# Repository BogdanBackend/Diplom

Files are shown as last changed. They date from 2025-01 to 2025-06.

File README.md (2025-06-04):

Автоматизований портативний комплекс виявлення та аналізу радіосигналів

---

A1:

* [Збірне креслення](pdf/A1/Assem.pdf)
* [Бокс креслення](pdf/A1/Box.pdf)
* [Електрична креслення](pdf/A1/CM5IO.pdf)
* [Експеремент плакат](pdf/A1/A1_experiment.drawio.pdf)
* [Плата плакат](pdf/A1/PCB.pdf)

A4:

* [Записка](pdf/doc.pdf)
* [Захис екрану креслення](pdf/A4/Top.pdf)
* [Захист роз'ємів креслення](pdf/A4/Cover.pdf)
* [Специфікація](pdf/A4/Специфікація.pdf)
* [Звіт плагіату](pdf/A4/Plagiarism.pdf)

---

# __[ЗМІСТ](docs/README.md)__

* [DOCx проміжковий файл розділів](docs/out/doc_dev.docx)

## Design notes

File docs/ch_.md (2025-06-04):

# ПЕРЕЛІК УМОВНИХ ПОЗНАЧЕНЬ ТА СКОРОЧЧЕНЬ

АПКВАР — автоматизований портативний комплекс виявлення та аналізу радіосигналів.

SDR (англ. *Software Defined Radio*) — програмно-визначуване радіо.

RF (англ. *Radio Frequency*) — радіочастота.

DSP (англ. *Digital Signal Processing*) — цифрова обробка сигналів.

FFT (англ. *Fast Fourier Transform*) — швидке перетворення Фур’є.

AGC (англ. *Automatic Gain Control*) — автоматичне регулювання підсилення.

ADC (англ. *Analog-to-Digital Converter*) — аналого-цифровий перетворювач.

DAC (англ. *Digital-to-Analog Converter*) — цифро-аналоговий перетворювач.

BMS (англ. *Battery Management System*) — система керування акумулятором.

Li-ion — літій-іонний акумулятор.

Li-Pol — літій-полімерний акумулятор.

GNSS (англ. *Global Navigation Satellite System*) — глобальна навігаційна супутникова система.

GPS (англ. *Global Positioning System*) — супутникова система позиціонування.

UART (англ. *Universal Asynchronous Receiver-Transmitter*) — універсальний асинхронний приймач-передавач.

I2C (англ. *Inter-Integrated Circuit*) — послідовний інтерфейс для зв'язку мікросхем.

SPI (англ. *Serial Peripheral Interface*) — серійний периферійний інтерфейс.

USB (англ. *Universal Serial Bus*) — універсальна послідовна шина.

HDMI (англ. *High-Definition Multimedia Interface*) — мультимедійний інтерфейс високої чіткості.

PCIe (англ. *Peripheral Component Interconnect Express*) — високошвидкісний інтерфейс підключення модулів.

M.2 компактний роз’єм для підключення накопичувачів, модулів Wi-Fi та ін..

SSD (англ. *Solid State Drive*) — твердотільний накопичувач.

SD карта пам’яті формату Secure Digital.

GPIO (англ. *General Purpose Input/Output*) — загальні виводи введення/виведення.

DSI (англ. *Display Serial Interface*) — інтерфейс підключення дисплеїв.

CSI (англ. *Camera Serial Interface*) — інтерфейс підключення камер.

PoE (англ. *Power over Ethernet*) — живлення через Ethernet-кабель.

ADS-B (англ. *Automatic Dependent Surveillance–Broadcast*) — авіаційна система спостереження.

ISM (англ. *Industrial, Scientific and Medical*) — безліцензійний радіочастотний діапазон.

TX (англ. *Transmit*) — передача сигналу.

RX (англ. *Receive*) — прийом сигналу.

IQ (англ. *In-phase and Quadrature*) — представлення сигналів у комплексній формі (реальна + уявна частина).

CW (англ. *Continuous Wave*) — неперервна хвиля (морзянка).

SSB (англ. *Single Side Band*) — односмугова модуляція.

AM (англ. *Amplitude Modulation*) — амплітудна модуляція.

FM (англ. *Frequency Modulation*) — частотна модуляція.

DC (англ. *Direct Current*) — постійний струм.

EMI (англ. *Electromagnetic Interference*) — електромагнітні завади.

PLD (англ. *Programmable Logic Device*) — програмований логічний пристрій.

FPGA (англ. *Field-Programmable Gate Array*) — програмована логічна матриця.

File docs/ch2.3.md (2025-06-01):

## Розробка електричної принципової схеми

В основі розроблюваної системи лежить процесорний модуль Raspberry Pi Compute Module 5. Цей модуль є центральним елементом, що забезпечує обробку даних та керування всіма функціями пристрою.

### Процесорний модуль та його інтерфейси:

Для розробки друкованої плати ніобхідно правильно викоритовувати ніжки процесорного модуля та розуміти його можливості. 

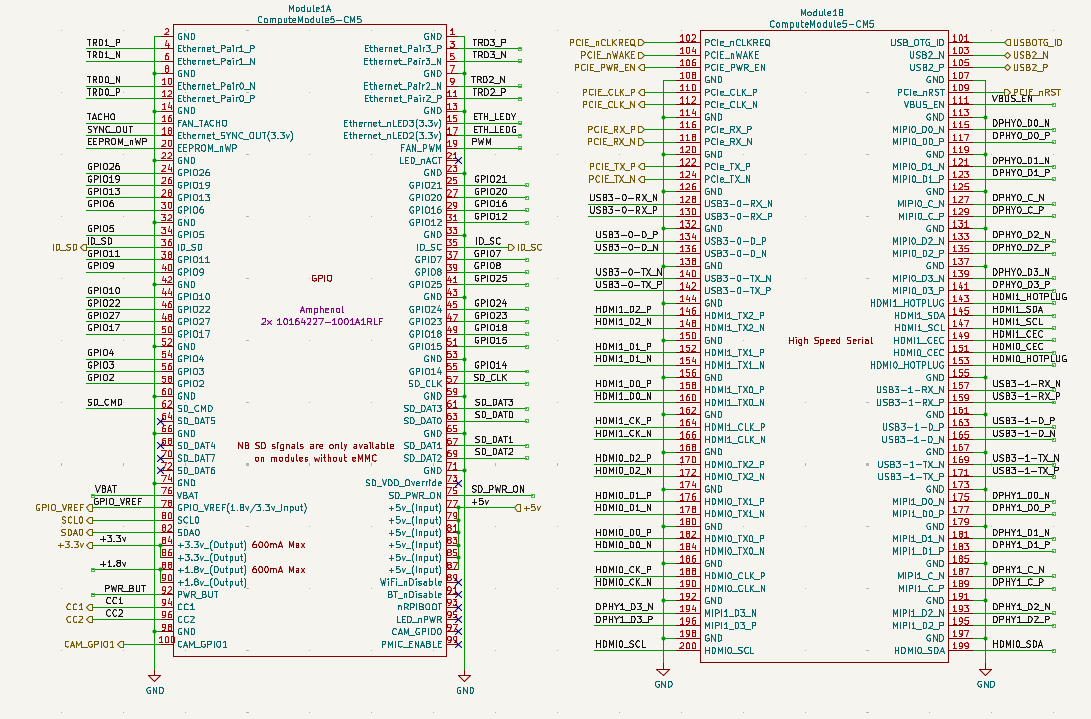
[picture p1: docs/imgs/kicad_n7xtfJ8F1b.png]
Ніжки процесорного модуля RPi Computer Module w=14


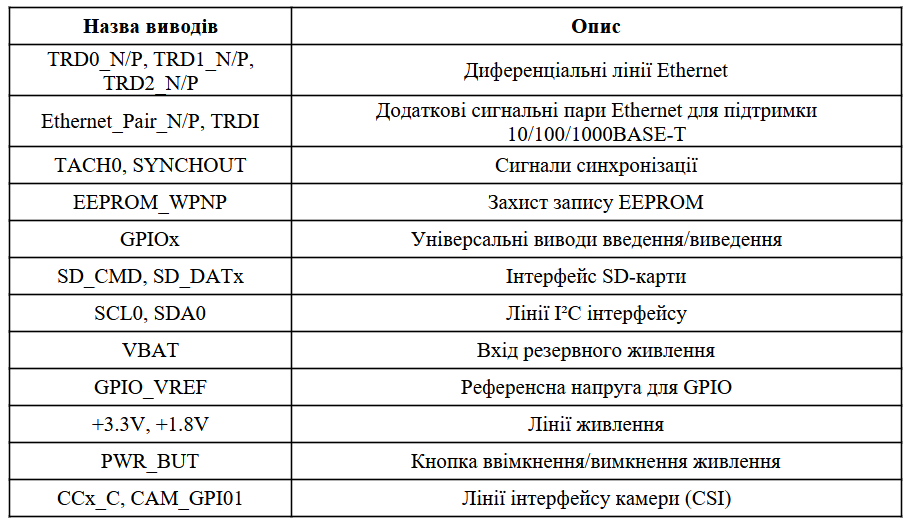
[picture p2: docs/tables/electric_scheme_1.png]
Table: Виводи з лівого боку RPi CM w=14


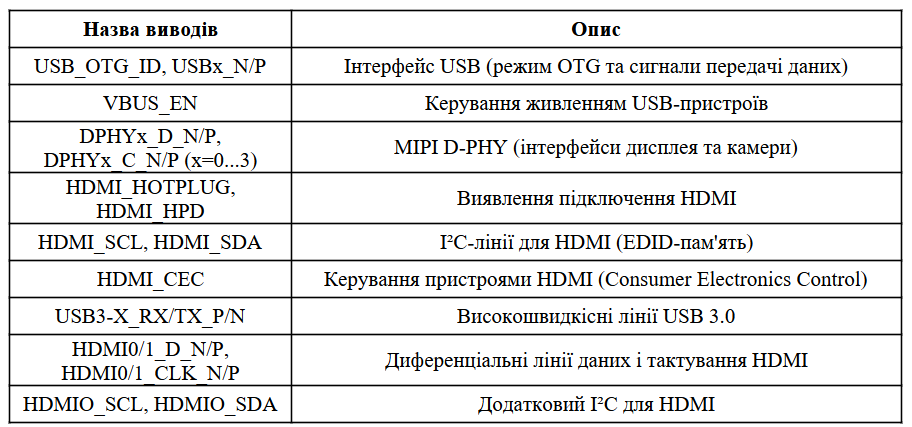
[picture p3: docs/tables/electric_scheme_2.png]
Table: Виводи з правого боку RPi CM w=14


### Організація кола живлення

Надійна система живлення є критично важливою для стабільної роботи будь-якого електронного пристрою. Система живлення розроблена для роботи від зовнішнього джерела постійного струму та включає кілька етапів перетворення та стабілізації напруги.

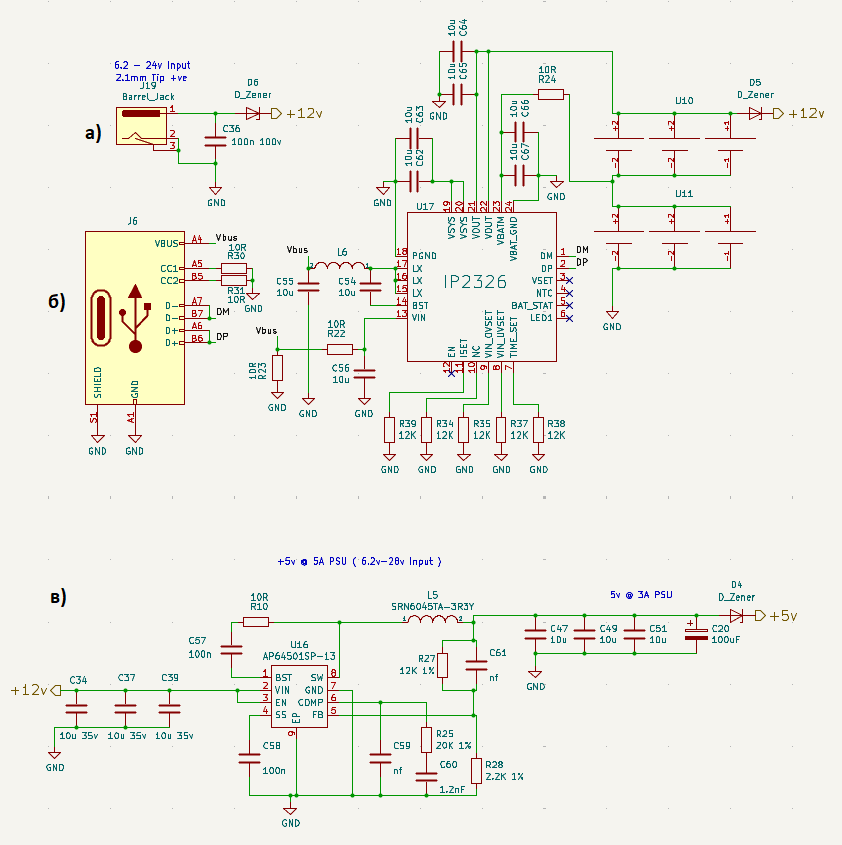
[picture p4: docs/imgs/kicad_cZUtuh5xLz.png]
Кола живлення: a) роз'єм живлення, б) роз'єм зяряду АКБ, в) перетворювач напруги w=14


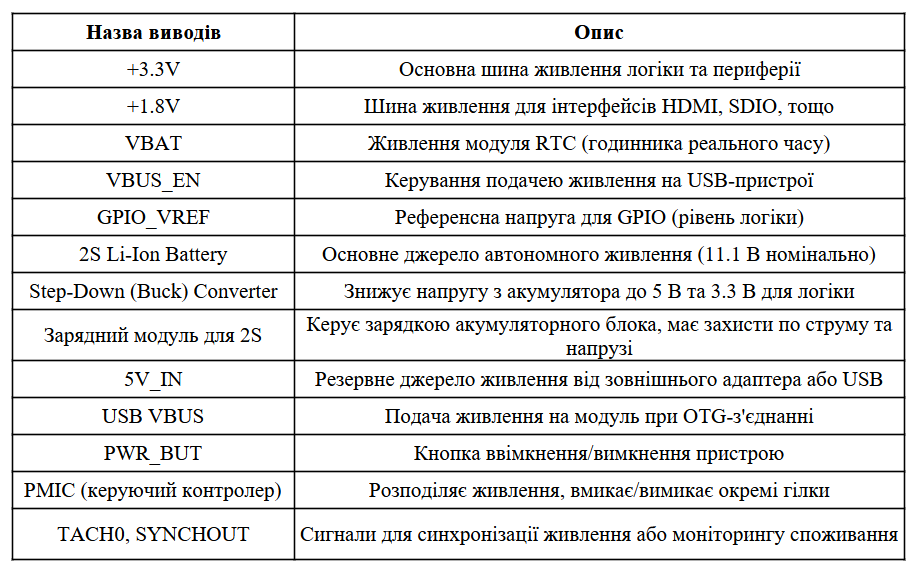
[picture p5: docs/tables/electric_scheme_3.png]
Table: Кола живлення w=14


Кола фільтрації та розв'язки:

По всій схемі розкидані конденсатори малої ємності (наприклад, 10n, 100n, 10u), які служать для блокування високочастотних шумів (decoupling capacitors) та згладжування пульсацій на лініях живлення поблизу мікросхем (C64, C65, C67, C68 поблизу U17). Це допомагає забезпечити стабільне та чисте живлення для чутливих цифрових та аналогових схем.

### Реалізація інтерфейсів та роз'ємів

Вибір конкретних типів інтерфейсів базувався на їх поширеності, енергоспоживанні та підтримці сучасними мікроконтролерами і процесорними модулями. Кожен інтерфейс реалізований через відповідні роз’єми та підключений до контролера через спеціалізовані сигнальні лінії, що дозволяє ефективно передавати дані, керувати пристроями і підключати додаткові модулі
>>> Analog Devices. Software-Defined Radio Handbook. [Електронний ресурс]. – Analog Devices, Inc. – Режим доступу: https://www.analog.com/media/en/technical-documentation/handbooks/SDR_Handbook.pdf
.

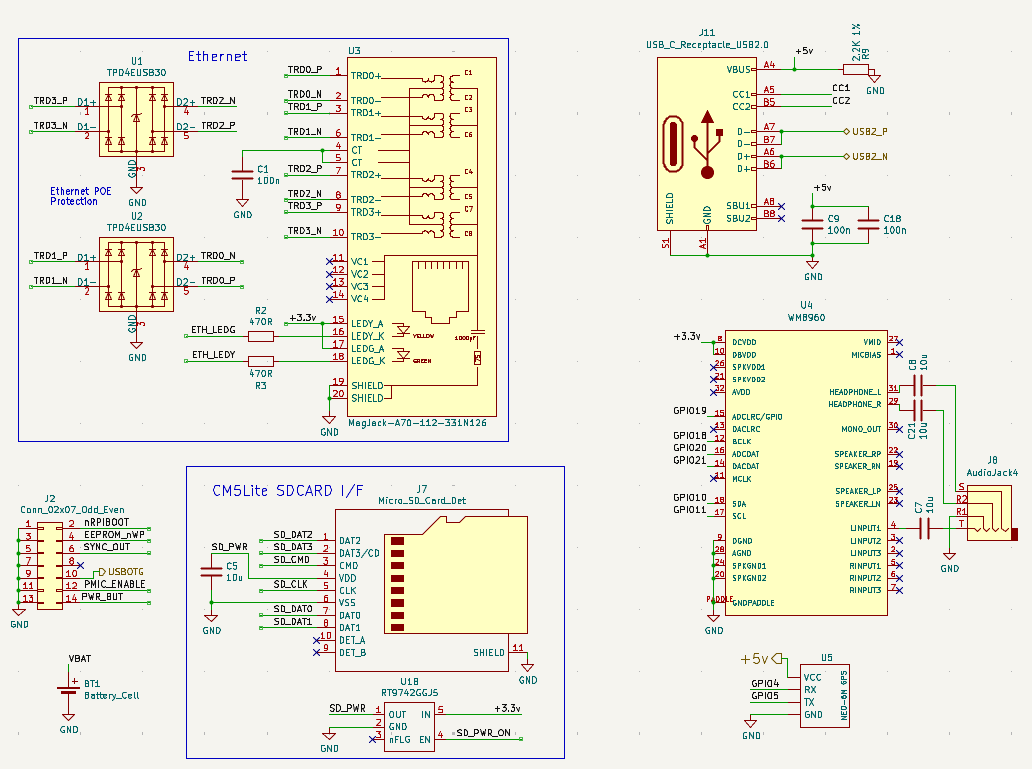
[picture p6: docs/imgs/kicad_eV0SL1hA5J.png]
Роз'єми Type C, Ethernet, MicroSD Audio, GPS w=14


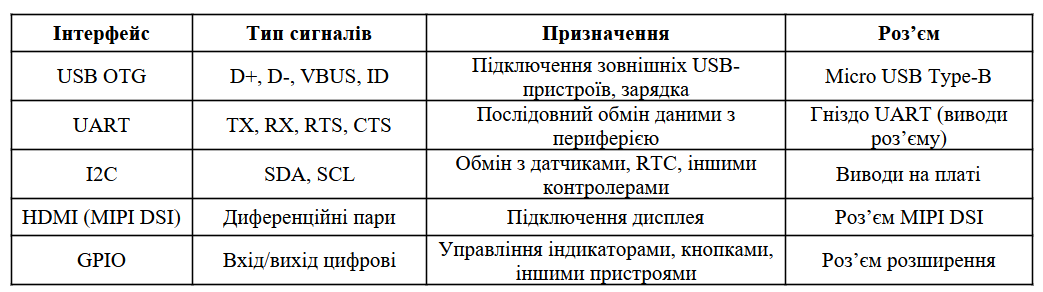
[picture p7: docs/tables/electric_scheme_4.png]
Table: Основні апаратні інтерфейси w=14


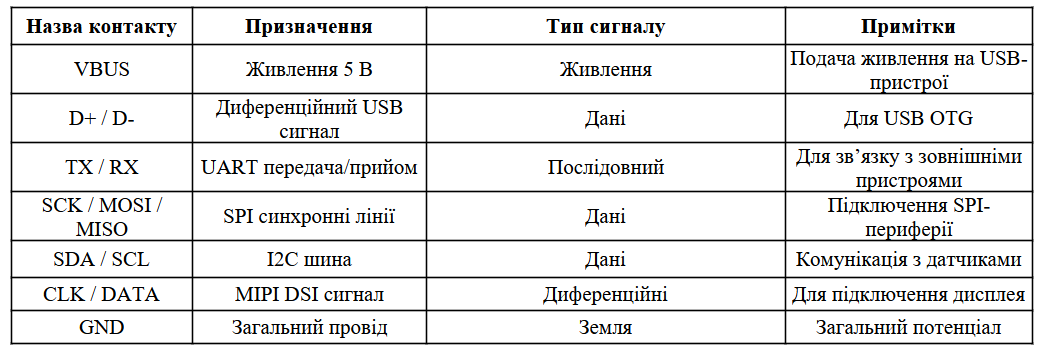
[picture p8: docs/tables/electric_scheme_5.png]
Table: Опис контактів роз’ємів w=14


### Реалізація високошвидкісних інтерфейсів та роз'ємів

Такі інтерфейси застосовуються для підключення дисплеїв, периферійних модулів, камер, а також для обміну даними з зовнішніми пристроями. Вибір інтерфейсів базується на стандартах, які підтримують сучасні процесорні модулі, та забезпечують надійний фізичний рівень передачі даних.

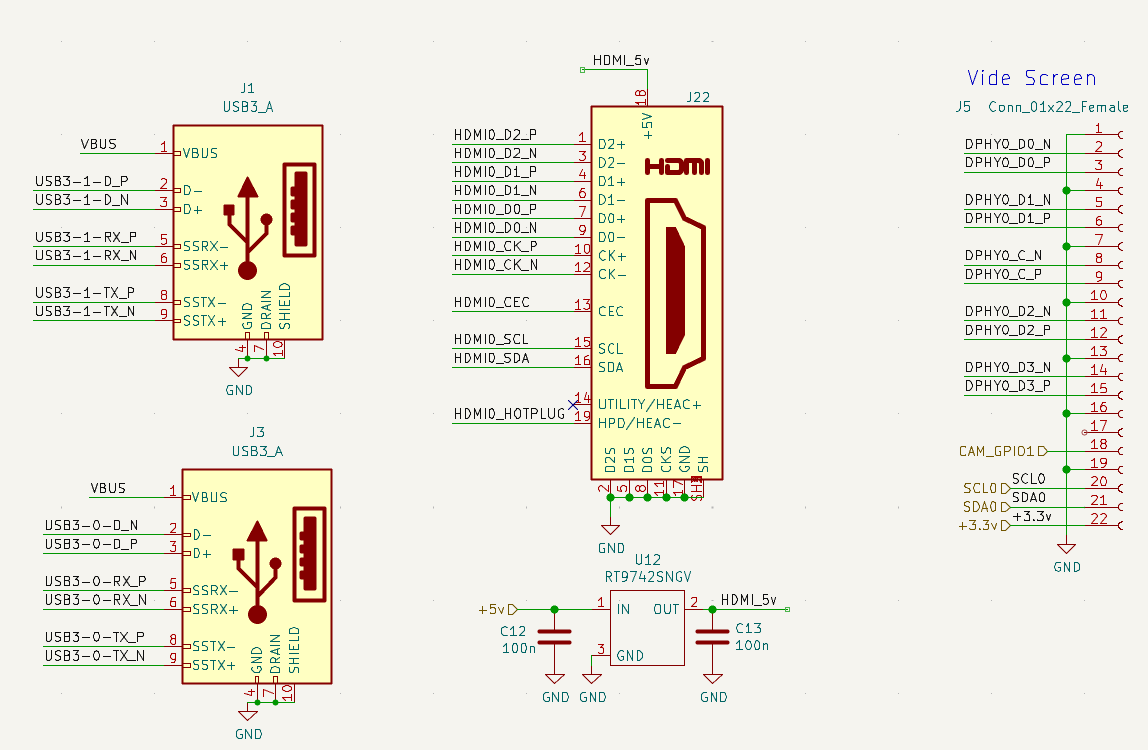
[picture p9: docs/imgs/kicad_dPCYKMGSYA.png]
Роз'єми USB3, HDMI та екран w=14


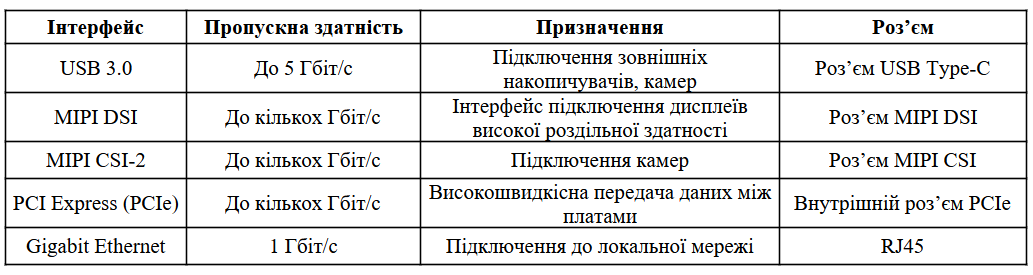
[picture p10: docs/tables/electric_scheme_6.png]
Table: Високошвидкісні інтерфейси та їх характеристики w=14


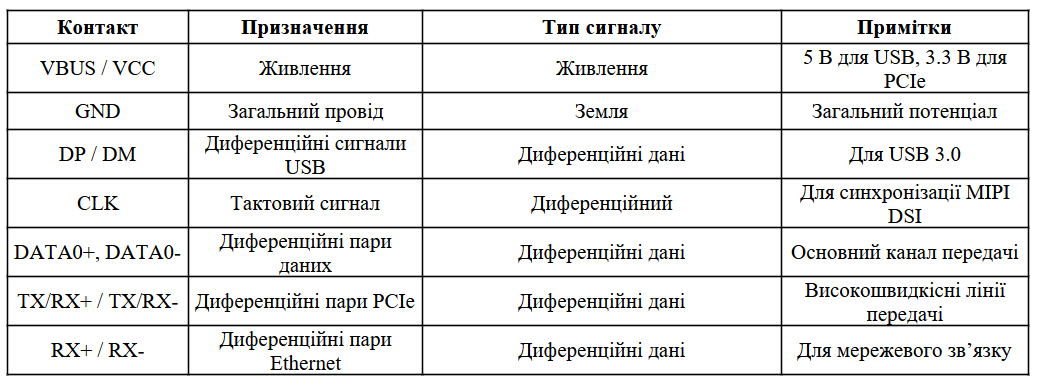
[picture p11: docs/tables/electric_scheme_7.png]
Table: Основні контакти високошвидкісних роз’ємів w=14


### Реалізація інтерфейсу M2

Інтерфейс M.2 (раніше відомий як Next Generation Form Factor, NGFF) є сучасним високошвидкісним роз’ємом, призначеним для підключення різноманітних модулів розширення, таких як SSD накопичувачі, модулі Wi-Fi, Bluetooth, LTE та інші периферійні пристрої. Інтерфейс підтримує різні протоколи передачі даних, зокрема PCI Express, SATA та USB, що забезпечує гнучкість у виборі та інтеграції компонентів.

M.2 має компактний форм-фактор, що дозволяє ефективно використовувати простір у портативних пристроях та ноутбуках, а також забезпечує високу швидкість передачі даних завдяки підтримці ліній PCIe 3.0 і вище.

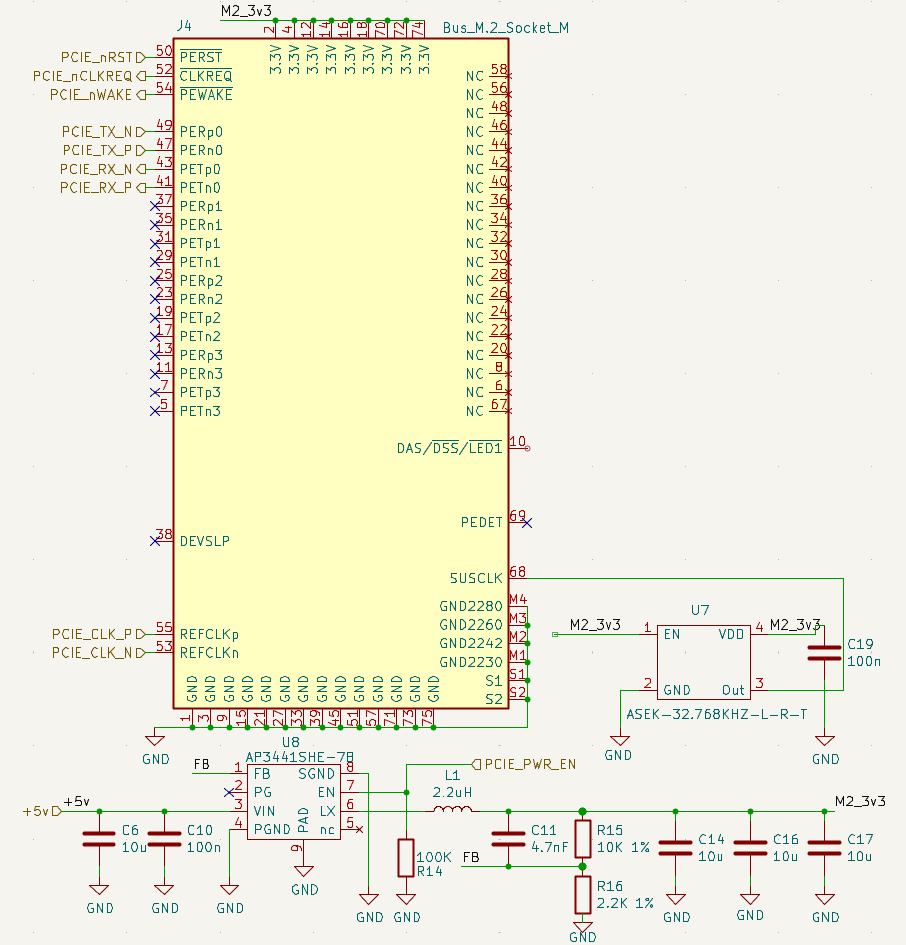
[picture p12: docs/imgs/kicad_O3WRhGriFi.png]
M2 SSD w=14


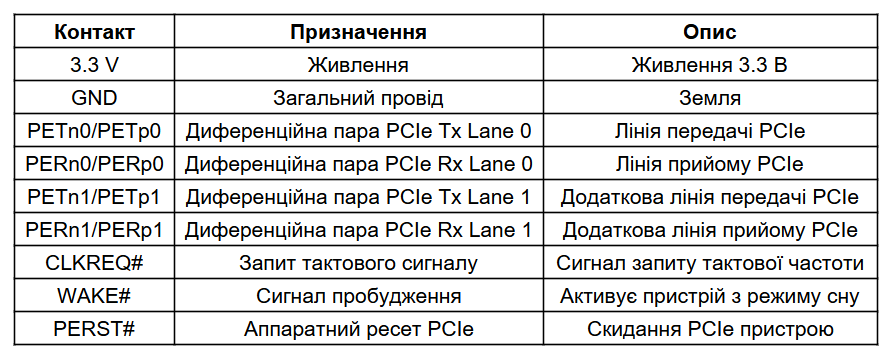
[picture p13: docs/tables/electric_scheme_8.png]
Table: Основні контакти роз’єму M.2 (Key M) w=14


### Загальна компоновка та 3D вигляд друкованої плати

Після розробки принципової електричної схеми наступним етапом є компоновка компонентів на друкованій платі (PCB) та її фізичне проектування. Цей підрозділ надає 3D вигляд розробленої плати, демонструючи розташування ключових функціональних блоків та роз'ємів, що забезпечує інтуїтивне розуміння фізичної реалізації пристрою.

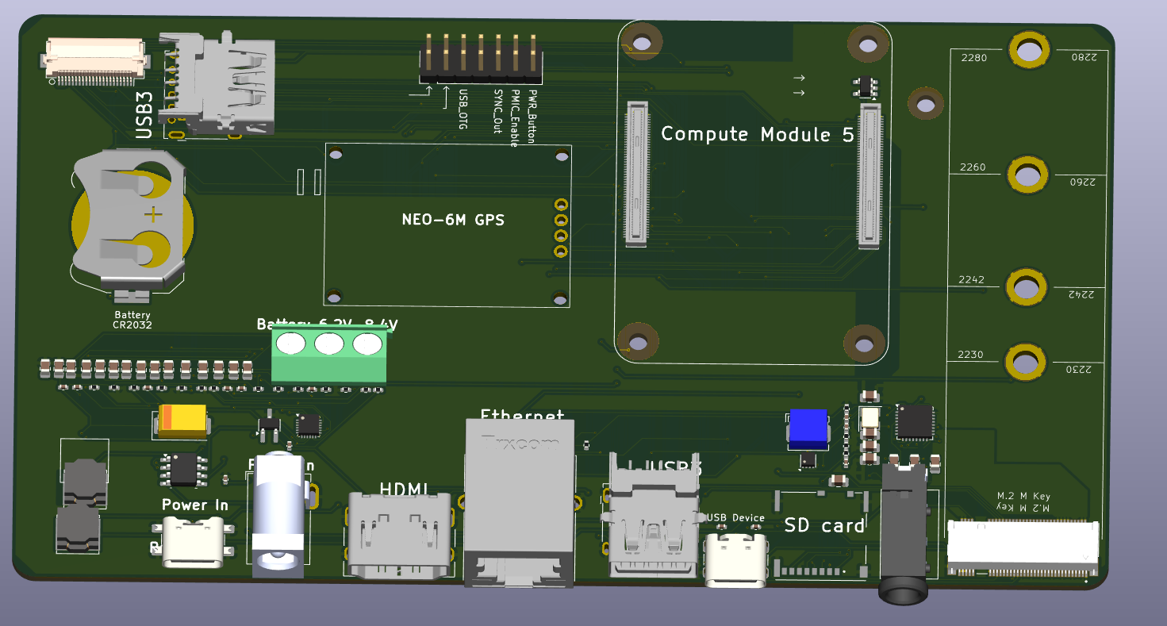
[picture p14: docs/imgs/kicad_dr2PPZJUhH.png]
ЗД вигляд друкованої плати w=14


<!-- Ключові елементи та їх розташування на платі:

Процесорний модуль (Compute Module 5):
    Розташований у верхній правій частині плати. Це центральний елемент, що підключається до системного роз'єму (SO-DIMM-подібний роз'єм). Його близьке розташування до високошвидкісних інтерфейсів (таких як HDMI, MIPI D-PHY, PCIe) мінімізує довжину доріжок, що критично для цілісності сигналу.

Роз'єми USB 3.0 (USB3):
    Два роз'єми USB 3.0 розташовані у верхній лівій частині плати. Це дозволяє зручно підключати зовнішні високошвидкісні периферійні пристрої, такі як накопичувачі або камери.

GPS-модуль (NEO-6M GPS):
    Розташований у центральній лівій частині плати. Ймовірно, це модуль UBLOX NEO-6M, що забезпечує функціональність визначення місцезнаходження. Його розташування на краю плати або в зоні з мінімальними перешкодами допомагає покращити прийом супутникового сигналу. Поруч, імовірно, знаходиться роз'єм для зовнішньої GPS-антени (маленький золотий роз'єм).

Кола живлення (Power In, Battery CR2032, Battery 6.2V):
    "Power In" (Barrel Jack): Розташований у нижній лівій частині плати. Це основний вхід для живлення пристрою від зовнішнього адаптера.
    "Battery CR2032": Тримач для батареї CR2032, ймовірно, для живлення годинника реального часу (RTC) процесорного модуля. Розташований біля роз'ємів USB3.
    "Battery 6.2V-24V": Гвинтові клеми або аналогічний роз'єм для підключення зовнішнього джерела живлення в діапазоні 6.2В-24В, що забезпечує гнучкість у виборі джерела живлення. Розташований у верхній центральній частині плати.
    Навколо цих роз'ємів розташовані компоненти, що відповідають за стабілізацію та фільтрацію живлення, як описано в підрозділі 2.2.

Інтерфейси Ethernet, HDMI, USB Device, SD Card:
    Ethernet: Роз'єм RJ45 для дротового мережевого підключення.
    HDMI: Роз'єм для підключення зовнішнього дисплея.
    Type-C: може використовуватися як для живлення, так і для підключення пристрою в режимі USB-пристрою (наприклад, для завантаження ОС або дебагування).
    SD Card: Слот для MicroSD-карти, що служить для зберігання операційної системи та даних.

M.2 M Key:
    Роз'єм M.2 M Key розташований у нижній правій частині плати. Це дозволяє підключати високошвидкісні NVMe SSD або інші сумісні M.2 модулі (наприклад, 4G/5G модеми), значно розширюючи можливості пристрою. -->

<!-- 
Висновок до розділу 2.3

Компоновка друкованої плати виконана з урахуванням оптимального розміщення компонентів для досягнення високої функціональності та надійності. Центральне розташування процесорного модуля та грамотне розміщення високошвидкісних інтерфейсів, таких як PCIe, HDMI та USB 3.0, є ключовим для забезпечення цілісності сигналу. Інтегровані рішення для живлення та захисту, а також підтримка широкого спектру периферійних інтерфейсів, роблять цю плату гнучким та потужним рішенням для різних вбудованих застосувань. Цей 3D вигляд наочно демонструє результати етапу розробки принципової електричної схеми та є основою для подальшого виробництва.
 -->

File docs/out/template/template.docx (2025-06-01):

# 1 Section

## 1.1 Subsection

### 1.1.1 Subsubsection

#### 1.1.1.1 Not a subsubsubsection but a paragraph.

##### Not a subsubsubsubsection but a subparagraph.

Body Text

Default Paragraph

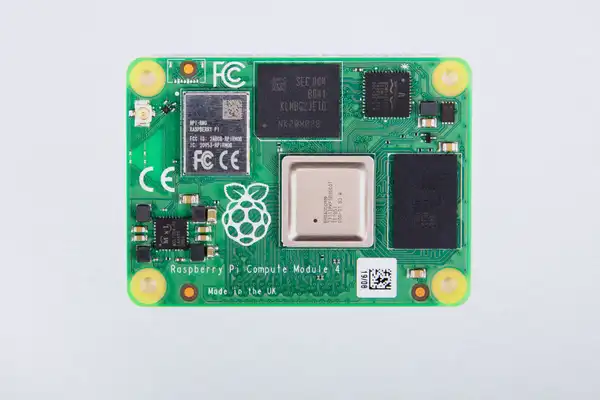
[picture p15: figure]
Рис 4.22. Raspberry Pi Compute Module 4

Image Caption

Table Caption

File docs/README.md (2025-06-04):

[Завантажити DOCX](https://github.com/Bogd-an/Diplom/raw/refs/heads/main/docs/out/doc_dev.docx)

[Github](https://github.com/Bogd-an/Diplom/blob/main/docs/README.md)

---

Зміст:

 # [1 ПЕРЕЛІК УМОВНИХ ПОЗНАЧЕНЬ ТА СКОРОЧЧЕНЬ][ref1]

 # [2 ВСТУП][ref2]

 # [3 АНАЛІТИЧНИЙ ОГЛЯД ІСНУЮЧИХ ПОРТАТИВНИХ КОМПЛЕКСІВ ВИЯВЛЕННЯ ТА АНАЛІЗУ РАДІОСИГНАЛІВ][ref3]

 ## [3.1 Опис технологій][ref4]

  ### [3.1.1 Радіостанція Hack RF One Portapack H4][ref5]

  ### [3.1.2 Радіостанція Libre SDR PLUTO][ref6]

  ### [3.1.3 Радіостанція 1.10D DSP SDR][ref7]

  ### [3.1.4 Радіостанція Amator SDR][ref8]

  ### [3.1.5 Радіостанція Malahit DSP2 2.40][ref9]

 ## [3.2 Висновок по розділу 1][ref10]

 # [4 РОЗРОБКА АВТОМАТИХОВАНОГО ПОРТАТИВНОГО КОПЛЕКСУ АНАЛІЗУ РАДІОСИГНАЛІВ][ref11]

 ## [4.1 Розробка структурної схеми][ref12]

 ## [4.2 Підбір елементної бази][ref13]

  ### [4.2.1 Антени][ref14]

  ### [4.2.2 Радіо модуль][ref15]

  ### [4.2.3 Обчислювальний модуль][ref16]

  ### [4.2.4 GPS модуль][ref17]

  ### [4.2.5 Пам'ть постійного зберігання][ref18]

  ### [4.2.6 Сенсорний дисплей][ref19]

  ### [4.2.7 Модуль живлення][ref20]

  ### [4.2.8 Материнська плата][ref21]

 ## [4.3 Розробка електричної принципової схеми][ref22]

  ### [4.3.1 Процесорний модуль та його інтерфейси:][ref23]

  ### [4.3.2 Організація кола живлення][ref24]

  ### [4.3.3 Реалізація інтерфейсів та роз'ємів][ref25]

  ### [4.3.4 Реалізація високошвидкісних інтерфейсів та роз'ємів][ref26]

  ### [4.3.5 Реалізація інтерфейсу M2][ref27]

  ### [4.3.6 Загальна компоновка та 3D вигляд друкованої плати][ref28]

 ## [4.4 Розробка корпусу][ref29]

 ## [4.5 Висновок по розділу  2][ref30]

 # [5 МЕТОДОЛОГІЯ РОБОТИ АПКВАР][ref31]

 ## [5.1 Загальні принципи роботи SDR][ref32]

 ## [5.2 Приймання та обробка радіосигналів за допомогою технології SDR][ref33]

 ## [5.3 Висновок по розділу 3][ref34]

 # [6 ЕКСПЕРИМЕНТАЛЬНЕ ВИПРОБУВАННЯ][ref35]

 ## [6.1 Прийом аналогового радіосигналу за допомогою портативної рації та SDR-приймача][ref36]

 ## [6.2 Прийом супутникових зображень][ref37]

 ## [6.3 Висновок по розділу 4][ref38]

 # [7 ВИСНОВОК][ref39]

<!-- Links -->
[ref1]: ch_.md#перелік-умовних-позначень-та-скороччень
[ref2]: ch0.md#**вступ**
[ref3]: ch1.md#**аналітичний-огляд-існуючих-портативних-комплексів-виявлення-та-аналізу-радіосигналів**
[ref4]: ch1.md#опис-технологій
[ref5]: ch1.md#радіостанція-hack-rf-one-portapack-h4
[ref6]: ch1.md#радіостанція-libre-sdr-pluto
[ref7]: ch1.md#радіостанція-1.10d-dsp-sdr
[ref8]: ch1.md#радіостанція-amator-sdr
[ref9]: ch1.md#радіостанція-malahit-dsp2-2.40
[ref10]: ch1.md#висновок-по-розділу-1
[ref11]: ch2.1.md#**розробка-автоматихованого-портативного-коплексу-аналізу-радіосигналів**
[ref12]: ch2.1.md#розробка-структурної-схеми
[ref13]: ch2.2.md#підбір-елементної-бази
[ref14]: ch2.2.md#антени
[ref15]: ch2.2.md#радіо-модуль
[ref16]: ch2.2.md#обчислювальний-модуль
[ref17]: ch2.2.md#gps-модуль
[ref18]: ch2.2.md#пам'ть-постійного-зберігання
[ref19]: ch2.2.md#сенсорний-дисплей
[ref20]: ch2.2.md#модуль-живлення
[ref21]: ch2.2.md#материнська-плата
[ref22]: ch2.3.md#розробка-електричної-принципової-схеми
[ref23]: ch2.3.md#процесорний-модуль-та-його-інтерфейси:
[ref24]: ch2.3.md#організація-кола-живлення
[ref25]: ch2.3.md#реалізація-інтерфейсів-та-роз'ємів
[ref26]: ch2.3.md#реалізація-високошвидкісних-інтерфейсів-та-роз'ємів
[ref27]: ch2.3.md#реалізація-інтерфейсу-m2
[ref28]: ch2.3.md#загальна-компоновка-та-3d-вигляд-друкованої-плати
[ref29]: ch2.4.md#розробка-корпусу
[ref30]: ch2.4.md#висновок-по-розділу--2
[ref31]: ch3.md#**методологія-роботи-апквар**
[ref32]: ch3.md#загальні-принципи-роботи-sdr
[ref33]: ch3.md#приймання-та-обробка-радіосигналів-за-допомогою-технології-sdr
[ref34]: ch3.md#висновок-по-розділу-3
[ref35]: ch4.md#експериментальне-випробування
[ref36]: ch4.md#прийом-аналогового-радіосигналу-за-допомогою-портативної-рації-та-sdr-приймача
[ref37]: ch4.md#прийом-супутникових-зображень
[ref38]: ch4.md#висновок-по-розділу-4
[ref39]: ch5.md#**висновок**

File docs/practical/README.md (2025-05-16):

Звіт з практики

* [План практики](0_plan.md)
* [Історія](1_history.md)
* [2](2.md)
* [3](3.md)
* [4](4.md)
* [5](5.md)

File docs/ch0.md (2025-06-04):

# **ВСТУП**

У сучасних умовах стрімкого розвитку інформаційних технологій, активного впровадження бездротових комунікацій та зростання вимог до автономності, мобільності й захищеності обладнання, особливу увагу приділяють компактним автономним пристроям. Такі пристрої повинні ефективно виконувати спеціалізовані завдання у складних або віддалених середовищах — незалежно від наявності інфраструктури, за обмежених ресурсів і під загрозою радіочастотних впливів чи стороннього втручання.

Однією з критично важливих функцій таких пристроїв є виявлення, прийом, обробка та аналіз радіосигналів у широкому частотному діапазоні. Це необхідно як у військовій сфері (виявлення джерел випромінювання, забезпечення захищеного зв’язку, радіорозвідка), так і в цивільних застосуваннях — від аварійно-рятувальних операцій до дослідницьких польових місій, роботи з дронами, моніторингу спектра тощо.

Через це зростає інтерес до створення відкритих, гнучких і водночас надійних технічних рішень — зокрема, до автоматизованих портативних комплексів для виявлення та аналізу радіосигналів, побудованих на основі відкритого програмного й апаратного забезпечення. Відкритість технологій у цьому контексті не лише забезпечує прозорість та безпеку, а й дозволяє адаптувати пристрій під конкретні задачі, оновлювати його та масштабувати залежно від умов застосування.

Метою цієї дипломної роботи є розробка концепції, апаратної архітектури та обґрунтування вибору елементної бази для створення автономного портативного комплексу виявлення та аналізу радіосигналів. Пристрій має відповідати сучасним вимогам щодо енергоефективності, компактності, багатофункціональності, можливості роботи в реальному часі, захищеності та відкритості.

Для досягнення поставленої мети в роботі виконано:

* аналітичний огляд сучасних програмно-визначуваних радіосистем (SDR) та порівняльний аналіз їх характеристик;
* розробку структурної схеми комплексу з урахуванням вимог до функціоналу та експлуатаційних умов;
* підбір оптимальної елементної бази для побудови комплексу;
* обґрунтування вибору ключових компонентів системи;
* опис програмного забезпечення та його ролі в забезпеченні функціональності комплексу.

Об’єктом дослідження є технічні рішення та апаратно-програмні засоби для побудови SDR-комплексів.

Предметом дослідження виступає архітектура та елементна база автоматизованого портативного комплексу для виявлення і аналізу радіосигналів.

Наукова новизна полягає у поєднанні відкритої архітектури, сучасних SDR-технологій і модульного підходу до побудови польового пристрою з можливістю адаптації до конкретних сценаріїв використання.

Практична значущість результатів полягає в можливості створення на їх основі реального функціонального зразка пристрою, придатного для автономного використання в польових умовах — як у професійних, так і аматорських або освітніх цілях.

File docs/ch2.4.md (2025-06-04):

##  Розробка корпусу

Корпус є важливою складовою будь-якого електронного пристрою, оскільки забезпечує механічний захист внутрішніх компонентів від впливу зовнішнього середовища, пилу, вологи та механічних пошкоджень. Окрім захисної функції, корпус визначає ергономіку, зручність експлуатації, а також сприяє ефективному розміщенню та охолодженню елементів системи. Якісно спроєктований корпус дозволяє забезпечити надійність, довговічність і безпеку роботи пристрою в різних умовах.

Для створення корпусу було застосовано програмний комплекс [SolidWorks](https://www.solidworks.com/). Це CAD-система, яка дозволяє моделювати тривимірні об'єкти, здійснювати віртуальне компонування всіх деталей, перевіряти їхню взаємодію та вдосконалювати конструкцію ще до виготовлення прототипу. SolidWorks забезпечує оперативне внесення змін у проєкт, автоматичне формування виробничих креслень і виконання базового аналізу міцності, що суттєво підвищує точність і якість розробки корпусу.

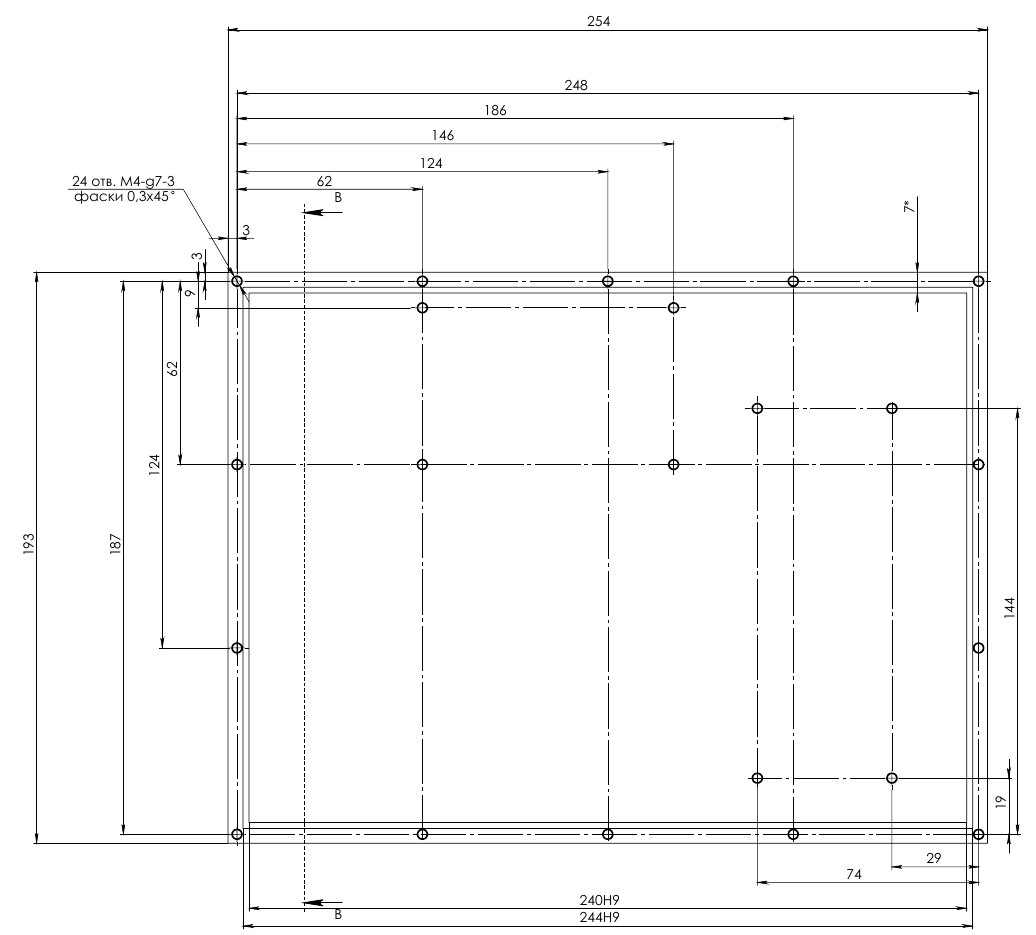
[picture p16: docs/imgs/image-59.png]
Бокс w=14


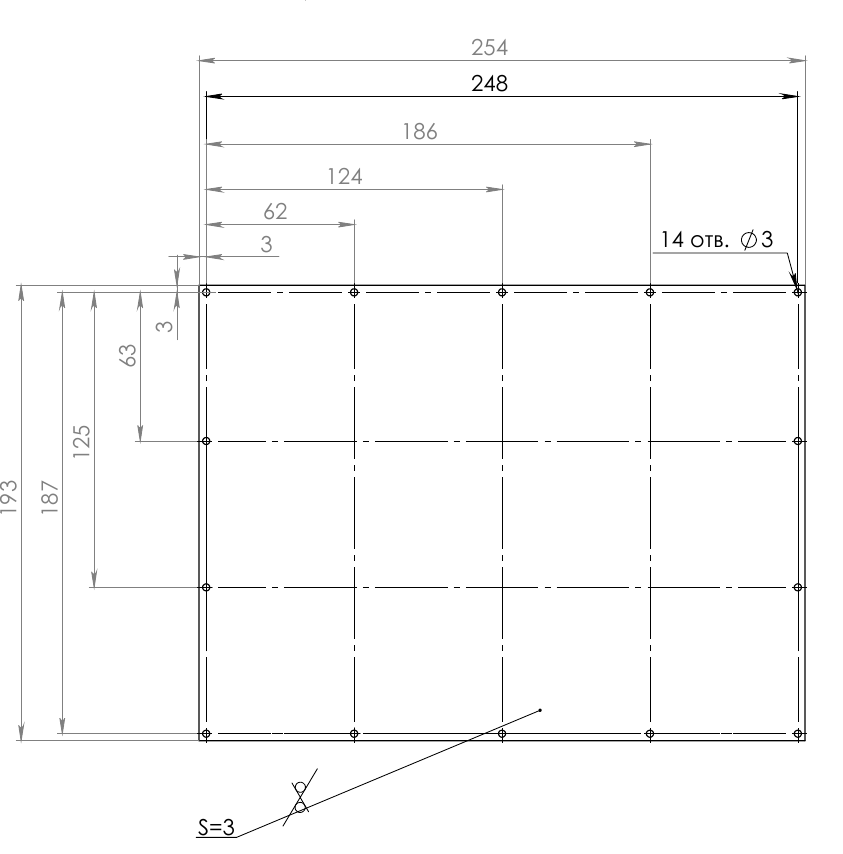
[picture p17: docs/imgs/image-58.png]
Захист екрану w=12


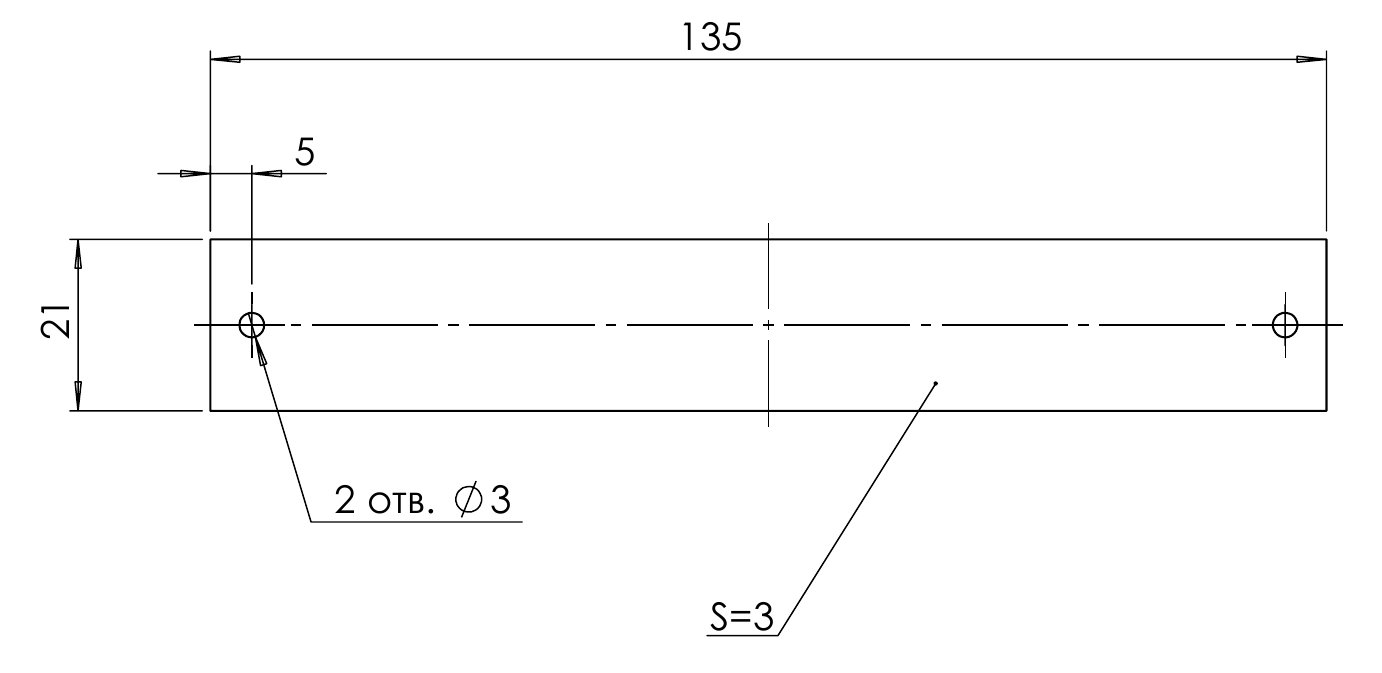
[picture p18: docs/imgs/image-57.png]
Захист роз'ємів w=12


## Висновок по розділу  2

В межах розділу виконано побудову структурної схеми, підбір та обґрунтування елементної бази, створення електричної принципової схеми й розробку конструкції корпусу пристрою.

На етапі розробки структурної схеми визначено основні функціональні вузли комплексу та їх взаємозв’язки. Сформовано архітектуру пристрою з центральним обчислювальним модулем, радіоприймачем, системами навігації, живлення, інтерфейсами введення-виведення, сенсорним дисплеєм і підсистемою збереження даних.

Особливу увагу приділено підбору елементної бази, оскільки саме вона визначає функціональність, енергоефективність, масштабованість і надійність системи. Зокрема:

* Радіомодуль BladeRF обрано за його широкий частотний діапазон, підтримку як прийому, так і передачі, відкритість ПЗ та здатність до роботи в польових умовах.
* Обчислювальний модуль Raspberry Pi Compute Module 5 забезпечує високу продуктивність, підтримку Linux, модульність та інтеграцію з різноманітними інтерфейсами, включно з GPIO, HDMI, USB і MIPI.
* GPS-модуль u-blox NEO-M8N надає підтримку кількох GNSS-систем, високу точність позиціонування та стабільність навіть у складних умовах прийому.
* SSD-диск M.2 SATA (наприклад, Transcend MTS420S 240GB) обрано для забезпечення швидкого зберігання ОС, даних спектрального аналізу та логів.
* Сенсорний дисплей Waveshare 10.1" HDMI забезпечує зручний багатоточковий інтерфейс користувача, просте підключення та високу роздільну здатність.
* Модуль живлення на базі 3S Li-Ion батарей із відповідною системою керування зарядом і захистом забезпечує автономну роботу пристрою в польових умовах.
* Материнська плата реалізована як багатошарова друкована плата з розведенням живлення, інтерфейсів та екрануванням, адаптована до складного середовища експлуатації.

Кожен компонент було обрано на основі порівняльного аналізу варіантів за технічними характеристиками, вартістю, наявністю підтримки, сумісністю та придатністю до автономного застосування. Комплекс характеризується відкритістю, гнучкістю та можливістю оновлення й модернізації.

На основі підібраної елементної бази створено детальну електричну принципову схему, що відображає логіку роботи та з’єднання всіх модулів системи. Окремо спроєктовано підсистему живлення, інтерфейси периферійних пристроїв, а також канали високошвидкісного обміну даними та інтерфейс M.2 для зберігання інформації.

У завершальній частині розділу виконано розробку корпусу пристрою, який відповідає вимогам до захисту від пилу, вологи, вібрацій та механічних навантажень. Враховано ергономічні параметри, теплообмін, доступ до портів і модульність внутрішнього компонування.

Загалом, проведена робота дозволила створити цілісну апаратну платформу для реалізації функціонального, портативного та енергоефективного комплексу аналізу радіосигналів з відкритою архітектурою.

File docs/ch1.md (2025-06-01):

# **АНАЛІТИЧНИЙ ОГЛЯД ІСНУЮЧИХ ПОРТАТИВНИХ КОМПЛЕКСІВ ВИЯВЛЕННЯ ТА АНАЛІЗУ РАДІОСИГНАЛІВ**

У цьому розділі розглядаються сучасні портативні комплекси для виявлення, аналізу та обробки радіосигналів, що використовуються для моніторингу, тестування та дослідження у сфері радіозв'язку. Особлива увага приділяється програмно-визначуваним радіостанціям (SDR), які забезпечують гнучкість, багатофункціональність та робота у різному діапазоні частот.

## Опис технологій

Програмно-визначуване радіо (SDR, Software Defined Radio)
>>> ULVERSOY, Tore. Software defined radio: Challenges and opportunities. IEEE Communications Surveys & Tutorials, 2010, 12.4: 531-550.
— це підхід, при якому більшість функцій традиційного радіоапаратного забезпечення (наприклад, фільтрація, демодуляція, обробка сигналу) реалізується програмно, а не апаратно. Це дозволяє змінювати режими роботи пристрою, підтримувати різні протоколи та стандарти без необхідності заміни апаратної частини. 

<!-- Якщо взагалом уявити обладнання формування сигналу у приладах до SDR-технології, то це досить громіздкі пристрої (генератори, фільтри, кодери, декодери та інш), котрі мали порівняно великі розміри та коштували дуже дорого. І, якщо треба змінити певні параметри сигналу, то це у багатьох випадках потребувало безпосередньої фізичної зміни обладнання (заміни елементів радіосхем, блоків в пристрої і навіть цілих модулів радіостанцій) або фізичного настроювання оператором. Зі збільшеннями потреб суспільства ці необхідні зміни ставали більш неможливими і потребували виробництва іншого обладнання під необхідні вимоги формування/прийняття сигналу для відправлення і прийому відповідно. SDR-технологія використовує  персональний комп'ютер як центр радіостанції, завдяки чому практично всі процеси обробки сигналу виконує програмне забезпечення, яке обробляє (формує, кодує/декодує, фільтрує, модулює/демодулює…) сигнал. Мета такого підходу — створити систему, яка може приймати та передавати практично будь-які радіосигнали у широкому діапазоні частот за допомогою програмного забезпечення. Саме ця можливість – програмного керування і стала причиною розвитку приладів, що використовують SDR-технологію. -->

Основні переваги SDR.

- Універсальність — можливість роботи з різними типами сигналів та протоколів.
- Гнучкість — швидка зміна налаштувань, частот, режимів роботи через програмне забезпечення.
- Компактність і портативність — сучасні SDR-пристрої мають невеликі розміри та можуть працювати автономно.
- Масштабованість — можливість оновлення функціоналу шляхом зміни або доповнення програмного забезпечення.
- Широкий спектр застосування — від моніторингу стільникових мереж і аналізу бездротових протоколів до тестування безпеки, наукових досліджень та навчання.

SDR-комплекси дозволяють здійснювати прийом, аналіз, запис, відтворення та передачу радіосигналів у широкому частотному діапазоні, що робить їх незамінними інструментами для фахівців у сфері радіозв'язку, радіоаматорів, дослідників та інженерів.

Розробка приладу у моїй дипломній роботі мусить грунтуватися на можливостях існуючих відомих пристроїв. Ці апарати порівняно недорогі, малі у розмірах, але водночас мають широкі характеристики.

### Радіостанція Hack RF One Portapack H4

Прилад HackRF One із PortaPack H4 із прошивкою Mayhem — це багатофункціональна портативна SDR-платформа, призначена для прийому, передачі й аналізу радіосигналів у широкому діапазоні частот. Пристрій базується на відкритих програмних рішеннях і може використовуватися для моніторингу мобільних мереж, дослідження бездротових стандартів, налаштування радіочастот, тестування захищеності бездротових систем та інших завдань
[HackRF One !](https://fd24.com.ua/ua/p1044872164-sdr-radiostantsiya-antennami.html).

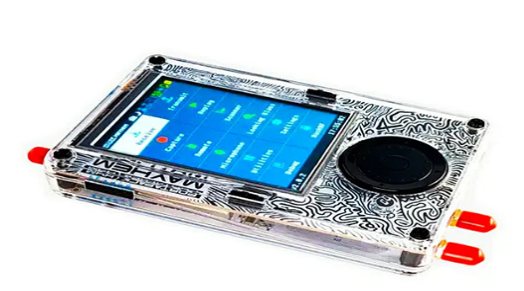
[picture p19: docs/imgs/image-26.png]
One Portapack H4 Mayhem


Оновлений модуль PortaPack H2 розширює можливості HackRF One завдяки кольоровому сенсорному дисплею, навігаційним клавішам і енкодеру для зручного управління. Встановлена прошивка Mayhem значно розширює функції аналізу, тестування та роботи з бездротовими мережами.

У порівнянні з попередньою версією, H4 отримала покращений матовий екран, порт GPIO для підключення додаткових пристроїв, дисплеїв і сенсорів, а також оновлену систему живлення: один перемикач для вмикання/вимикання, вдосконалене управління акумулятором, швидке заряджання через Type-C, відсутність витоків струму та саморозряду.

<!-- Технічні характеристики

* Режим роботи: напівдуплексний
* Робочий частотний діапазон: 1 МГц – 6 ГГц
* Частота дискретизації: від 2 до 20 MSPS
* Програмно налаштований смуговий фільтр для прийому та передачі
* Програмно кероване живлення антенного виходу (до 50 мА при 3.3 В)
* Кольоровий сенсорний дисплей з діагоналлю 3.2 дюйма
* Вбудований гучномовець
* Зручні кнопки для налаштування
* Антенний роз’єм: SMA (гніздо)
* Аудіороз’єм для гарнітури/мікрофона: 3.5 мм
* GPIO-інтерфейс для підключення зовнішніх пристроїв
* Живлення: вбудований акумулятор на 2500 мА·год
* Матеріал корпусу: пластик ABS
* Габарити: 8 × 12,5 × 2,5 см -->

### Радіостанція Libre SDR PLUTO

Прилад LibreSDR це модифікований SDR у міцному алюмінівому боксі [LibreSDR !](https://fd24.com.ua/ua/p2465955107-sdr-radiostantsiya-antennami.html).

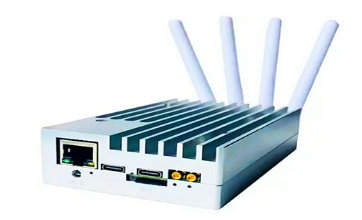
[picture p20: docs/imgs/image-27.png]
LibreSDR PLUTO з Zynq7020


Плата пристрою оснащена 8-бітовим цифро-аналоговим перетворювачем та містить низку інтерфейсних портів: два роз’єми MMCX, порт Gigabit Ethernet для передачі IQ-даних і доступу до консолі вбудованої Linux-системи, два роз’єми Type-C, слот для MicroSD-картки та чотири SMA-роз’єми. У LibreSDR інтегровано радіочастотний модуль AD9363.

<!-- Ключові технічні характеристики:

* Мікросхема: XC7Z020-2CLG400I xc7z020-2I
* RF-модуль AD9363, налаштований як AD9361 (діапазон 70 МГц ~ 6 ГГц)
* Кількість каналів: 2 на передачу, 2 на прийом
* Розрядність ЦАП/АЦП: 12 біт
* Робочий частотний діапазон: 70 МГц – 6 ГГц
* Генератор опорної частоти: VCTCXO 40 МГц, стабільність 0,5 ppm
* Система-на-кристалі: Zynq7010, FPGA: 28 Кб
* Оперативна пам’ять: 512 МБ
* FLASH-пам’ять: 32 МБ
* USB-інтерфейс: версія 2.0, підтримка OTG
* Мережевий інтерфейс: Gigabit Ethernet (1000 Мбіт/с)
* Підтримка завантаження з MicroSD-картки
* Живлення: 5 В, 2 А через MicroUSB
* Підтримка режимів дуплексу TDD і FDD
* Смуга пропускання: від 200 кГц до 20 МГц
* Корпус з алюмінієвого сплаву
* Розміри: 11,3 × 7,2 × 3 см
* Вага: 565 г -->

### Радіостанція 1.10D DSP SDR

Прилад 1.10D DSP SDR підтримує AM, SSB, NFM, WFM, CW, побудований на SDR-архітектурі з використанням RF-фронтенду msi001 для 12-бітного оцифрування сигналу та процесора stm32h743 із тактовою частотою до 480 МГц
[Приймач 1.10D DSP SDR !](https://www.joom.com/uk/products/67b2acd0683d8101ba932088?variant_id=67b2acd0683d815eba93208a).

Діапазон частот пристрою становить 10 кГц–2,0 ГГц (версія 1.10d), чутливість — 0,3 мкВ при 10 дБ до 250 МГц. Приймач оснащений подвійним антенним входом, модулем атенюатора переднього каскаду з ослабленням до 30 дБ, високим вхідним опором, покращеною чутливістю на коротких хвилях і чотирма додатковими фронтальними фільтрами. Пристрій має розширені можливості - змінна ширина фільтра, адаптивне та порогове шумозаглушення, шумоподавлення, автоматичне регулювання підсилення (AGC), еквалайзер. Корпус із друкованої плати для покращеної радіочастотної ефективності, підключення до ПК через USB для передачі даних IQ, аудіо та керування пристроєм. 

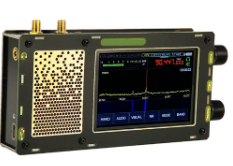
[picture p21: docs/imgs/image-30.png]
1.10D DSP SDR


<!-- Ключові технічні характеристики.

* Діапазони частот від 50 кГц до 49,999 МГц, від 50,001 МГц до 249,999 ГГц, від 400 МГц до 2 ГГц.
* Демодуляція: AM, SSB, NFM, WFM, CW.
* MCU: потужний stm32h743 із тактовою частотою 480 МГц.
* Змінна ширина фільтра, адаптивний шумоподавлювач, пороговий шумоподавлювач, шумоподавлювач, AGC, еквалайзер.
* Мікросхема демодуляції msi001.
* Акумулятор: вбудований літій-іонний акумулятор 503450, ємність: 3000 мА*год.
* Екран: 3,5-дюймовий IPS ємнісний сенсорний.
* Порт: USB, з’єднання з комп’ютером для коду, IQ та звукового зв’язку. -->

### Радіостанція Amator SDR

Прилад Amator SDR [5] забезпечує прийом кількох голосових повідомлень, підтримує прийом голосу в діапазонах SSB, AM, вузькосмугового FM, широкосмугового FM, і спрощує прийом та відтворення бездротових сигналів з пультів дистанційного керування діапазону ISM
[Радіостанція Amator SDR  1 МГц - 6 ГГц. !](https://www.joom.com/uk/products/67ea3b1a35422d011b0f5a93?variant_id=67ea3b1a35422dbc1b0f5a95).

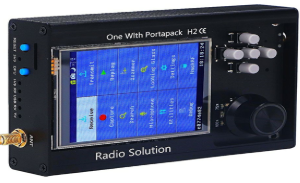
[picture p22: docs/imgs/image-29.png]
Amator SDR 1 МГц - 6 ГГц


Одна з найкращих переваг радіотрансивера полягає в тому, що він дозволяє дуже легко вловлювати та відтворювати бездротові сигнали з пультів дистанційного керування діапазону ISM. Все, що вам потрібно зробити, це зайти в меню приймача, встановити частоту клавішею пульта дистанційного керування, натиснути червону кнопку запису «R» та натиснути клавішу на пульті дистанційного керування. Потім зупиніть запис, щоб зберегти його на карту пам’яті. Тепер ви можете перейти до меню «Відтворення», вибрати щойно записаний файл і натиснути кнопку «Відтворити». Точно такий же сигнал буде передаватися по повітрю, ефективно замінюючи ваш віддалений ключ.

<!-- Прилад дає можливість прослуховувати стандартні радіосигнали NFM та WFM, підключивши динамік до 3,5-мм радіороз’єму. Прийом ADS B легко вмикається на радіопередавачі, вибравши символ індуктора та блискавки у верхньому правому куті.
Прилад Amator SDR дає змогу передавати розмову через 3,5-мм аудіороз’єм. Тому, підключивши мікрофон, ви можете просто натиснути та утримувати праву бічну кнопку, щоб здійснити дзвінок. Цей радіотрансивер оснащений 3,2-дюймовим резистивним сенсорним екраном, навігаційними перемикачами, радіо-виходами, мікрофонними входами, інтерфейсом DC 2.1 та 4-шаровим позолоченим покриттям.  -->

<!-- Ключові технічні характеристики.

* тип пристрою: радіоприймач;
* тип батареї: вбудована літієва батарея 3,7 В 2000 мА*год;
* екран: 3,2-дюймовий, 240 x 320 RGB РК-дисплей з резистивний сенсорний;
* антена прийому частотного діапазону: 1 МГц – 6 ГГц;
* матеріал корпусу: алюмінієвий сплав.

Функціональність: відтворення файлів IQ, мікрофонна FM-передача з CTCSS, декодер CTCSS, частотний менеджер (збереження та завантаження з карти пам’яті з категоріями та коментарями), файловий менеджер, програвач звукових файлів Soundboard Wave (Зберігає 8-бітні монофайли) Карта пам’яті, каталог Wav, передавач SST, передавач POCSAG, приймач декодер POCSAG, передавач Морзе (FM-тон та CW), передавачі OOK для звичайних дистанційних кодерів (PT2262, дверні дзвінки, віддалені розетки, гаражі), RDS (система радіоданих) передавачі PSN, радіотексту та групового зв’язку за часом, приймач метеорологічних радіоехолотів для M10 та M2K2, універсальний пульт дистанційного керування TouchTunes Jukebox.
Особливості:

* 4-сторонні кнопки зі стрілками, колесо прокручування та кнопки вибору;
* батарейка-таблетка для збереження налаштувань, дати й часу;
* слот для мікрокартки пам’яті для зберігання даних та коду;
* SSB, AM, вузькосмуговий FM, широкосмуговий FM-радіоприйом;
* моніторинг суден (AIS), автомобілів (TPMS), Транспондери електронних лічильників комунальних послуг (ІТРОН ЕРТ).

Цей радіоприймач має широкий спектр застосування та може використовуватися на кораблях, автомобілях, електронних лічильниках комунальних послуг, для моніторингу транспондерів тощо. -->

### Радіостанція Malahit DSP2 2.40

Прилад Malahit-DSP2 SDR, оригінальний приймач другого покоління. Найновіша прошивка версії 2.40 створила абсолютно новий оригінальний приймач Malahit-DSP2, котрий має широкий спектр застосування та може використовуватися на кораблях, автомобілях, електронних лічильниках комунальних послуг, для моніторингу транспондерів тощо
[Malahit-DSP2 SDR !](https://www.joom.com/uk/products/67399c645aa1e901d90ed87c?variant_id=67399c645aa1e9c2d90ed87e).

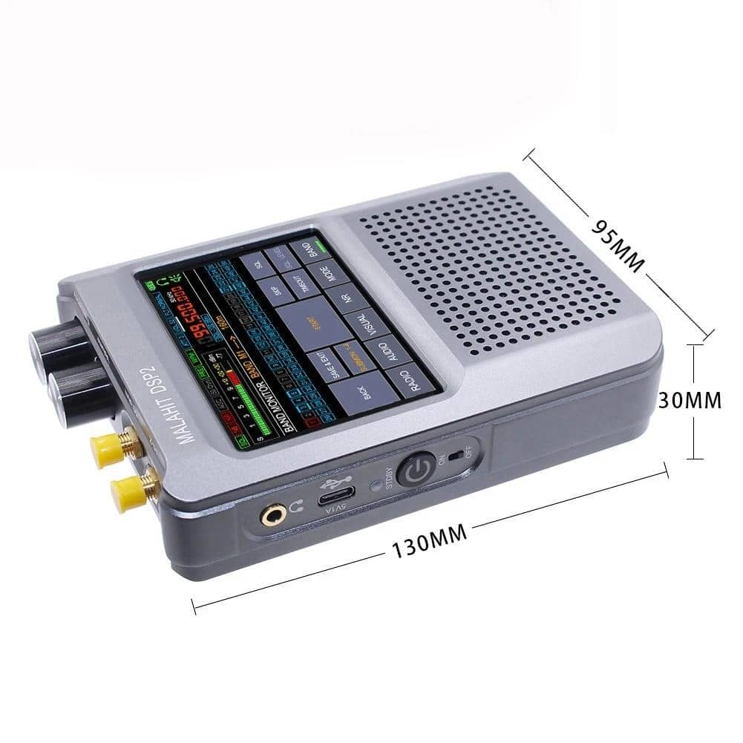
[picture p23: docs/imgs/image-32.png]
Malahit DSP2 SDR


<!-- Ключові технічні характеристики.

* Діапазон частот: 10 кГц-380 МГц, 404 МГц-2 ГГц.
* Ширина панорами: 192 кГц, 96 кГц, 48 кГц.
* Тип модуляції: AM, SSB, DSB, CW, NFM, WFM.
* Чутливість: 0,3 мкВ до 1 ГГц.
* Динамічна смуга пропускання: 82 дБ.
* Антена: роз'єм SMA з внутрішньою різьбою 50 Ом.
* Режим високого імпедансу (DSP2 або DSP1 з додатковою платою)
* Активна антена Bias Tee (DSP2 або DSP1 з додатковою платою)
* Джерело живлення: літій-іонний акумулятор 5000 мА*г.
* Екран: сенсорний РК-дисплей 3,5 дюйма.

Характеристики програмного забезпечення.

* Адаптивне шумозаглушення (NR)
* Порогове шумозаглушення
* Шумозаглушення (NB)
* Автоматичне регулювання підсилення (AGC)
* Автоматичний режекторний фільтр (ANF)
* Стерео FM підтримує аналогове стерео RDS
* Еквалайзер
-->

Всі вищеописані пристрої дуже ефективні та широкофункціональні. Найбільш важливі характеристики для наочності порівняння зведені у наступній таблиці. 

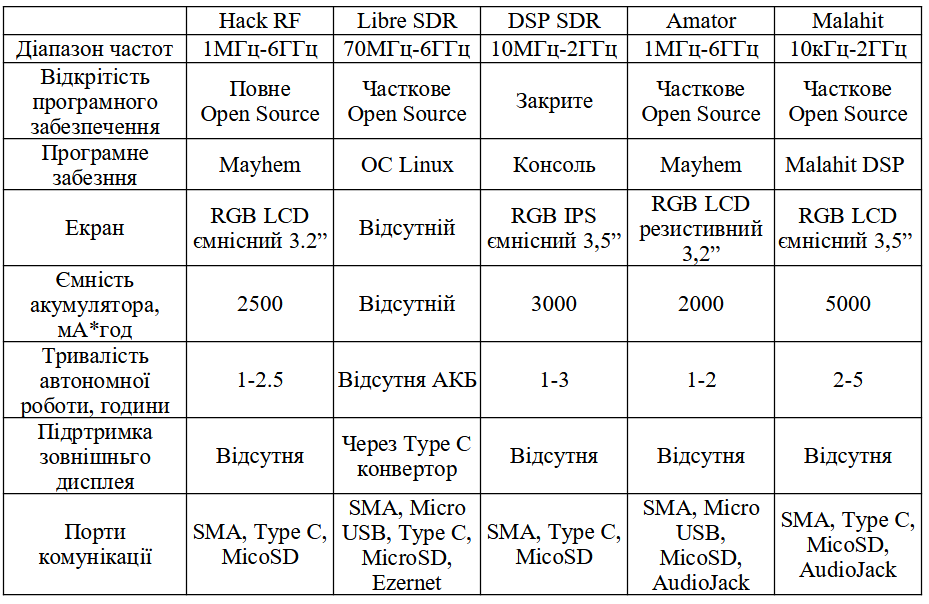
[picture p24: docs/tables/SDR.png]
Table: Порівняння існуючих розробок w=15


## Висновок по розділу 1

На основі проведеного аналітичного огляду приладів SDR-технології  можна зробити висновк, що сучасні портативні системи для виявлення, аналізу та передачі  радіосигналів є ефективними, універсальними та багатофункціональними засобами. Їхній функціонал значною мірою визначається як апаратною, так і програмною складовими, що дає змогу налаштовувати ці прилади під різні сфери застосування. Так у промисловості – для професійного контролю параметрів та якості радіочастот. У  науці - для точності дослідів та експериментів. А особливу увагу розробки приладів SDR на сьогодні необхідно приділити у зв’язку із загарбницьким військовим вторгненням ворожої Російської Федерації – для створення радіо комплексів виявлення, ідентифікації, обробки  та допомоги у знищенні ворожих цілей.

Оглянуті прилади SDR — HackRF One, Libre PLUTO, 1.10D DSP SDR, Amator та Malahit DSP2 — демонструють різні підходи до реалізації SDR-рішень. Вони відрізняються функціональністю, широким діапазоном частот, інтеграцією різноманітних інтерфейсів, типами екранів, автономністю та можливостями програмного налаштування. Зокрема, HackRF Onе виділяється універсальністю і компактністю, LibreSDR - потужним обчислювальним модулем та високою пропускною здатністю, 1.10D DSP SDR - простотою використання та широким функціоналом, Amator SDR - зручністю роботи з голосовими повідомленнями та аналізом ISM-сигналів а Malahit DSP2  - автономністю роботи.

Таким чином, вибір конкретного комплексу залежить від специфічних завдань користувача, технічних вимог і умов експлуатації. Загалом, розвиток SDR-технологій відкриває нові горизонти у сфері бездротових комунікацій, підвищуючи ефективність, мобільність і функціональність систем радіозв’язку і радіокерування.

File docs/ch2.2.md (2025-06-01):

## Підбір елементної бази

Підбір елементної бази — це ключовий етап у розробці будь-якого електронного пристрою, особливо якщо йдеться про складні багатофункціональні системи, такі як польовий планшет для збору, обробки та передачі даних. Від правильного вибору компонентів залежить не лише функціональність, а й надійність, енергоефективність, масштабованість і вартість кінцевого виробу.

Потрібно забезпечити оптимальне поєднання апаратних компонентів, які відповідають вимогам роботи за наступними критеріями.

* Функціональність: кожен елемент повинен виконувати свою роль (наприклад, прийом радіосигналу, обробка даних, зберігання інформації, відображення результатів, автономне живлення тощо).
* Сумісність: компоненти мають бути електрично та програмно сумісними між собою, щоб забезпечити стабільну роботу системи.
* Енергоефективність: важливо мінімізувати споживання енергії, особливо для портативних і автономних пристроїв.
* Масштабованість і гнучкість: можливість розширення функціоналу або заміни окремих модулів без повної переробки пристрою.
* Надійність і довговічність: вибір перевірених рішень із хорошою репутацією та підтримкою.

<!-- Етапи підбору елементної бази:

1. Аналіз вимог: визначення основних задач пристрою (наприклад, прийом і аналіз радіосигналів, GPS-навігація, відеозахоплення, зберігання даних, відображення інформації, автономна робота).
2. Вибір ключових модулів: підбір основних функціональних блоків (SDR-приймач, центральний процесор, GPS-модуль, накопичувач, дисплей, акумулятор, материнська плата).
3. Порівняння альтернатив: аналіз переваг і недоліків різних варіантів кожного модуля з урахуванням технічних характеристик, сумісності, ціни, підтримки та наявності.
4. Інтеграція: перевірка можливості спільної роботи обраних компонентів, оцінка потреб у додаткових адаптерах, платах розширення, драйверах тощо.
5. Прототипування: складання тестового зразка для перевірки працездатності всієї системи. -->

<!-- Грамотний підбір елементної бази дозволяє наступне.

* Забезпечити стабільну та ефективну роботу пристрою в реальних умовах експлуатації.
* Мінімізувати ризики виникнення апаратних і програмних проблем.
* Спростити подальше обслуговування, ремонт і модернізацію.
* Досягти балансу між продуктивністю, автономністю, розмірами та вартістю.
* Гарантувати масштабованість і адаптивність системи під нові задачі. -->

<!-- У цьому розділі детально розглядаються всі основні компоненти, їхні характеристики, переваги та недоліки, а також обґрунтовується вибір кожного елемента для конкретного застосування. Такий підхід дозволяє створити оптимальну апаратну платформу для реалізації поставлених функціональних і експлуатаційних вимог. -->

### Антени

Антени — це ключовий елемент системи прийому та передачі радіосигналів, оскільки саме вони забезпечують ефективний зв'язок пристрою з навколишнім радіочастотним середовищем. У контексті польового планшета для збору, обробки та передачі даних антени виконують наступні функції
>>> Kenwood. Communications Equipment Catalog and Engineering Guide. Kenwood Corporation. – [Електронний ресурс]. – Режим доступу: https://www.kenwood.com/usa/com/
.

* Прийом радіосигналів: антена вловлює електромагнітні хвилі з ефіру та перетворює їх на електричний сигнал, який далі обробляється SDR-приймачем або іншим радіомодулем. Якість прийому залежить від типу антени, її розміру, налаштування та відповідності робочому діапазону частот.
* Передача радіосигналів: при необхідності антена випромінює сформований електричний сигнал у вигляді радіохвиль, забезпечуючи зв'язок із зовнішніми пристроями, мережами або іншими системами.
* Забезпечення оптимальної роботи SDR: для широкосмугових SDR-приймачів важливо мати антену, яка покриває необхідний частотний діапазон і має відповідну діаграму спрямованості (всенаправлену чи спрямовану — залежно від задачі).
* Гнучкість і масштабованість: можливість підключення різних типів антен дозволяє адаптувати пристрій під різні сценарії використання — від моніторингу широкого спектра до точкового прийому слабких або далеких сигналів.
* Зниження рівня шуму та перешкод: правильно підібрана антена зменшує вплив зовнішніх завад, підвищує чутливість системи та покращує якість прийому.

У польових умовах особливо важливо враховувати компактність, міцність, простоту монтажу та можливість швидкої заміни або налаштування антени під конкретні задачі. Вибір типу антени (телескопічна, дипольна, дискон, спрямована, петльова тощо) визначається робочим діапазоном частот, вимогами до дальності зв'язку, рівнем сигналу та специфікою застосування (моніторинг, аналіз, передача даних, геолокація тощо).

Таким чином, антена є невід'ємною частиною апаратної платформи, що безпосередньо впливає на ефективність і функціональність пристрою для прийому та передачі радіосигналів.

[Види антен](https://sprotyvg7.com.ua/wp-content/uploads/2023/05/Osnovni-harakterystyky-anten_ukr.pdf):

Телескопічна антена (Whip Antenna).

* Частотний діапазон: ~30 МГц – 1 ГГц (залежно від довжини)
* Переваги: регульована довжина, компактність
* Недоліки: погано працює на частотах нижче 20 МГц або вище 1 ГГц
* Ідеальна для загального моніторингу, прослуховування FM-радіо, авіадіапазону тощо.

Дипольна антена.

* Частотний діапазон: залежить від довжини плечей (резонансна)
* Переваги: хороша ефективність на налаштовану частоту
* Недоліки: потребує місця для встановлення, вузькосмугова
* Підходить для прийому короткохвильових (HF) та деяких VHF сигналів.

Антена Discone.

* Частотний діапазон: ~25 МГц – 1.3 ГГц
* Переваги: надширокий діапазон, всенаправлена
* Недоліки: габаритна, складна у транспортуванні
* Популярна для загального спектрального аналізу або моніторингу кількох діапазонів.

Спрямовані антени (Yagi, Log-periodic).

* Частотний діапазон: залежить від конструкції
* Переваги: велике підсилення, вузька діаграма направленості
* Недоліки: потрібно точно наводити, габарити
* Використовується для направленого прийому, наприклад, супутникових або цифрових наземних сигналів.

Петльова антена (Loop Antenna).

* Частотний діапазон: від LW до HF
* Переваги: низький рівень шуму, малий розмір
* Недоліки: вузькосмугова, потребує підстроювання
* Чудово підходить для прийому слабких сигналів у діапазоні коротких хвиль.

Антена типу "вухо кролика" (Rabbit Ears).

* Частотний діапазон: 50 – 800 МГц
* Переваги: дешева, проста
* Недоліки: неефективна поза телевізійними діапазонами
* Може використовуватись для прийому DVB-T, FM або експериментів.

### Радіо модуль

Завдяки мікротехнологіям виготовлення плат із мікросхемами та окремими мікро-деталями, на сьогодні у пристроях SDR використовуються більш функціональніші можливості, що перетворює блок прийому сигналу у повноцінний приймач-відтворювач. Тому вихідні дані сигналу обробляються ПЗ і відповідно подаються у вигляді сигналів для формування зображень та звуку на моніторі чи у гучномовцю.

[HackRF-One](https://github.com/dodgymike/hackrf-wiki/blob/master/HackRF-One.md)
— це програмоване радіо, що дозволяє працювати з широким діапазоном частот (від 1 MHz до 6 GHz). Цей пристрій є потужним інструментом для досліджень і застосувань у бездротових комунікаціях, криптографії, виявленні та аналізі радіосигналів.

HackRF-One

HackRF-One має низку переваг, серед яких — підтримка широкого діапазону частот (від 1 MHz до 6 GHz), що дозволяє працювати з більшістю радіочастотних спектрів, а також можливість програмного налаштування параметрів роботи завдяки відкритому програмному забезпеченню. Компактний розмір пристрою забезпечує зручність використання у польових умовах. Водночас, для ефективної роботи з HackRF-One необхідні спеціалізовані знання у сфері радіоелектроніки та програмування, а обмежена вихідна потужність не дозволяє використовувати його для високоякісних або далекобійних передавальних задач.

[RTL-SDR](https://www.rtl-sdr.com/buy-rtl-sdr-dvb-t-dongles/)
 — це недорогий USB-приймач SDR, побудований на базі RTL2832U. Хоча він не підтримує передавання сигналів, його можна використовувати для широкого спектру задач моніторингу — від аналізу спектру до прийому супутникових або авіаційних сигналів.

RTL-SDR v3

RTL-SDR вирізняється дуже низькою вартістю, що робить його ідеальним вибором для початківців і аматорських проєктів. Пристрій дозволяє приймати сигнали в діапазоні від 500 кГц (за умови модифікації) до 1,7 ГГц і сумісний із популярними програмами, такими як SDR#, GQRX, GNURadio. Основними обмеженнями RTL-SDR є те, що він працює лише як приймач (немає можливості передавати сигнали), має вужчий частотний діапазон порівняно з HackRF, а також характеризується нижчою точністю та динамічним діапазоном.

[LimeSDR Mini](https://limemicro.com/products/boards/limesdr-mini/)
 — це компактний SDR із повною підтримкою прийому та передачі сигналів. Працює в діапазоні від 10 MHz до 3.5 GHz та підтримує USB 3.0 для високої швидкості передачі даних. Відмінно підходить для мобільних проєктів з аналізу та трансляції сигналів.

LimeSDR Mini

LimeSDR Mini має повноцінну підтримку прийому та передачі сигналів (TX/RX), забезпечує вищу якість сигналу порівняно з HackRF, особливо при роботі з цифровою модуляцією, а також підтримується відкритим програмним забезпеченням і активною спільнотою. До недоліків можна віднести вужчий частотний діапазон (до 3,5 ГГц проти 6 ГГц у HackRF-One), а також вищу ціну порівняно з RTL-SDR і дещо складніше налаштування для початківців.

[ADALM-Pluto (PlutoSDR)](https://wiki.analog.com/university/tools/pluto)
від Analog Devices — це потужна SDR-платформа з підтримкою прийому і передачі в діапазоні 325 MHz – 3.8 GHz (можна розширити до 70 MHz – 6 GHz через прошивку). Використовується в освітніх та наукових цілях, з дуже якісною документацією та підтримкою від виробника.

ADALM-Pluto

ADALM-Pluto (PlutoSDR) від Analog Devices вирізняється надійною апаратною реалізацією, підтримкою прийому і передачі сигналів із хорошим рівнем чистоти спектру, а також можливістю програмного розширення частотного діапазону. Водночас цей модуль має менш компактний форм-фактор порівняно з HackRF-One і може бути складнішим у налаштуванні для новачків.

[BladeRF](https://selteq.com.ua/ru/bladerf-2-0/)
2.0 micro xA4 SDR трансівер 47 МГц-6 ГГц 49 КЛЕ ПЛІС — це SDR-пристрій нового покоління, який охоплює частотний діапазон від 47 МГц до 6 ГГц, підтримує частоту дискретизації 61,44 МГц (з можливістю підвищення до 122,88 МГц) і забезпечує потокову обробку сигналів у режимі 2×2 MIMO. bladeRF ідеально підходить для мобільних та високопродуктивних застосувань.

BladeRF

Металевий екран забезпечує захист чутливих радіочастотних елементів від електромагнітних завад (EMI) і покращує тепловідведення, що дозволяє bladeRFстабільно працювати навіть у складних умовах.

Усі SMA-порти для радіочастотних сигналів можуть подавати живлення на широкосмугові або попередні підсилювачі через схему інжекції струму. Керування живленням периферійних пристроїв здійснюється програмно, що забезпечує максимальну гнучкість у використанні.

Основою bladeRF 2.0 є сучасна ПЛІС Cyclone V від Intel (раніше Altera). У моделі xA4 використовується ПЛІС із 49 тисячами логічних елементів.

<!-- Розширена система синхронізації дозволяє bladeRF як приймати, так і передавати тактовий сигнал із частотою 38,4 МГц. Вбудована схема ФАПЧ дає змогу синхронізувати внутрішній генератор із зовнішньою опорною частотою 10 МГц. У xA4 застосовується високоточний стабільний генератор, а вбудований ЦАП дозволяє точно підлаштовувати частоту для заводського калібрування.

Система живлення bladeRFскладається з поєднання малошумних імпульсних і лінійних стабілізаторів. Пристрій може працювати лише від USB, але для максимальної лінійності периферійних пристроїв, що живляться через інжектор, рекомендується підключати зовнішнє джерело живлення. Схема автоматичного перемикання дозволяє оптимізувати споживання енергії між USB і зовнішнім живленням. -->

<!-- Модуль bladeRF 2.0 micro підтримує автономний режим роботи без підключення до комп’ютера чи контролера. Обсяг вбудованої флеш-пам’яті достатній для зберігання будь-якого образу ПЛІС xA4.

Можливості та функціонал.

* РЧ-ПАРАМЕТРИ.
    * Робочий частотний діапазон: 47 МГц – 6 ГГц.
    * Підтримка 2 × 2 MIMO.
    * Частота семплювання: 61,44 МГц.
    * Максимальна ширина смуги ПЧ: до 56 МГц.
    * Автоматичне керування підсиленням (AGC).
    * Автоматичне вирівнювання IQ та компенсація постійної складової.

* ПІДТРИМКА ВИСОКОШВИДКІСНОГО ІНТЕРФЕЙСУ USB 3.0.
    * ARM926EJ-S процесор із тактовою частотою 200 МГц.
    * Повноцінне живлення через USB 3.0.
    * Можливість підключення зовнішнього джерела 5 В з автоматичним перемиканням.

* FPGA ALTERA CYCLONE V.
    * 49 тисяч логічних елементів для обробки сигналів та апаратного прискорення.

* VCTCXO ЗАВОДСЬКОГО НАЛАШТУВАННЯ.
    * Керування ФАПЧ через 12-розрядний ЦАП.
    * Точне заводське калібрування генератора 38,4 МГц. -->

Table: Загальні характеристики модулів радіо w=15

### Обчислювальний модуль

Центральне ядро обчислень є мозком будь-якого сучасного електронного пристрою. Саме цей компонент відповідає за обробку даних, виконання програмного забезпечення, взаємодію з периферією та забезпечення загальної продуктивності системи. Вибір обчислювального модуля визначає можливості пристрою щодо швидкості роботи, підтримки сучасних інтерфейсів, енергоефективності та масштабованості. У цьому підрозділі розглядаються основні варіанти центральних обчислювальних платформ, їхні характеристики, переваги та недоліки для побудови польового планшета.

[Raspberry Pi Compute Module 5 (CM5)](https://www.raspberrypi.com/products/compute-module-5)
— це компактний та потужний комп'ютер на базі процесора Broadcom BCM2711, який використовується в різноманітних вбудованих системах. Це основний компонент, який виконує обчислювальні операції у проекті. CM4 пропонує широку гнучкість завдяки варіативності в обсягах пам'яті (від 1 ГБ до 8 ГБ) і можливості додаткового зберігання через eMMC або microSD картки.

Raspberry Pi Compute Module 5

Compute Module 5 має низку переваг, серед яких — висока обчислювальна потужність завдяки чотириядерному процесору Cortex-A72, що дозволяє ефективно виконувати ресурсоємні задачі, включаючи обробку відео та даних у реальному часі. Гнучкість конфігурації забезпечується різними варіантами обсягу оперативної та постійної пам’яті, а також підтримкою широкого спектра периферійних пристроїв через GPIO, HDMI, USB, Ethernet і стандартні Raspberry Pi HAT. Вбудовані модулі Wi-Fi та Bluetooth дають змогу організувати бездротовий зв’язок і передачу даних без додаткових адаптерів. Серед недоліків варто відзначити підвищені вимоги до живлення — модуль потребує стабільного джерела енергії, що може ускладнити використання в автономних системах. Також Compute Module 5 не має вбудованого дисплея, тому для роботи необхідно підключати зовнішній екран. Крім того, відсутність стандартного жорсткого диска обмежує швидкість і обсяг зберігання даних, що може бути критичним для задач із великими масивами інформації.

[NVIDIA Jetson Nano](https://developer.nvidia.com/embedded/jetson-nano)
— це мікрокомп'ютер, орієнтований на проекти з використанням штучного інтелекту. Він оснащений чотириядерним ARM Cortex-A57 процесором та графічним процесором NVIDIA Maxwell із 128 ядрами CUDA, що робить його ідеальним для задач комп'ютерного зору, машинного навчання та автономних систем.

NVIDIA Jetson Nano

NVIDIA Jetson Nano вирізняється потужним графічним процесором, що дозволяє ефективно виконувати задачі глибокого навчання, штучного інтелекту та відеоаналітики в реальному часі. Платформа оптимізована для роботи з популярними AI-фреймворками, такими як TensorFlow, PyTorch і OpenCV, а також підтримує підключення дисплеїв через HDMI і MIPI DSI та камер через CSI-інтерфейс. Основними недоліками є підвищене енергоспоживання, що обмежує використання у повністю автономних пристроях, менша спільнота користувачів порівняно з Raspberry Pi, а також необхідність активного охолодження при тривалих навантаженнях.

[Radxa CM3](https://wiki.radxa.com/CM3) — це сумісний за розмірами модуль з Raspberry Pi CM4, але базується на SoC Rockchip RK3566 (4x Cortex-A55 до 2.0 ГГц) і орієнтований на вбудовані та мультимедійні рішення. Він підтримує до 8 ГБ LPDDR4 RAM і до 128 ГБ eMMC.

Radxa CM3

Radxa CM3 вирізняється високою енергоефективністю завдяки процесору Cortex-A55, що забезпечує хорошу продуктивність при низькому споживанні енергії, а також підтримкою сучасних відеокодеків і 4K-відео. Модуль повністю сумісний по роз'єму з Raspberry Pi CM4, що спрощує інтеграцію у вже існуючі рішення. Водночас, його екосистема менш розвинена: доступно менше програмного забезпечення, підтримка спільноти слабша, а підтримка Linux дещо обмежена порівняно з Raspberry Pi OS. Крім того, у базовій конфігурації відсутні вбудовані модулі Wi-Fi та Bluetooth, що може вимагати додаткових адаптерів для бездротового зв’язку.

<!-- 4. Banana Pi BPI-CM4

![Banana Pi BPI-CM4](imgs/image-15.png)

[Banana Pi BPI-CM4](https://wiki.banana-pi.org/Banana_Pi_BPI-CM4)
— ще один сумісний із Raspberry Pi Compute Module 5 варіант, який використовує Rockchip RK3568 (4x Cortex-A55). Він орієнтований на промислові рішення, що потребують високої стабільності та надійності.

Переваги:

* Великий набір інтерфейсів: SATA, PCIe, USB 3.0, MIPI DSI/CSI.
* Підтримка eMMC до 128 ГБ, до 8 ГБ RAM.
* Хороша термостійкість і надійність — придатний для польових умов.

Недоліки:

* Не настільки добре підтримується спільнотою, як Raspberry Pi.
* Відсутність офіційної підтримки деяких популярних дистрибутивів Linux.
* Деякі користувачі відзначають нестабільність програмного забезпечення. -->

Table: Загальні характеристики обчислювальних модулів w=15

<!-- ### Пристрій захоплення аналогового відеосигналу

1. USB карта відеозахоплення LUX EasyCap

EasyCap — це бюджетний USB-адаптер для захоплення відеосигналу з аналогових джерел, таких як камери, DVD-плеєри чи ігрові консолі. Він підтримує передачу відео і аудіо через USB, що робить його універсальним рішенням для запису відео та моніторингу.

![USB карта відеозахоплення LUX EasyCap](imgs/image.png)

Переваги:

* Низька ціна: один із найекономніших варіантів для відеозахоплення.
* Легкість у використанні: підключається через USB і сумісний з більшістю операційних систем.
* Універсальність: можна використовувати з різними аналоговими джерелами відео.

Недоліки:

* Обмеження якості: відео може бути обмежене в роздільній здатності та якості порівняно з сучасними цифровими рішеннями.

2. Digitnow USB 2.0 Video Capture Card

[Digitnow USB 2.0 Video Capture Card](https://www.amazon.com/Digitnow-Video-Capture-Converter-VHS/dp/B01HEQZ66U)
це пристрій, що є повним аналогом EasyCap, але має покращений чипсет і часто постачається з власним ПЗ для захоплення відео. Призначений для роботи з аналоговими джерелами через композитні та S-Video входи.

Переваги:

* Покращена сумісність з Windows 10 і 11.
* Часто має краще ПЗ для редагування/запису відео в комплекті.
* Легке підключення через USB.

Недоліки:

* Все ще обмежена якість відео (SD, 720x576 max).
* Більш висока ціна порівняно з EasyCap без суттєвих переваг.

#### [August VGB100 USB Video Capture Stick](https://www.augustint.com/uk/productmsg-103-0.html)

![August VGB100 USB Video Capture Stick](imgs/image-25.png)

August VGB100 — це більш преміальний адаптер з підвищеною стабільністю з'єднання, кращим чипсетом і зменшеним шумом у відео. Ідеально підходить для захоплення відео з аналогових камер у реальному часі.

Переваги:

* Вища якість відео у порівнянні з бюджетними рішеннями.
* Менше артефактів та шуму при записі.
* USB 2.0 сумісність та підтримка PAL/NTSC.

Недоліки:

* Вартість значно вища за EasyCap.
* Все ще обмежений до SD-якості. 

Висновок

LUX EasyCap забезпечує оптимальне співвідношення ціни та функціональності для задач захоплення аналогового відео в DIY-проєкті. Попри скромну якість відео (яка характерна для всіх адаптерів цього класу), він легкий у використанні, доступний, сумісний з Linux/Windows, і не потребує складного налаштування. У контексті польового планшета, де важлива мобільність, економія енергії та простота, LUX EasyCap стає ідеальним бюджетним вибором для роботи з аналоговими камерами або відеосигналами. -->

### GPS модуль

У сучасних портативних пристроях модуль GPS є невід’ємною складовою для визначення місцезнаходження, синхронізації часу та навігації. Вибір відповідного GPS-модуля впливає на точність позиціювання, швидкість отримання координат і стабільність роботи в різних умовах. У цьому підрозділі розглядаються основні типи GPS-модулів, їхні характеристики, переваги та недоліки для інтеграції у польовий планшет.

[GPS модуль u-blox NEO-6M](https://uamper.com/products/datasheet/NEO-6.pdf)
забезпечує точне визначення географічних координат і може використовуватися для синхронізації часу або визначення місця розташування. Він є важливим компонентом для проектів, де необхідно точно визначати позицію детекованого сигналу, наприклад, у системах моніторингу або геолокації.

GPS модуль NEO-6M v2

Основними перевагами модуля NEO-6M є висока точність позиціювання (до кількох метрів), швидкий старт (підтримка холодного та гарячого старту), низьке енергоспоживання, а також широка сумісність завдяки стандартним інтерфейсам UART і I2C, що спрощує інтеграцію у різні системи. До недоліків можна віднести залежність від якості прийому супутникового сигналу — для отримання точних координат потрібен відкритий доступ до неба, а для покращення прийому часто необхідна зовнішня антена.  

u-blox NEO-M8N

NEO-M8N — більш сучасна модель від u-blox з розширеною функціональністю. Підтримує одразу декілька навігаційних систем (GPS, GLONASS, Galileo), що значно підвищує точність і надійність у складних умовах.

Основними перевагами модуля NEO-M8N є підтримка кількох супутникових систем (GPS, GLONASS, Galileo), що забезпечує вищу точність і стабільність позиціювання навіть у складних умовах, наприклад, у міській забудові або лісистій місцевості. Модуль також вирізняється високою швидкістю оновлення координат (до 10 Гц), що дозволяє оперативно відстежувати рух об’єкта. До недоліків можна віднести вищу вартість у порівнянні з базовими моделями, а також необхідність використання якісної антени для досягнення максимальної продуктивності та точності.

<!-- Quectel L86 GPS/GNSS — компактний GNSS модуль із вбудованою патч-антеною. Підтримує GPS, QZSS і SBAS. Має вбудовану флеш-пам’ять для збереження даних та швидкого старту.

Переваги:

* Надзвичайно компактний форм-фактор.
* Вбудована антена — не потребує зовнішньої (але можна підключити).
* Підтримка AGPS (завантаження ефемерид через інтернет).

Недоліки:

* Нижча чутливість у порівнянні з модулями з повноцінною антеною.
* Вужчий діапазон GNSS протоколів, ніж у M8N. -->

<!-- #### Beitian BN-220

BN-220 — це готовий до використання GPS-модуль у пластиковому корпусі з вбудованою керамічною антеною. Він особливо популярний у дронах та автономних роботах.

Переваги:

* Просте підключення (UART, plug-n-play).
* Надійний прийом сигналу.
* Вбудована антена з хорошими характеристиками.

Недоліки:

* Менше можливостей кастомізації, ніж у NEO-серії.
* Складніше інтегрувати у тонкий корпус планшета через корпус модуля. -->

Table: Загальні характеристики модулів GPS w=10

### Пам'ть постійного зберігання

Пам'ять постійного зберігання є критичним компонентом будь-якого сучасного електронного пристрою, оскільки саме вона відповідає за збереження операційної системи, програмного забезпечення та користувацьких даних. Від вибору типу та моделі накопичувача залежать швидкість роботи системи, надійність зберігання інформації, енергоефективність і загальна стабільність пристрою. У цьому підрозділі розглядаються основні варіанти SSD-накопичувачів, їхні характеристики, переваги та недоліки для використання у складі польового планшета.

[SSD MTS420S MTS420S 240GB M.2 2242 SATAIII 3D NAND TLC](https://hard.rozetka.com.ua/ua/transcend-ts240gmts420s/p436737317/)
диск забезпечує високу швидкість читання та запису завдяки використанню 3D NAND технології та інтерфейсу SATAIII. Ідеальний для зберігання операційної системи, даних та програм у вашому пристрої.

SSD диск Transcend MTS420S

Основними перевагами SSD Transcend MTS420S є висока швидкість роботи, що забезпечує швидке завантаження операційної системи та збереження даних, а також надійність завдяки використанню 3D NAND-пам’яті, яка має більшу стійкість до зносу порівняно з традиційною 2D NAND. Додатковою перевагою є енергоефективність — споживання енергії значно нижче, ніж у механічних жорстких дисків, що важливо для автономних пристроїв. До недоліків можна віднести вищу вартість у порівнянні з класичними HDD, а також обмежену ємність: хоча 240 ГБ достатньо для більшості стандартних задач, для зберігання великих обсягів даних може знадобитися диск більшої місткості.

KingSpec M.2 2242 SATAIII 256GB — китайський виробник SSD-дисків, який пропонує бюджетні рішення з форм-фактором M.2 2242. Цей SSD має інтерфейс SATAIII і базується на TLC NAND, що забезпечує швидкий доступ до даних. Вирізняється вигідною ціною, продуктивністю на рівні більшості SATAIII SSD і широкою доступністю на AliExpress та локальних ринках. Однак цей накопичувач поступається брендовим рішенням за надійністю та тривалістю служби, а якість окремих партій може суттєво відрізнятися.

<!-- ADATA — відомий виробник із більш стабільною якістю продукції. SU650 — це SATA SSD, який має трохи більший форм-фактор (2280), але може використовуватись у 2242 слотах із адаптером або вільним місцем на платі.

ADATA SU650 — це SSD із стабільною якістю та надійною підтримкою бренду, який добре працює навіть при підвищених навантаженнях і підходить для Linux- або Android-платформ. Основним недоліком є форм-фактор 2280, що ускладнює використання в компактних системах без адаптера, а також відсутність високих швидкостей, характерних для NVMe SSD. -->

<!-- #### Transcend MTS430S 256GB M.2 2242 SATAIII

Оновлена версія MTS420S, цей диск має вищу ємність (256 ГБ), покращену продуктивність і той самий компактний форм-фактор M.2 2242. Оснащений 3D NAND TLC і підтримує DevSleep для зниженого енергоспоживання.

Переваги:

* Офіційна підтримка Transcend.
* Енергоефективний і довговічний.
* Швидкість читання до 560 МБ/с.

Недоліки:

* Трохи дорожчий, ніж MTS420S.
* Різниця в продуктивності не завжди помітна в реальному використанні. -->

Table: Загальні характеристики модулів пам'яті w=10

### Сенсорний дисплей

Сенсорний дисплей є одним із ключових елементів сучасних портативних пристроїв, оскільки саме він забезпечує основний інтерфейс взаємодії користувача з системою. Від вибору типу, розміру, роздільної здатності та технології сенсорного введення залежить зручність експлуатації, функціональність і ергономіка пристрою. У цьому підрозділі розглядаються основні варіанти сенсорних дисплеїв, їхні характеристики, переваги та недоліки для інтеграції у польовий планшет, а також обґрунтовується вибір оптимального рішення для конкретних задач роботи.

[BM Lenovo Wacom 12.1in XGA LCD Touch Screen](https://www.alancomputech.com/ibm-lenovo-wacom-12-1in-xga-lcd-touch-screen-13n7241-laptop-su5r-12s05as-02x-13n7241.html) 
цей сенсорний дисплей має XGA роздільну здатність (1024x768 пікселів) і підтримує технологію стилусного введення. Його можна використовувати для розробки інтерфейсів користувача, де необхідний високий рівень точності введення. Використання стилуса дозволяє отримати більш точні результати, що важливо в польових умовах або при роботі з картами та іншими детальними графіками.

IBM Lenovo Wacom 12.1in XGA LCD Touch Screen

Сенсорний дисплей IBM Lenovo Wacom має низку переваг, серед яких підтримка як сенсорного введення пальцем, так і точного введення за допомогою стилуса, що особливо важливо для інтерактивних і професійних додатків. Його компактний розмір робить пристрій зручним для портативного використання, а висока точність введення дозволяє ефективно працювати навіть у складних робочих умовах. Водночас до недоліків можна віднести відносно невеликий розмір екрана, який може бути недостатнім для відображення складних графічних інтерфейсів, а також вищу вартість у порівнянні з іншими типами дисплеїв подібного класу.

[Waveshare 10.1" HDMI LCD with Capacitive Touch](https://www.waveshare.com/10.1inch-hdmi-lcd.htm)
це 10.1-дюймовий дисплей із роздільною здатністю 1280x800 пікселів підтримує ємнісне сенсорне введення до 10 дотиків одночасно. Він підключається через HDMI для відео і через USB для сенсорного інтерфейсу, що робить його простим у використанні з Raspberry Pi Compute Module 5.

Waveshare 10.1 HDMI LCD

Waveshare 10.1" HDMI LCD із ємнісним multitouch має низку переваг: високу роздільну здатність (1280×800), що робить його зручним для сучасних інтерфейсів користувача, підтримку до 10 одночасних дотиків для плавної взаємодії, а також просте підключення через HDMI та USB без необхідності складного налаштування драйверів. Водночас дисплей не підтримує роботу зі стилусом із точністю Wacom і не має MIPI-інтерфейсу, тому для підключення до системи потрібен HDMI-порт, що може бути незручним у компактних планшетах.

[Official Raspberry Pi Touchscreen Display](https://www.raspberrypi.com/products/raspberry-pi-touch-display/)
має роздільну здатність 800x480 та підтримує ємнісний multitouch. Підключається через DSI-інтерфейс, тому не займає HDMI-порт, що критично у компактних системах.

Raspberry Pi 7 Touchscreen

Основними перевагами офіційного сенсорного дисплея Raspberry Pi є підключення через інтерфейс DSI, що дозволяє не займати HDMI-порт і залишає його для додаткових дисплеїв або інших пристроїв, компактний розмір, який ідеально підходить для невеликих корпусів планшетів, а також повна інтеграція з Raspberry Pi завдяки підтримці драйверів «з коробки». Водночас до недоліків цього дисплея належать невисока роздільна здатність (800×480), що може бути обмеженням при роботі зі складними або великими інтерфейсами користувача, а також малий фізичний розмір екрана, який не завжди зручний для відображення великої кількості інформації.

<!-- #### [BOE 10.1" MIPI DSI IPS LCD Touch Screen](https://www.panelook.com/TV101WXM-NH0_BOE_10.1_LCM_overview_26806.html)

![BOE MIPI 10.1 DSI](imgs/image-21.png)

Цей дисплей з IPS-матрицею має роздільну здатність 1280x800 або 1920x1200, підтримує інтерфейс MIPI DSI і часто використовується у промислових планшетах. Підтримує ємнісне сенсорне введення, є моделі з підтримкою стилуса (пасивного або активного).

Переваги:

* Повна підтримка MIPI DSI — без потреби у HDMI, що критично для CM4.
* Висока роздільна здатність, широкі кути огляду (IPS).
* Опціонально — підтримка стилуса або перо.

Недоліки:

* Потребує контролера або виводу з CM4 через DSI-конектор (іноді складне підключення).
* Немає стандартизованої підтримки — залежить від конкретної моделі. -->

Table: Загальні характеристики сенсорних дисплеїв w=15

### Модуль живлення

<!-- Літій-іонні (Li-ion) елементи та зібрані із них акумуляторні батареї (АБ) за останні роки повністю довели свою ефективність використання у різноманітних галузях людського виробництва техніки та майже замінили кислотні (КБ) і лужні (ЛБ) батареї, котрі використовувалися раніше. А деякі виробництва пристроїв загалом неможливі без новітніх Li-ion джерел струму. Так більшість переносних засобів комунікації (смартфонів), портативних комп'ютерів (ноутбуків, планшетів), засобів руху (моноколіс, GyroScooter, Hoverboard, е-байків), різноманітних побутових та складських роботів (роботів-пилосмоків, роботів для миття вікон), різних портативних та виробничих електростанцій (powerbank, UPS, сонячних станцій) та інших сучасних гаджетів обов’язково створені на основі Li-ion АБ.

Переваги такої технології виробництва над технологіями свинцево-кислотних та лужних (alkaline) хімічних елементів живлення сьогодні стали нормою і базою для створення сучасної техніки у світі. Необхідно відзначити найбільш вагомі особливості Li-ion джерел живлення.

* Щільність енергії на одиницю маси та об’єму — розміри елементів і АБ у 2–4 рази менші.
* Швидка перезарядка від 0 до 100% за 1–2 години, що дає більш ефективно використовувати пристрої на Li-ion живленні.
* Циклічність заряду/розряду від 1000 до 8000 разів, що дозволяє експлуатувати батареї у декілька разів довше: від 5 до 25 років.
* Низький саморозряд — енергія у таких батареях зберігається у декілька разів довше без експлуатації.
* Екологічність — відсутність у будові токсичних металів (кадмій, свинець, ртуть) згідно сучасних екологічних стандартів.

Конструкція та принцип роботи Li-ion акумуляторів

Основу конструкції Li-ion акумуляторів складають.

* Анод — пористий вуглець на мідній підкладці.
* Катод — оксид літію на алюмінієвій фользі.
* Сепаратор — пористий поліпропілен, просочений електролітом, який забезпечує іонну провідність.
* Корпус — герметичний, з під’єднаними до струмознімачів електродами; у деяких моделях є клапан для скидання надлишкового тиску.

Мідні та алюмінієві стрічки, просочені електролітом і розділені сепаратором, згортають у спіраль (для циліндричних корпусів) або укладають шарами (для призматичних чи пакетних форм).

Принцип роботи.

* Під час заряджання позитивно заряджені іони літію відокремлюються від оксиду та мігрують до вуглецевого анода, супроводжуючись окисно-відновною реакцією та накопиченням заряду.
* При розряді процес відбувається у зворотному напрямку — іони Li⁺ повертаються до катода з оксиду літію.

Літієві акумулятори чутливі до надлишкового заряду: перевищення допустимого рівня призводить до осадження металевого літію на аноді, що може спричинити реакцію з електролітом. У такому разі на катоді інтенсивно виділяється кисень, що проявляється нагріванням, підвищенням тиску та ризиком розгерметизації елемента.

Процес заряджання літієвих елементів та акумуляторних батарей відбувається у два основних етапи.

Перший етап — заряджання здійснюється при постійному струмі 0,2С–1С до досягнення напруги 4,2 В, що зазвичай триває близько 40 хвилин.

Другий етап — заряджання продовжується при фіксованій напрузі, доки зарядний струм не зменшиться до 3% від номінального значення.

Для подовження терміну служби літієвої батареї рекомендується заряджати її струмом, який дорівнює 50% від ємності (0,5С).

З часом Li-ion акумулятори «старіють»: усередині накопичуються продукти окислення, а ємність поступово зменшується. Економічно виправдано вважати акумулятор таким, що відпрацював свій ресурс, коли його ємність знижується на 30% від початкової. Типовий ресурс таких батарей — близько 1000 циклів заряджання та розряджання.

Щоб подовжити термін служби АКБ, рекомендується наступне.

* Не перевищувати оптимальний зарядний струм (0,5С, тобто 50% від номінальної ємності).
* Уникати глибокого розряду та перезаряджання.
* Не допускати перегріву, переохолодження та тривалого зберігання у розрядженому стані.

Дотримання цих рекомендацій дозволяє зберегти максимальну ефективність та надійність акумулятора протягом усього періоду експлуатації.

Типи та різновиди існують у багатьох варіантах із різними складовими катода. В окремих модифікаціях анод може бути виконаний не лише з графіту, а й із його замінників — повністю або частково.

* Літій-кобальтові (LiCo)

Ці акумулятори використовуються переважно у сучасних гаджетах, де важлива висока питома енергоємність: смартфонах, ноутбуках, цифрових камерах тощо.

Для безпечної експлуатації LiCoO₂-елементи оснащуються спеціальними захисними схемами, які обмежують заряд і розряд до безпечних меж.

Мінуси: відносно короткий термін служби, невисока термічна стабільність і обмежена кількість циклів заряджання-розряджання.

* Літій-марганцеві (LiMn)

Завдяки низькому внутрішньому опору ці батареї здатні швидко заряджатися та витримувати короткочасні імпульси струму до 50А. Гнучкість конструкції дозволяє адаптувати характеристики під різні задачі. LiMn-акумулятори застосовують у потужних електроінструментах, медичному обладнанні, а також у транспорті з електро- чи гібридним приводом.

* Літій-полімерні (Li-Pol, Li-polymer, Li-Po)

Головна перевага — можливість виготовлення у різних формах і розмірах. Такі акумулятори мають низький рівень саморозряду, слабко виражений ефект пам’яті та високу ємність.

Недолік: при низьких температурах електричні властивості погіршуються через можливу кристалізацію полімеру.

Li-Pol акумулятори бувають стандартними та високострумовими (швидкорозрядними). Останні здатні віддавати струм до 10С, тоді як стандартні — трохи більше 3С. Вони краще підходять для пристроїв із частими циклами заряджання-розряджання: мобільної техніки (смартфонів, планшетів, електронних книг), радіокерованих моделей, портативного інструменту та окремих електромобілів.

*  [Літій-залізо-фосфатні (LiFePO4)](https://deps.ua/ua/katalog/accumulators-batteries.html?f=l1928)

Літій-залізо-фосфатні акумулятори (LiFePO4) відзначаються високою термостійкістю (робочий діапазон температур від \-30 до \+50 °C), що дозволяє їх застосовувати на відкритому повітрі. Вони безпечні у використанні: не схильні до займання чи вибуху при перенапрузі, стійкі до перезаряджання та перепадів напруги в мережі. Можуть витримувати короткочасні розрядні струми до 25С і тривалу дію підвищеної напруги. Саморозряд за місяць становить лише 1,5%. Термін служби — до 2000 циклів, а зберігати їх можна до 15 років. Завдяки стабільності хімічної структури LiFePO4-акумулятори підтримують швидке заряджання великими струмами (до 80% ємності — приблизно за 1,5 години), але для цього потрібні спеціалізовані зарядні пристрої, несумісні з іншими типами акумуляторів. До недоліків належать більша маса, габарити та вартість. Для тривалого зберігання рекомендується підтримувати заряд у межах 40–60%.

LiFePO4-батареї випускаються у вигляді циліндричних, призматичних і плоских елементів. Їх широко застосовують у системах альтернативної енергетики (сонячні панелі, вітрогенератори), електротранспорті, складській техніці, ігровому обладнанні тощо. Вони не бояться тривалих періодів простою, а втрата ємності до кінця експлуатації не перевищує 20%.

Літій-титанатні (LTO)

LTO-акумулятори відзначаються стабільною роботою при низьких температурах. Відсутність вуглецю в аноді знижує ризик перегріву, а низька напруга комірки (2,4 В) підвищує безпеку експлуатації. Ефект пам’яті відсутній. Основний недолік — невисока енергетична щільність (30–110 Вт·год/кг). LTO застосовують у електротранспорті, автомобілях (як стартерні АКБ), побутовій техніці, медичному та телекомунікаційному обладнанні, а також у системах освітлення на базі сонячних панелей.

Літій-нікель-марганець-кобальт-оксидні (Li-NMC, NMC)

Li-NMC-акумулятори поєднують переваги марганцю (стабільність, але високий опір) і нікелю (висока енергоємність, але менша стабільність), що забезпечує оптимальний баланс характеристик. Основні плюси: хімічна стабільність, висока струмовіддача, низький саморозряд, стійкість до глибокого розряду та температурних коливань. Вони не схильні до займання, тому підходять для використання в UPS. Основна сфера застосування — електротранспорт.

Усі основні типи Li-ion акумуляторів можна порівняти у вигляді таблиці, що дозволяє швидко оцінити їх переваги та недоліки. Максимальна ємність батареї не вказується, оскільки вона визначається кількістю та конфігурацією окремих елементів у складі акумуляторної збірки. 

![Table: Загальні характеристики Li-ion елементів живлення w=15](tables/Litium.png)

[Акумулятор літій-полімерний 10000 mAh, 3.7v, 1260110](https://alphapower.com.ua/ua/p1184584341-akkumulyator-litij-polimernyj.html)
-->

Живлення є одним із ключових компонентів автоматизованого портативного комплексу, що безпосередньо впливає на його автономність, стабільність і загальну ефективність. У зв’язку з цим особливу увагу приділено вибору типу акумуляторної батареї, яка забезпечує надійне та довготривале функціонування пристрою в польових умовах.

Сучасні портативні електронні пристрої майже повністю перейшли на літій-іонні (Li-ion) джерела живлення, що витіснили застарілі кислотні та лужні батареї.

Літієві акумулятори мають низку важливих переваг: вони характеризуються високою густиною енергії, що дозволяє створювати компактні та легкі пристрої; забезпечують швидке заряджання (повний цикл за 1–2 години); відзначаються довговічністю — ресурс може досягати до 8000 циклів заряджання-розряджання; мають низький саморозряд, завдяки чому енергія зберігається тривалий час навіть без експлуатації; є екологічно безпечними, оскільки відсутні небезпечні сполуки для людини, такі як: Pb, Cd чи Hg. Кожен елемент Li-ion акумулятора складається з анода з пористого вуглецю (на мідній фользі), катода з оксиду літію (на алюмінієвій фользі), сепаратора — пористої мембрани, просоченої електролітом, та герметичного корпусу, який іноді оснащується вентиляційним клапаном для підвищення безпеки.

Огляд типів літієвих акумуляторів

LiCoO₂ – Літій-кобальтові (LCO) це найпоширеніший тип акумуляторів у портативній техніці (смартфони, ноутбуки, фотоапарати). Характеризується високою питомою енергією.

<!-- Переваги:

* Висока енергоємність.
* Компактність і мала вага.

Недоліки:

* Низька термостабільність.
* Потребує захисної схеми від перезарядки.
* Обмежений термін служби (до 500–800 циклів). -->

LiMn₂O₄ – Літій-марганцеві (LMO) використовуються в електроінструменті, транспорті, медичній техніці.

<!-- Переваги:

* Низький внутрішній опір — витримують імпульсні струми до 50 А.
* Швидке заряджання.
* Надійність і стабільність.

Недоліки:

* Дещо нижча енергоємність порівняно з LiCoO₂.
* Обмежена кількість циклів (близько 1000–1500). -->

Li-Pol – Літій-полімерні мають гнучку конструкцію, можуть випускатися у вигляді тонких пластин. Застосовуються у смартфонах, планшетах, радіомоделях.

<!-- Переваги:

* Мала товщина, можливість виготовлення різних форм.
* Низький саморозряд.
* Висока енергоємність.

Недоліки:

* Чутливість до температур.
* Потреба у точному контролі зарядного струму (0,5C). -->

LiFePO₄ – Літій-залізо-фосфатні найбільш безпечні й довговічні. Використовуються в альтернативній енергетиці, електротранспорті, портативних енергосистемах.

<!-- Переваги:

* Висока термостійкість (–30 до +50 °C).
* Термін служби до 2000 циклів.
* Стабільна хімічна структура.
* Низький саморозряд (1,5%/міс).
* Підтримка високих струмів заряджання (до 2–3С).

Недоліки:

* Більша маса і розмір.
* Вища вартість.
* Потреба в спеціалізованих зарядних пристроях. -->

LTO – Літій-титанатні мають найвищу кількість циклів, стабільні при низьких температурах. Застосовуються в транспорті, сонячних системах, медичній техніці.

<!-- Переваги:

* 5000–10000 циклів.
* Робота при температурі до –40 °C.
* Повна відсутність ефекту пам’яті.
* Висока безпека (не схильні до займання).

Недоліки:

* Низька енергетична щільність (30–110 Вт·год/кг).
* Вища ціна. -->

Li-NMC – Літій-нікель-марганець-кобальт-оксидні збалансовані за характеристиками, використовуються в електротранспорті, ІБЖ, системах з високим струмом.

<!-- Переваги:

* Висока хімічна стабільність.
* Велика струмовіддача.
* Низький саморозряд.
* Стійкість до глибокого розряду.

Недоліки:

* Вартість залежить від варіанту хімічного складу.
* Потребує якісної BMS-системи. -->

Table: Загальні характеристики Li-ion елементів живлення w=15

З огляду на вимоги до автономності, габаритів і гнучкості корпусу, для проєкту було обрано літій-полімерну батарею типорозміру 1260110 з ємністю 10000 мА·год і напругою 3.7 В:

* Розміри: 110 × 60 × 12 мм.
* Підходить для планшетного форм-фактору.
* Має захист від перезаряду/перерозряду (через BMS).
* Достатня для 6–10 годин автономної роботи.

li-ion 10 Ah, 3.7v, 1260110

Ретельний аналіз доступних типів літієвих акумуляторів дозволив обрати найоптимальніший варіант — Li-Pol батарею, яка повністю відповідає критеріям компактності, автономності, енергоефективності та безпеки. Дотримання режимів експлуатації та захисту дозволить забезпечити довготривалу та стабільну роботу пристрою в складних умовах.

### Материнська плата

У цій частині розглядаються варіанти материнських плат, сумісних з модулем Raspberry Pi Compute Module 5, які виконують роль основи для підключення периферійних пристроїв, живлення та розширення функціональності системи. Порівняння різних моделей дозволяє визначити оптимальне рішення залежно від вимог до габаритів, кількості інтерфейсів, підтримки мультимедійних модулів, а також можливостей розширення та живлення.

[Compute Module 5 IO Board](https://www.raspberrypi.com/products/compute-module-4-io-board/) 
це основна плата для підключення Raspberry Pi Compute Module 5 до різних периферійних пристроїв. Вона надає різноманітні порти та можливості підключення: HDMI, USB, Ethernet, слот для microSD, PCIe слот для розширення і підтримку камер через MIPI CSI-2.

Compute Module 5 IO Board

<!-- Переваги:

* Розширення можливостей: надає доступ до всіх основних інтерфейсів для підключення периферії.
* Інтерфейси для дисплеїв і камер: підтримує MIPI DSI для дисплеїв та MIPI CSI-2 для камер, що дозволяє створювати мультимедійні системи.
* Підтримка PoE: можливість живлення через Ethernet (PoE) спрощує монтаж і зменшує потребу в додаткових живильних кабелях.

Недоліки:

* Потрібен додатковий обв'язок: вимагає підключення Compute Module 5, що збільшує складність розробки та інтеграції.
* Обмеження по кількості портів: деякі інтерфейси, такі як USB, обмежені в портах. -->

Waveshare CM4 IO Base Board B

[Waveshare CM4 IO Base Board B](https://www.waveshare.com/cm4-io-base-b.htm) спеціально розроблена для Raspberry Pi Compute Module 5. Вона має компактний форм-фактор, зручний для вбудованих рішень, а також надає доступ до основних портів: HDMI, USB, Ethernet, камери та дисплеїв через MIPI.

Waveshare CM4 IO Base Board B

<!-- Переваги:

* Компактний розмір: зручно вбудовується у портативні пристрої, включаючи планшети.
* Повна підтримка CM4: має слот для eMMC-версій, слот microSD для Lite-версій.
* Виводи для GPIO: можна підключати сенсори, кнопки, інші периферійні пристрої.

Недоліки:

* Обмежені можливості розширення: відсутній PCIe слот.
* Відсутність PoE: не підтримується живлення через Ethernet. -->

[Seeed Studio reComputer CM4 IO Board](https://www.seeedstudio.com/reComputer-IO-Board-p-5279.html) розроблена для використання з CM4, плата reComputer IO Board орієнтована на промислові рішення та мультимедійні пристрої. Має повноцінний набір інтерфейсів, включаючи HDMI, USB 3.0, GbE Ethernet, слот PCIe, RTC, і підтримує до 2 камер.

Seeed Studio reComputer CM4 IO Board

<!-- Переваги:

* Підтримка PCIe: дозволяє розширити функціональність через NVMe диски або інші модулі.
* Підтримка RTC: можливість точного відстеження часу без зовнішнього джерела.
* Гарна якість збірки та розведення.

Недоліки:

* Трохи більші габарити — не ідеально для тонких планшетів.
* Вища ціна у порівнянні з базовими платами. -->

<!-- #### [DFRobot Raspberry Pi CM4 IoT Router Carrier Board Mini](https://www.dfrobot.com/product-2590.html)

![DFRobot CM4 IoT Router Carrier](imgs/image-18.png)

Хоча ця плата орієнтована на побудову маршрутизаторів на базі CM4, вона має компактний розмір і чудово підходить для мініатюрних планшетів з функціями зв’язку. Має два гігабітні порти, слот для microSD, USB 2.0, UART, і GPIO.

Переваги:

* Дуже компактна: ідеально підходить для планшетів та мобільних пристроїв.
* Добре підходить для мережевих рішень: два гігабітні Ethernet порти.
* GPIO на місці — для підключення сенсорів і модулів.

Недоліки:

* Обмежена мультимедійна підтримка: відсутній HDMI і роз'єм для дисплеїв.
* Немає PCIe і слотів для камер. -->

<!-- ### Висновки розділу  2.2

BladeRF  — це найкращий вибір для пристрою захоплення радіосигналу завдяки поєднанню широкого частотного діапазону (47 МГц – 6 ГГц), підтримки повноцінного прийому та передачі (2×2 MIMO), високої якості сигналу та сучасної елементної бази (FPGA Cyclone V, USB 3.0). BladeRF забезпечує більшу гнучкість у налаштуванні, стабільну роботу навіть у складних умовах, а також підтримку професійних інтерфейсів і програмного забезпечення (GNURadio, SDR#, SoapySDR тощо). Завдяки екрануванню, можливості автономної роботи, розширеним функціям живлення та високій точності синхронізації, bladeRF деально підходить для мобільних і польових рішень, де важливі надійність, продуктивність і масштабованість. У порівнянні з іншими SDR-пристроями, він пропонує оптимальний баланс між функціональністю, якістю та можливістю розширення, що робить його найкращим вибором для даного проєкту.

Попри наявність конкурентів, Raspberry Pi Compute Module 5 залишається найкращим вибором для через баланс між продуктивністю, гнучкістю, широкою підтримкою та стабільністю. Його багаторічна репутація, величезна спільнота користувачів, сумісність з великою кількістю периферійних модулів і чудова документація роблять його ідеальним ядром для проєктів, де важливі стабільність, підтримка і масштабованість.

NEO-6M v2 — це перевірене, надійне та доступне рішення для проєктів, де важлива точність позиціювання та простота інтеграції. Він має відкриту документацію, велику спільноту підтримки, добре працює з Raspberry Pi, Arduino і STM32, а також легко підключається до зовнішньої активної антени. На відміну від новіших моделей (M8N, L86), NEO-6M не потребує додаткового програмного налаштування, що робить його найкращим варіантом для прототипів і польових DIY-рішень із фокусом на стабільну роботу та простоту.

Transcend MTS420S забезпечує ідеальний баланс розміру (2242), швидкості, енергоефективності та надійності. У порівнянні з KingSpec, він має значно вищу якість збірки і стабільність роботи, а на відміну від рішень формату 2280 (як ADATA SU650), легко інтегрується в компактні проєкти, зокрема планшети. Крім того, підтримка 3D NAND TLC гарантує довший термін служби без шкоди для продуктивності. Це робить Transcend MTS420S найкращим вибором для польових і DIY-рішень, де важливі компактність, надійність та витривалість.

Цей дисплей виділяється завдяки підтримці активного стилуса з технологією Wacom, що забезпечує високу точність введення, критичну для військових або інженерних додатків, картографії та роботи в складних умовах. Його співвідношення сторін (4:3) зручно для читання технічної документації та створення інтерфейсів, орієнтованих на точність, а не на розваги. Крім того, його корпус і призначення дозволяють використовувати дисплей у надійних польових рішеннях, що робить його кращим варіантом серед альтернатив.

Після аналізу властивостей Li-ion акумуляторів, найбільш доцільним вибором є використання літій-полімерної (Li-Pol) батареї. Такий тип живлення добре зарекомендував себе у портативних пристроях завдяки ряду переваг: високій ємності та продуктивності, компактним розмірам і тонкому профілю, невеликій вазі, низькому саморозряду, відсутності вираженого ефекту пам’яті, підвищеній безпеці, екологічності та широкій доступності. Враховуючи енергетичні потреби розробленого пристрою, оптимальним рішенням стане застосування шести Li-Pol акумуляторів ємністю 10000 мА·год, 3,7 В, з’єднаних у відповідності до електричної схеми (послідовно та паралельно для забезпечення необхідних режимів заряджання і розряджання).

Compute Module 5 IO Board — це еталонна плата від Raspberry Pi Foundation, яка надає найбільшу гнучкість для розробників. Вона підтримує всі ключові інтерфейси, включно з PCIe, двома камерами, двома дисплеями, PoE та великим числом GPIO. Завдяки офіційній підтримці, надійності та великій кількості доступної документації, ця плата є найкращою базою для побудови прототипів і повноцінних DIY-пристроїв. Однак для досягнення оптимального результату у фінальному пристрої доцільно розробити власну материнську плату, яка буде враховувати специфічні вимоги проєкту: компактність, розташування розʼємів, мінімізацію зайвих компонентів та оптимізацію енергоспоживання. Власна плата дозволить інтегрувати лише необхідні інтерфейси, зменшити габарити та вагу пристрою, а також підвищити надійність і зручність експлуатації у польових умовах.

У цьому розділі було розглянуто основні компоненти, які можуть бути використані для побудови проекту. Raspberry Pi Compute Module 5 забезпечує високу продуктивність і гнучкість, а Compute Module 5 IO Board розширює можливості підключення периферійних пристроїв. Сенсорний дисплей IBM Lenovo Wacom дозволяє створювати інтерактивні інтерфейси, а HackRF-One відкриває можливості для роботи з радіочастотними сигналами. USB карта відеозахоплення LUX EasyCap є бюджетним рішенням для захоплення відео, а SSD диск Transcend MTS420S забезпечує швидке та надійне зберігання даних. Кожен із цих компонентів має свої переваги та недоліки, що слід враховувати при виборі елементної бази для конкретного застосування. -->

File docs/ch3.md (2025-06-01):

# **МЕТОДОЛОГІЯ РОБОТИ АПКВАР**

У цьому розділі розглядаються основні підходи, інструменти та принципи, що використовуються при розробці та дослідженні автоматизованої програмно-керованої варіантної радіосистеми (АПКВАР). Описано вибір апаратних і програмних засобів, методи збору, обробки та аналізу даних, а також обґрунтовано застосування сучасних технологій, таких як SDR і алгоритми штучного інтелекту. Особлива увага приділяється практичним аспектам реалізації системи, що забезпечують її гнучкість, масштабованість і надійність у різних умовах експлуатації.

## Загальні принципи роботи SDR

Програмно-визначуване радіо (SDR, Software-Defined Radio)
>>> Tranter, W. H., Reed, J. H., Fette, B. A. Software Defined Radio: Enabling Technologies. Hoboken : Wiley-Interscience, 2008. 416 p.
є новітньою концепцією в галузі радіозв’язку, що дозволяє виконувати більшість функцій традиційного радіоприймача програмними засобами. Головний принцип — перетворення аналогового сигналу в цифровий одразу після приймання та подальшій обробці цього сигналу програмно, що забезпечує виняткову гнучкість системи.

Сучасні SDR-системи складаються з високошвидкісного аналого-цифрового перетворювача (АЦП), цифрового сигнального процесора (DSP), комп’ютера або мікроконтролера та ПЗ обробки сигналів. Це дозволяє змінювати параметри приймання та обробки сигналу, такі як частота, тип модуляції, смуга пропускання та інші, без втручання в апаратну частину системи
>>>Couch, L. W. Digital and Analog Communication Systems. 8th ed. Boston : Pearson, 2013. 736 p.
.

У праці 
>>> Mahmoud S. A., Ismail A. A., Elhoseny M. et al. Software defined radio: operation, challenges and possible solutions \[Електронний ресурс] // International Journal of Communication Networks and Information Security. — 2016. — Т. 8, № 3. — Режим доступу: https://www.researchgate.net/publication/309777143
підкреслюється, що одним з головних викликів при реалізації SDR є необхідність використання надшвидких процесорів, здатних обробляти в реальному часі великі обсяги цифрової інформації. Також важливу роль відіграє точність АЦП та вибір аналогового фронтенду — першого каскаду приймання сигналу.

Апаратні платформи SDR
>>> Mitola, J. Software Radios: Architecture, Systems and Functions. New York : Wiley, 2000. 576 p.

Найбільш поширеною платформою для побутового та дослідницького використання є RTL-SDR — недорогий USB-тюнер на базі мікросхеми RTL2832U. Цей пристрій здатен приймати сигнали в діапазоні від 24 МГц до 1766 МГц. Завдяки відкритим драйверам та підтримці великої кількості програмного забезпечення (наприклад, SDR# або GQRX), RTL-SDR знайшов широке застосування у багатьох проєктах.

У дослідженні 
>>> Khan S., Anjum M., Masood A. Receiving ADS-B Signals on Embedded Linux using RTL-SDR: A Practical Guide \[Електронний ресурс] // Frontiers in Computer and Information Science. — 2022. — Т. 2, № 2. — Режим доступу: https://drpress.org/ojs/index.php/fcis/article/view/14059
було описано використання RTL-SDR на вбудованій Linux-системі для прийому сигналів авіаційної служби спостереження ADS-B. Автори навели практичні аспекти конфігурації та прийому, що є цінним для розробників портативних систем спостереження.

Іншою поширеною платформою є HackRF One — одноканальний SDR трансивер з діапазоном частот від 1-6 гіга герц. Його відкритий дизайн дозволяє глибоку модифікацію як на рівні прошивки, що робить його привабливим для науковців і розробників військових рішень.

Техніки приймання слабких сигналів

Однією з переваг SDR є можливість ефективного приймання слабких сигналів за умов наявності сильних перешкод. У роботі
>>> McFarlin D. Weak Signal Reception Using Software Defined Radios and a Two-Element Antenna Array \[Електронний ресурс] : дис. ... M.Sc. — Auburn University, 2009. — Режим доступу: https://holocron.lib.auburn.edu/handle/10415/613
досліджено використання двоелементного антеного масиву у поєднанні з адаптивними алгоритмами цифрової обробки сигналів для покращення співвідношення сигнал/шум. Запропонована система продемонструвала здатність до просторового фільтрування сигналів та зменшення впливу завад.

Цей підхід особливо актуальний у військових системах зв’язку, де часто необхідно приймати сигнали зі слабкою потужністю на фоні активного радіоелектронного протиборства.

SDR як засіб тестування вразливостей

Завдяки широкому діапазону частот та можливості генерувати сигнали, SDR використовується також для тестування захищеності радіосистем. У статті 
>>> Zhang Y., Zhao J., Zhang W. GPS Signal Reception and Spoofing Based on Software-Defined Radio Devices // ResearchGate. — 2023. Vol. 10, No. 7.  — DOI: https://10.1109/RIVF55975.2022.10013839
представлено реалізацію атаки типу spoofing на GPS-приймач з використанням SDR-пристрою. За допомогою генерації синтетичних GPS-сигналів дослідники змогли обдурити навігаційний модуль пристрою Android, змусивши його визначити фальшиве місцеположення.

Цей приклад показує як SDR може застосовуватись не лише для приймання сигналів, а й для їх аналізу, генерації та модифікації з метою підвищення безпеки систем навігації.

Інтеграція SDR з елементами штучного інтелекту

Сучасні дослідження активно впроваджують машинне навчання в SDR-системи. У публікації 
>>> Mihai C., Gontean A., Rusu C. Signals Intelligence System with Software-Defined Radio // Applied Sciences. — 2023. — Vol. 13, No. 8. — DOI: https://doi.org/10.3390/app13085199
описано систему інтелектуального аналізу сигналів, що здатна автоматично визначати протокол кодування за допомогою ШІ. Для цього було використано хмарну інфраструктуру Microsoft Azure, що забезпечило масштабованість та високу продуктивність.

Використання методів штучного інтелекту дає змогу автоматизувати аналіз спектра радіочастот і виявлення нетипових сигналів, що особливо важливо для задач радіоелектронної протидії або оперативного моніторингу ефіру.

Приклад застосування: аналіз Wi-Fi сигналів

Технологія SDR також може використовуватись для вивчення сигналів побутових бездротових систем. У дослідженні 
>>> Kumar R., Prasad M. Analysis of Wi-Fi Signal Transmission and Reception Using Software-Defined Radio \[Електронний ресурс] // International Journal of Multidisciplinary Research. — 2022. — Режим доступу: https://www.multiresearchjournal.com/admin/uploads/archives/archive-1743160648.pdf
описано методику аналізу потужності Wi-Fi сигналу при наявності різних фізичних перешкод. Було встановлено, що тіло людини значною мірою впливає на стабільність з’єднання, особливо при використанні спрямованих антен.

У статті також було вивчено ефективність односторонньої передачі даних в умовах обмеженого покриття, що може бути корисним у створенні енергоефективних мереж для IoT-пристроїв.

Висновки до розділу

SDR є потужним інструментом для побудови гнучких і адаптивних систем зв’язку. Завдяки програмній реалізації основних функцій приймання та обробки сигналу, SDR дає можливість створювати пристрої з широким спектром можливостей: від простого радіоприймача до складної системи аналізу ефіру з використанням штучного інтелекту. Застосування SDR у військових, наукових та побутових системах підтверджує його універсальність та перспективність.

## Приймання та обробка радіосигналів за допомогою технології SDR

Загальні принципи роботи SDR

Програмно-визначуване радіо (SDR, Software-Defined Radio) — це концепція, яка передбачає реалізацію основних функцій радіоапаратури за допомогою програмного забезпечення. Традиційні радіоприймачі використовують апаратні фільтри, модулятори та демодулятори. У SDR більшість цих функцій виконується програмно після оцифрування можлиовстями АЦП.

Основні складові SDR-системи.

* Аналоговий фронтенд: приймає сигнал з ефіру і подає його на АЦП.
* АЦП: перетворює аналоговий сигнал у цифрову форму.
* Цифровий сигнальний процесор (DSP) або ЦП/ГП комп’ютера: виконує фільтрацію, демодуляцію, декодування.
* Програмне забезпечення: забезпечує візуалізацію, обробку та збереження сигналів.

Програмне забезпечення для обробки SDR-сигналів

Для повноцінної роботи з SDR використовуються різні програми, які мають широкий функціонал і застосовуються для різних задач: спостереження за спектром, демодуляції, запису, декодування цифрових протоколів, аналізу тощо.

[SDR#](https://airspy.com/download/) — популярна Windows-програма обробки сигналу SDR.

* Спектр та waterfall.
* AM, FM, SSB, CW, WFM, NFM демодуляція.
* Плагіни: декодування AIS, ADS-B, TETRA, DMR тощо.
* Запис сигналів у WAV/IQ форматах.
* Підтримка вбудованих фільтрів, зміщення частоти, автоналаштування.

ПЗ SDR#

[GQRX](https://www.gqrx.dk/) — кросплатформний SDR-інтерфейс на базі GNU Radio для Linux/macOS.

* Графічний інтерфейс з FFT/Waterfall.
* AM/FM/SSB/CW/RAW демодуляція.
* Запис аудіо та IQ-даних.
* Підтримка RTL-SDR, HackRF, USRP, BladeRF, PlutoSDR тощо.

ПЗ GQRX

[GNU Radio](https://www.gnuradio.org/) — фреймворк для створення SDR-додатків у вигляді графічного середовища (GRC)
>>> Blossom, E. GNU Radio: Tools for Exploring the Radio Frequency Spectrum. // Linux Journal. – 2004. – Vol. 2004, No. 122. – [Електронний ресурс]. – Режим доступу: https://www.linuxjournal.com/article/7505
.

* Побудова потоку обробки сигналу з блоків: джерело, фільтр, демодулятор, декодер.
* Підтримка мови Python для користувацької логіки.
* Застосовується для наукових, військових, комерційних задач.
* Можливість симуляції складних систем (MIMO, фазовий масив, модуляція QAM, OFDM тощо).

ПЗ GNU Radio

[Universal Radio Hacker](https://github.com/jopohl/urh) — інструмент для аналізу цифрових протоколів.

* Захоплення, перегляд, декодування і повторна передача сигналів.
* Аналіз бітових послідовностей, протоколів (манчестер, NRZ, ASK, OOK).
* Підтримка багатьох SDR пристроїв.

ПЗ Universal Radio Hacker

[Inspectrum](https://github.com/miek/inspectrum) — програма для аналізу IQ-сигналів.

* Розширене відображення спектру та фазового простору.
* Можливість розмітки імпульсів і виявлення манчестерського кодування.
* Застосовується для реверс-інжинірингу радіопротоколів.

ПЗ Inspectrum

<!-- [SDR++](https://github.com/AlexandreRouma/SDRPlusPlus) — легкий, мультиплатформний SDR клієнт.

* Працює під Windows, macOS, Linux.
* Підтримка декількох SDR одночасно.
* Швидкий спектрограф, підтримка плагінів.

![ПЗ SDR++](imgs/image-11.png) -->

<!-- [SigDigger](https://batchdrake.github.io/SigDigger/) — аналітична SDR-програма з підтримкою широкого спектру сигналів.

* FFT, демодуляція, запис.
* Підтримка векторного аналізу та власних демодуляторів.

![ПЗ SigDigger](imgs/image-33.png) -->

Audacity та інші звукові редактори

Для аналізу та обробки демодульованого сигналу у форматі WAV використовують звукові редактори, наприклад [Audacity](https://www.audacityteam.org/).

ПЗ Audacity

* Розгортка сигналу по часу.
* Спектральний аналіз.
* Виділення, вирізання, фільтрація підсигналів.

Обробка сигналу в SDR-системах відбувається поетапно: спочатку здійснюється приймання сигналу з ефіру з вибором необхідної частоти та смуги пропускання, після чого аналоговий сигнал перетворюється в цифровий (IQ-дані) за допомогою АЦП. Далі проводиться попередня обробка — фільтрація (наприклад, низькочастотна або смуговапропускна), усунення частотного зміщення та нормалізація амплітуди. Після цього демодуляція відповідно до типу сигналу (AM, FM, SSB, FSK, QAM, PSK) для виділення корисної інформації — аудіо або даних. Після цього дані декодуються: бітові потоки інтерпретуються у вигляді пакетів чи протоколів, які можуть бути представлені у текстовому або графічному форматі. Завершальним етапом є аналіз і зберігання результатів — збереження IQ-даних або аудіо для подальшої обробки, побудова спектрограм, логів чи діаграм для детального аналізу сигналів.

Обробка сигналів, отриманих через SDR, є гнучким, адаптивним процесом, що може бути автоматизований і масштабований. Завдяки розвинутому набору інструментів, користувач може аналізувати ефір у реальному часі, виявляти цифрові сигнали, тестувати протоколи, а також здійснювати зворотну інженерію. SDR — це інструмент не лише для спостереження, а й для глибокого розуміння принципів роботи сучасних радіосистем.
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

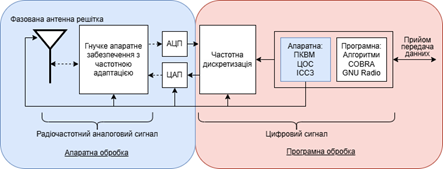
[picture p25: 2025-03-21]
docs/imgs/thesis.png

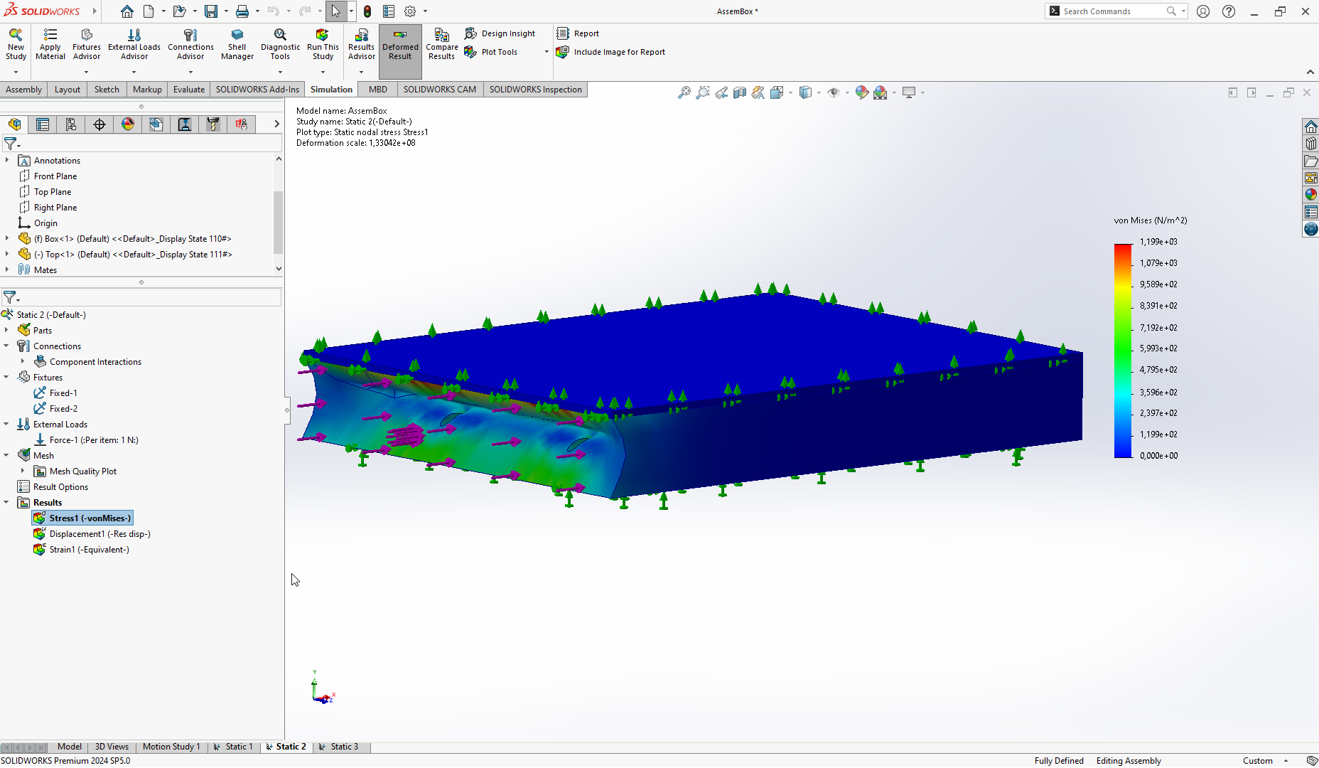
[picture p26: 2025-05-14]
docs/imgs/Solid/Static_2_1.png

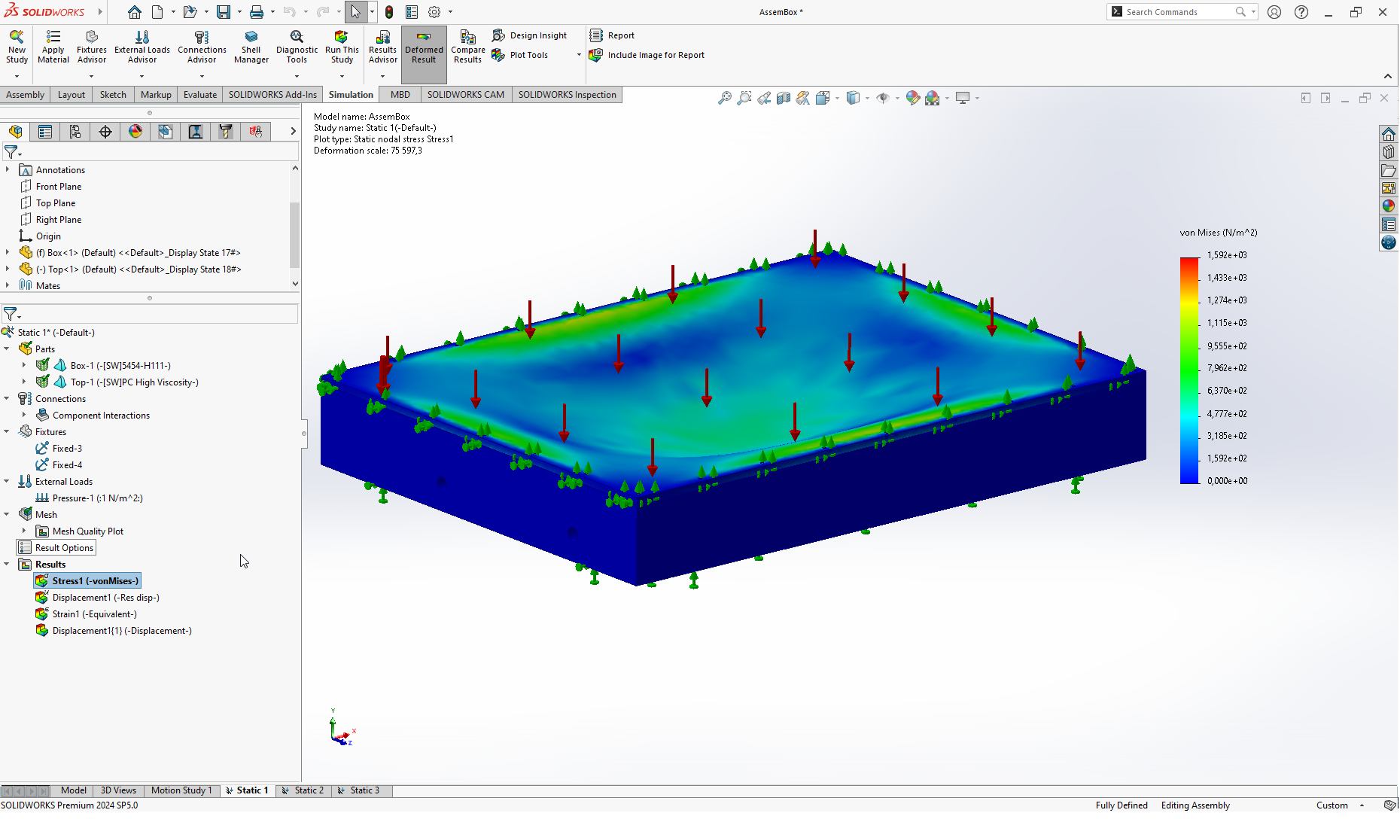
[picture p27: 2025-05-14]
docs/imgs/Solid/Static_1_1.png

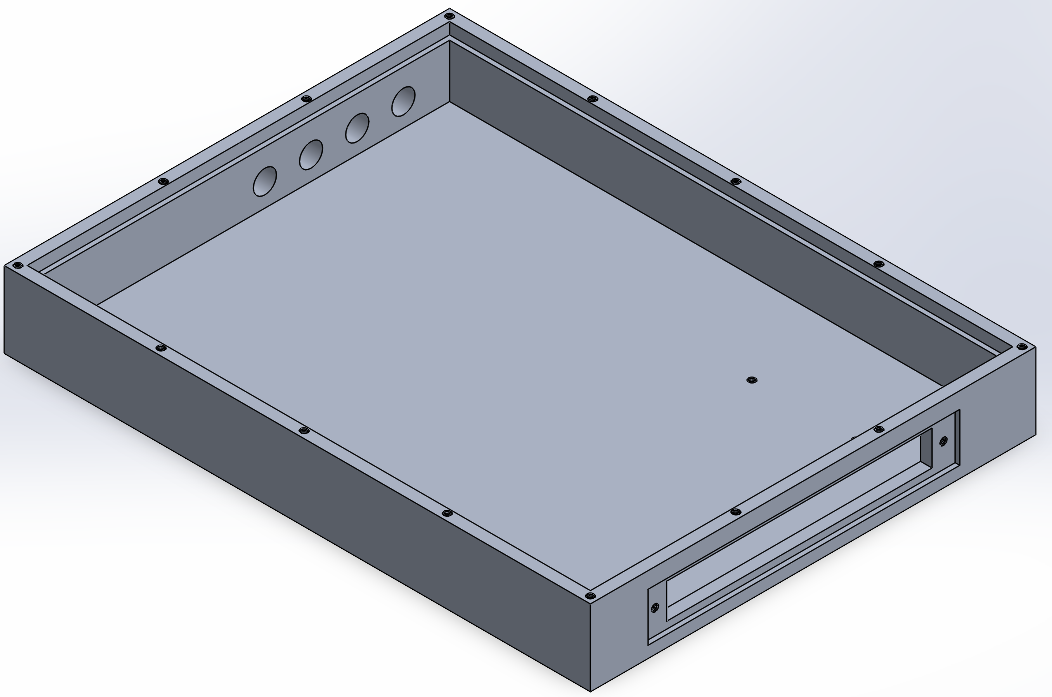
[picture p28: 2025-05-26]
docs/imgs/Solid/Box.png

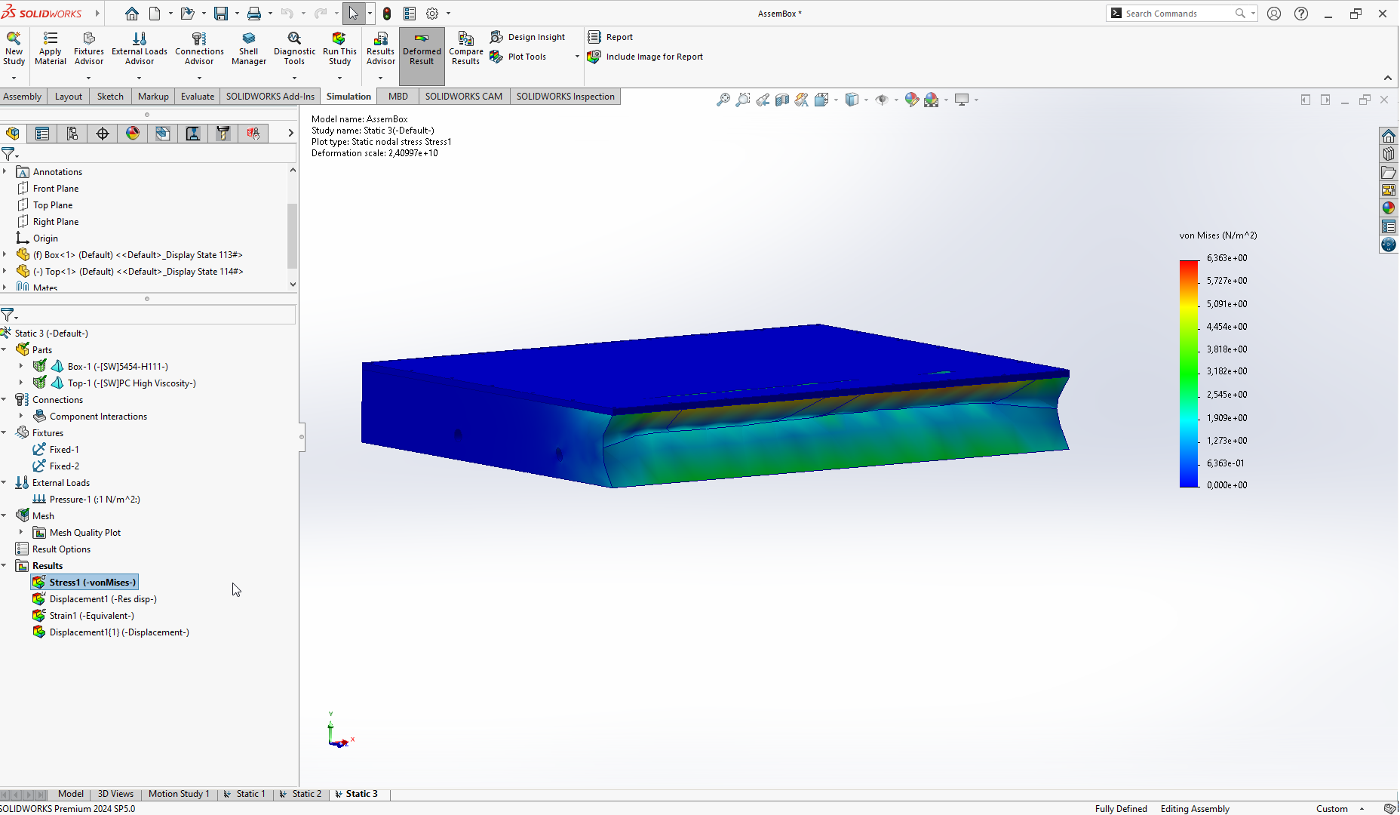
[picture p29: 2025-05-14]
docs/imgs/Solid/Static_3_1.png

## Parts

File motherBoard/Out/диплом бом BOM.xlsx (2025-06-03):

Позиція | Позначення | Найменування | Кількість | Примітки |  |  | Примітка
 |  | Конденсатори
C1, C9, C10, C12, C13, C18, C19, C57, C58 |  | Конденсатор керамічний 100n, типорозмір: 0402, ISO 60384-1 / ДСТУ Б В.2.7-245:2010 | 9 |  | Конденсатор керамічний 100n | ISO 60384-1 / ДСТУ Б В.2.7-245:2010 | типорозмір: 0402
C5-8, C14, C21, C47, C49, C51, C54-56, C62-67 |  | Конденсатор керамічний 10u, типорозмір: 0805, ISO 60384-1 / ДСТУ Б В.2.7-245:2010 | 18 |  | Конденсатор керамічний 10u | ISO 60384-1 / ДСТУ Б В.2.7-245:2010 | типорозмір: 0805
C11 |  | Конденсатор керамічний 4.7nF, типорозмір: 0402, ISO 60384-1 / ДСТУ Б В.2.7-245:2010 | 1 |  | Конденсатор керамічний 4.7nF | ISO 60384-1 / ДСТУ Б В.2.7-245:2010 | типорозмір: 0402
C20 |  | Конденсатор танталовий 100uF, типорозмір: EIA-7343-31, ISO 60384-3 | 1 |  | Конденсатор танталовий 100uF | ISO 60384-3 | типорозмір: EIA-7343-31
C34, C37, C39 |  | Конденсатор керамічний 10u 35V, типорозмір: 0805, ISO 60384-1 / ДСТУ Б В.2.7-245:2010 | 3 |  | Конденсатор керамічний 10u 35V | ISO 60384-1 / ДСТУ Б В.2.7-245:2010 | типорозмір: 0805
C36 |  | Конденсатор керамічний 100n 100V, типорозмір: 0402, ISO 60384-1 / ДСТУ Б В.2.7-245:2010 | 1 |  | Конденсатор керамічний 100n 100V | ISO 60384-1 / ДСТУ Б В.2.7-245:2010 | типорозмір: 0402
C59, C61 |  | Конденсатор керамічний (nf), типорозмір: 0402, ISO 60384-1 / ДСТУ Б В.2.7-245:2010 | 2 |  | Конденсатор керамічний (nf) | ISO 60384-1 / ДСТУ Б В.2.7-245:2010 | типорозмір: 0402
C60 |  | Конденсатор керамічний 1.2nF, типорозмір: 0402, ISO 60384-1 / ДСТУ Б В.2.7-245:2010 | 1 |  | Конденсатор керамічний 1.2nF | ISO 60384-1 / ДСТУ Б В.2.7-245:2010 | типорозмір: 0402
D4-6 |  | Діод Зенера (D_Zener), типорозмір: 0603, ДСТУ 2449-94 / ISO 19077 | 3 |  | Діод Зенера (D_Zener) | ДСТУ 2449-94 / ISO 19077 | типорозмір: 0603
 |  | Роз'єми
J1, J3 |  | Роз'єм USB3_A, Molex_48393-001, ISO/IEC 14472 | 2 |  | Роз'єм USB3_A | ISO/IEC 14472 | Molex_48393-001
BT1 |  | Елемент живлення, Тримач: Keystone_3034_1x20mm, ДСТУ EN 61204:2016 / ISO 61204 | 1 |  | Елемент живлення | ДСТУ EN 61204:2016 / ISO 61204 | Тримач: Keystone_3034_1x20mm
J2 |  | З'єднувач штирьовий (Conn_02x07_Odd_Even), PinHeader_2x07_P2.54mm_Vertical, ДСТУ IEC 603-7/ ISO 14472 | 1 |  | З'єднувач штирьовий (Conn_02x07_Odd_Even) | ДСТУ IEC 603-7/ ISO 14472 | PinHeader_2x07_P2.54mm_Vertical
J4 |  | Роз'єм Bus_M.2_Socket_M, ISO/IEC 14472 | 1 |  | Роз'єм Bus_M.2_Socket_M | ISO/IEC 14472 | -
J5 |  | З'єднувач гнучкий (Conn_01x22_Female), Hirose_FH12-22S-0.5SH, ДСТУ EN 12094-8 / ISO 14472 | 1 |  | З'єднувач гнучкий (Conn_01x22_Female) | ДСТУ EN 12094-8 / ISO 14472 | Hirose_FH12-22S-0.5SH
J6 |  | Роз'єм USB-C (USB_C_Receptacle_USB2.0_14P), GCT_USB4135-GF-A, ISO/IEC 14472 | 1 |  | Роз'єм USB-C (USB_C_Receptacle_USB2.0_14P) | ISO/IEC 14472 | GCT_USB4135-GF-A
J7 |  | Роз'єм Micro_SD_Card_Det, MOLEX_503398-1892, ISO/IEC 14472 | 1 |  | Роз'єм Micro_SD_Card_Det | ISO/IEC 14472 | MOLEX_503398-1892
J8 |  | Аудіороз'єм (AudioJack4), CUI_SJ1-3535NG, ISO/IEC 29193 / ISO 14472 | 1 |  | Аудіороз'єм (AudioJack4) | ISO/IEC 29193 / ISO 14472 | CUI_SJ1-3535NG
J11 |  | Роз'єм USB-C (USB_C_Receptacle_USB2.0), GCT_USB4105-xx-A, ISO/IEC 14472 | 1 |  | Роз'єм USB-C (USB_C_Receptacle_USB2.0) | ISO/IEC 14472 | GCT_USB4105-xx-A
J19 |  | Роз'єм живлення (Barrel_Jack), GCT_DCJ200-10-A, ISO/IEC 14472 | 1 |  | Роз'єм живлення (Barrel_Jack) | ISO/IEC 14472 | GCT_DCJ200-10-A
J22 |  | З'єднувач (690-019-298-412), EDAC 690-019-298-412, ISO/IEC 14472 | 1 |  | З'єднувач (690-019-298-412) | ISO/IEC 14472 | EDAC 690-019-298-412
 |  | Ідуктивності
L1 |  | Індуктивність 2.2uH, Bourns_SRP5030CC, ДСТУ EN 60310:2022 / ISO 60310 | 1 |  | Індуктивність 2.2uH | ДСТУ EN 60310:2022 / ISO 60310 | Bourns_SRP5030CC
L5, L6 |  | Індуктивність SRN6045TA-3R3Y, Bourns_SRN6045TA, ДСТУ EN 60310:2022 / ISO 60310 | 2 |  | Індуктивність SRN6045TA-3R3Y | ДСТУ EN 60310:2022 / ISO 60310 | Bourns_SRN6045TA
 |  | Резистори
R2, R3 |  | Резистор 470R, типорозмір: 0402, ДСТУ 7953:2015 / ISO 60115 | 2 |  | Резистор 470R | ДСТУ 7953:2015 / ISO 60115 | типорозмір: 0402
R9, R16, R28 |  | Резистор 2.2K 1%, типорозмір: 0402, ДСТУ 7953:2015 / ISO 60115 | 3 |  | Резистор 2.2K 1% | ДСТУ 7953:2015 / ISO 60115 | типорозмір: 0402
R10, R22, R23, R24, R30, R31 |  | Резистор 10R, типорозмір: 0402, ДСТУ 7953:2015 / ISO 60115 | 6 |  | Резистор 10R | ДСТУ 7953:2015 / ISO 60115 | типорозмір: 0402
R14 |  | Резистор 100K, типорозмір: 0402, ДСТУ 7953:2015 / ISO 60115 | 1 |  | Резистор 100K | ДСТУ 7953:2015 / ISO 60115 | типорозмір: 0402
R15 |  | Резистор 10K 1%, типорозмір: 0402, ДСТУ 7953:2015 / ISO 60115 | 1 |  | Резистор 10K 1% | ДСТУ 7953:2015 / ISO 60115 | типорозмір: 0402
R25 |  | Резистор 20K 1%, типорозмір: 0402, ДСТУ 7953:2015 / ISO 60115 | 1 |  | Резистор 20K 1% | ДСТУ 7953:2015 / ISO 60115 | типорозмір: 0402
R27 |  | Резистор 12K 1%, типорозмір: 0402, ДСТУ 7953:2015 / ISO 60115 | 1 |  | Резистор 12K 1% | ДСТУ 7953:2015 / ISO 60115 | типорозмір: 0402
R34 |  | Резистор 12K, типорозмір: 0402, ДСТУ 7953:2015 / ISO 60115 | 1 |  | Резистор 12K | ДСТУ 7953:2015 / ISO 60115 | типорозмір: 0402
R35 |  | Резистор 10K, типорозмір: 0402, ДСТУ 7953:2015 / ISO 60115 | 1 |  | Резистор 10K | ДСТУ 7953:2015 / ISO 60115 | типорозмір: 0402
R37 |  | Резистор 0.5K, типорозмір: 0402, ДСТУ 7953:2015 / ISO 60115 | 1 |  | Резистор 0.5K | ДСТУ 7953:2015 / ISO 60115 | типорозмір: 0402
R38 |  | Резистор 1K, типорозмір: 0402, ДСТУ 7953:2015 / ISO 60115 | 1 |  | Резистор 1K | ДСТУ 7953:2015 / ISO 60115 | типорозмір: 0402
R39 |  | Резистор 18K, типорозмір: 0402, ДСТУ 7953:2015 / ISO 60115 | 1 |  | Резистор 18K | ДСТУ 7953:2015 / ISO 60115 | типорозмір: 0402
 |  | Модулі:
U1, U2 |  | Мікросхема TPD4EUSB30, корпус: USON-10_2.5x1.0mm_P0.5mm, ISO/IEC 14472 | 2 |  | Мікросхема TPD4EUSB30 | ISO/IEC 14472 | корпус: USON-10_2.5x1.0mm_P0.5mm
U3 |  | MagJack-A70-112-331N126, TRJG0926HENL, ISO/IEC 14472 | 1 |  | MagJack-A70-112-331N126 | ISO/IEC 14472 | TRJG0926HENL
U4 |  | Мікросхема WM8960, корпус: QFN-32-1EP_5x5mm_P0.5mm, ISO/IEC 14472 | 1 |  | Мікросхема WM8960 | ISO/IEC 14472 | корпус: QFN-32-1EP_5x5mm_P0.5mm
U5 |  | Модуль GPS NEO-6M, ДСТУ EN ISO 1101:2018 / ISO 19133 | 1 |  | Модуль GPS NEO-6M | ДСТУ EN ISO 1101:2018 / ISO 19133 | -
U6 |  | Модуль GPS NEO-6M , PinHeader_1x04_P2.54mm_Vertical, ДСТУ EN ISO 1101:2018 / ISO 19133 | 1 |  | Модуль GPS NEO-6M | ДСТУ EN ISO 1101:2018 / ISO 19133 | PinHeader_1x04_P2.54mm_Vertical
U7 |  | Кварцовий резонатор 32.768KHZ, типорозмір: 3225-4Pin_3.2x2.5mm, ДСТУ 3113-95 / ISO 12046 | 1 |  | Кварцовий резонатор 32.768KHZ | ДСТУ 3113-95 / ISO 12046 | типорозмір: 3225-4Pin_3.2x2.5mm
U8 |  | Мікросхема AP3441SHE-7B, корпус: DFN-8-1EP_2x2mm_P0.5mm, ISO/IEC 14472 | 1 |  | Мікросхема AP3441SHE-7B | ISO/IEC 14472 | корпус: DFN-8-1EP_2x2mm_P0.5mm
U10, U11 |  | Модуль живлення BK-18650-PC4, ДСТУ EN 61204:2016/ ISO 61204 | 1 |  | Модуль живлення BK-18650-PC4 | ДСТУ EN 61204:2016/ ISO 61204
U12 |  | Мікросхема RT9742SNGV, корпус: TSOT-23, ISO/IEC 14472 | 1 |  | Мікросхема RT9742SNGV | ISO/IEC 14472 | корпус: TSOT-23
U16 |  | Мікросхема AP64501SP-13, корпус: SOIC-8-1EP, ISO/IEC 14472 | 1 |  | Мікросхема AP64501SP-13 | ISO/IEC 14472 | корпус: SOIC-8-1EP
U17 |  | Мікросхема IP2326, корпус: QFN-24-1EP_3x3mm_P0.4mm, ISO/IEC 14472 | 1 |  | Мікросхема IP2326 | ISO/IEC 14472 | корпус: QFN-24-1EP_3x3mm_P0.4mm
U18 |  | Мікросхема RT9742GGJ5, корпус: SOT-23-5, ISO/IEC 14472 | 1 |  | Мікросхема RT9742GGJ5 | ISO/IEC 14472 | корпус: SOT-23-5
Module1 |  | Обчислювальний модуль RPi CM5, ДСТУ 2229-93 / ISO/IEC 18000 | 1 |  | Обчислювальний модуль RPi CM5 | ДСТУ 2229-93 / ISO/IEC 18000

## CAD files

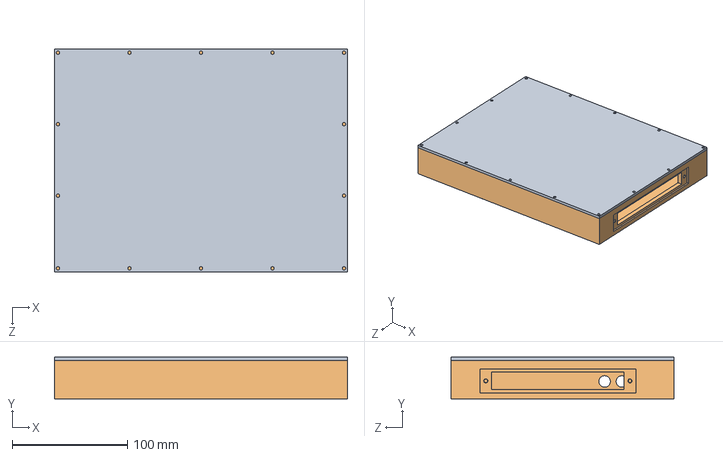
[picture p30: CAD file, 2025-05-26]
model/AssemBox.SLDASM
254.0 x 36.0 x 193.0 mm
Top

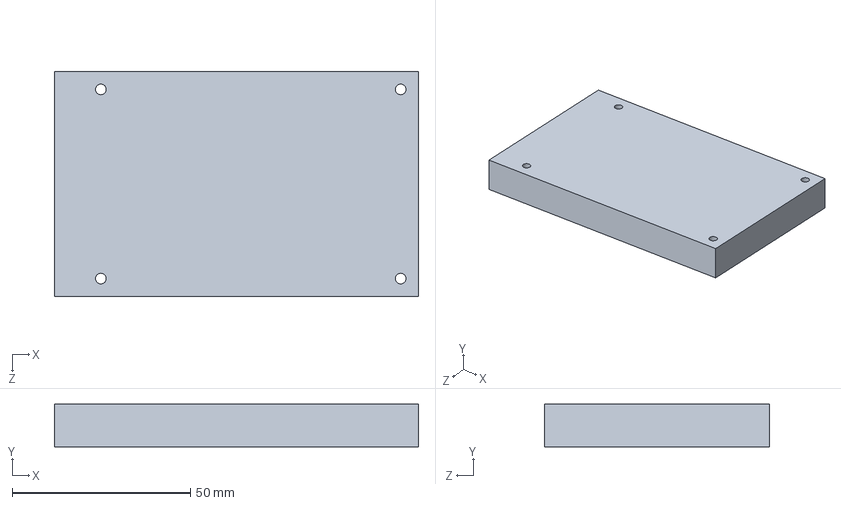
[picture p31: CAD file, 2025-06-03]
model/bladerf.SLDPRT
102.0 x 12.0 x 63.0 mm

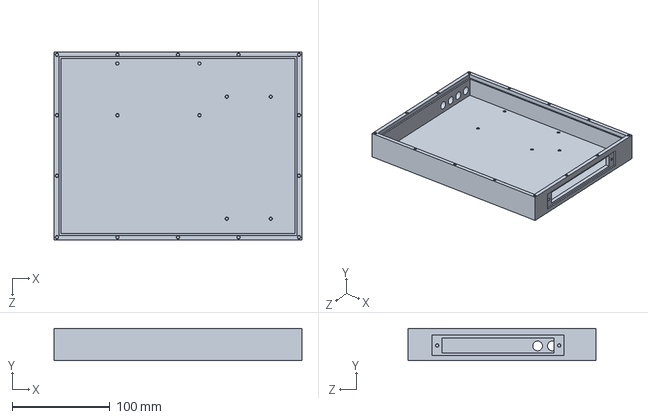
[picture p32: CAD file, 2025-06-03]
model/Box.SLDPRT
254.0 x 33.0 x 193.0 mm

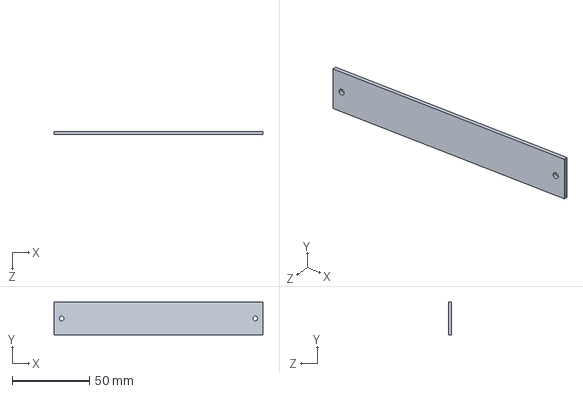
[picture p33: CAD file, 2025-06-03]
model/Cover.SLDPRT
135.0 x 21.0 x 2.00 mm

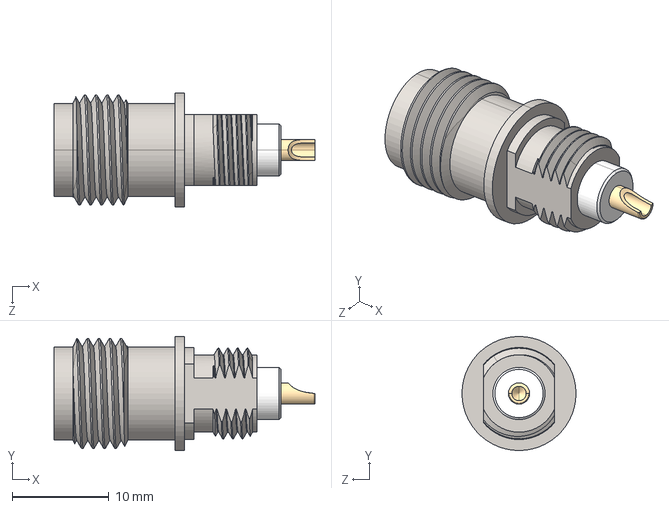
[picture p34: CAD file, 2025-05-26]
model/56K504-200N5 rev 2.STEP
27.0 x 11.8 x 11.8 mm

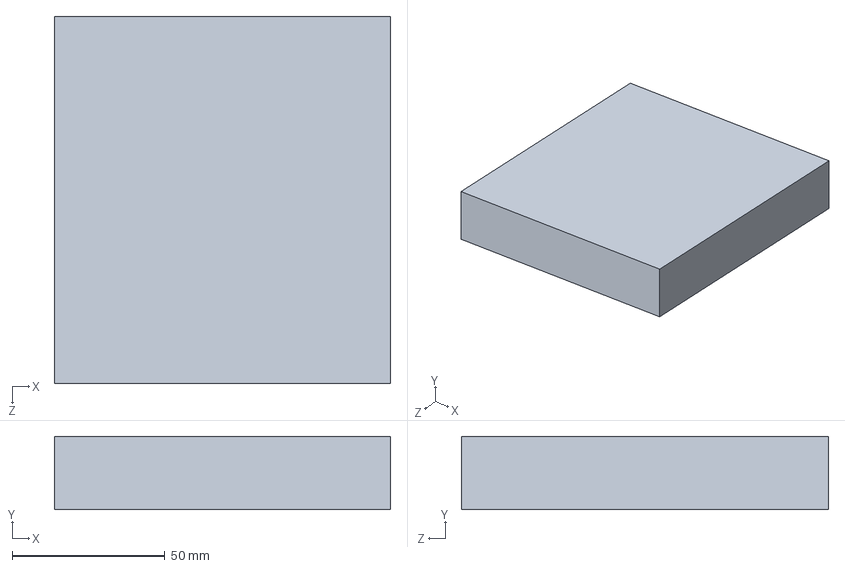
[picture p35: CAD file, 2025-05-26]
model/lIpOL.SLDPRT
110.0 x 24.0 x 120.0 mm

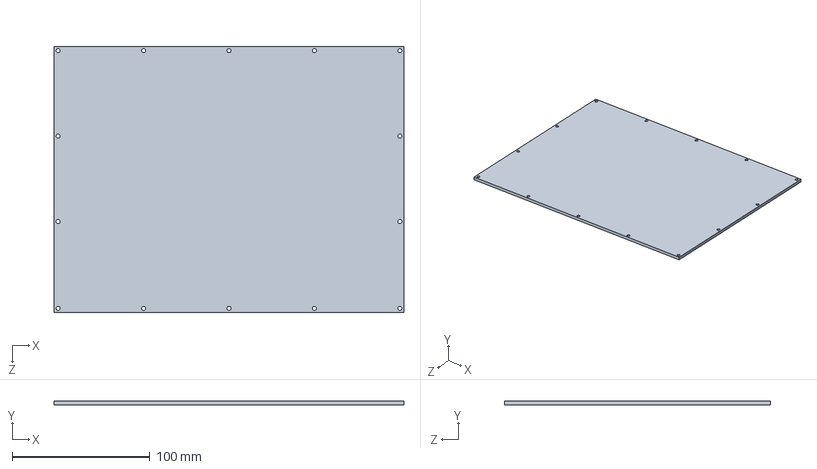
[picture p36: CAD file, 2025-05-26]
model/Top.SLDPRT
254.0 x 3.00 x 193.0 mm

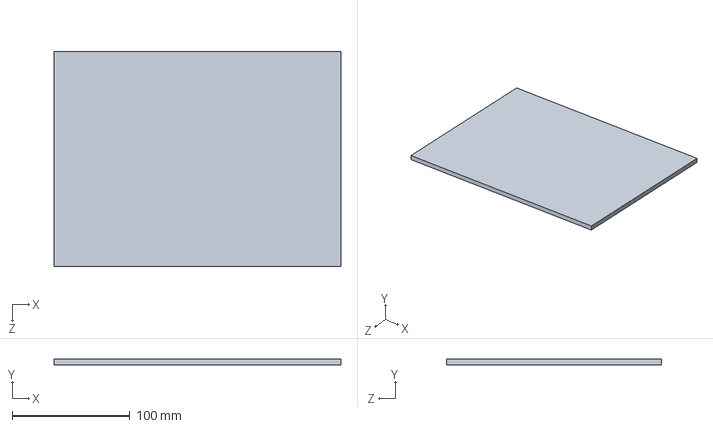
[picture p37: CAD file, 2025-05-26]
model/Screen.SLDPRT
244.0 x 5.00 x 183.0 mm

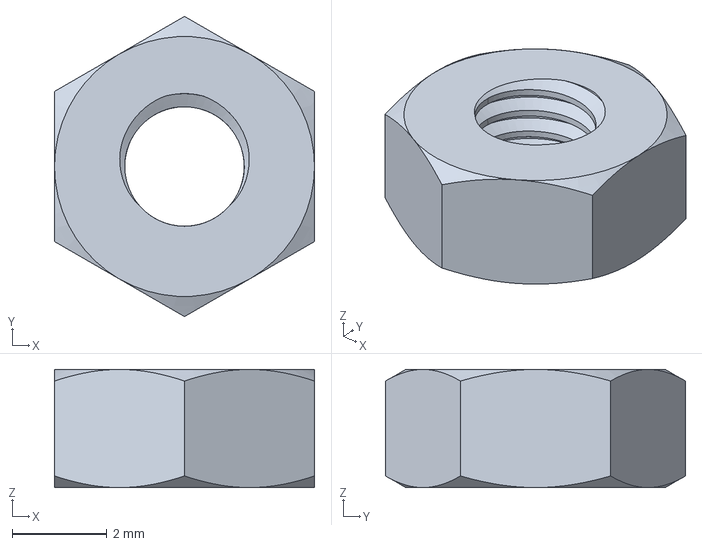
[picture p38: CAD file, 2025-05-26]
model/M3 Nut.step
5.50 x 6.35 x 2.50 mm

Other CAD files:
model/Box.SLDDRW
model/Cover.SLDDRW
model/M3 Nut.SLDPRT
model/Top.SLDDRW

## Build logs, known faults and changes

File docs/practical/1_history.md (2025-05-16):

# Історія створення та розвитку Інституту проблем міцності ім. Г.С. Писаренка

Інститут проблем міцності АН УРСР був заснований 14 вересня 1966 року за ініціативи академіка Г.С. Писаренка, який став його першим директором. Основа інституту — сектор міцності Інституту проблем матеріалознавства, що спеціалізувався на дослідженні міцності матеріалів в екстремальних умовах: високі й низькі температури, агресивні середовища, радіація, втома та повзучість матеріалів.

Ще до створення Інституту, у 1950-х роках Г.С. Писаренко сформував потужний науковий колектив, залучивши молодих фахівців, переважно випускників КПІ. У відділі міцності почали активно досліджувати властивості жароміцних і композиційних матеріалів для авіації, космосу та енергетики.

У 1960-х роках результати досліджень, зокрема в теорії нелінійних коливань і термостійкості, отримали міжнародне визнання, а науковці відділу здобули низку премій. У 1966 році сектор було виведено зі складу Інституту проблем матеріалознавства і перетворено на самостійний Інститут проблем міцності АН УРСР.

На момент створення Інституту там працювало 185 осіб, включно з одним академіком, двома докторами технічних наук та 24 кандидатами наук. Структура Інституту складалася з низки спеціалізованих наукових відділів, що охоплювали дослідження за високих і низьких температур, повзучості, термовтоми, імпульсних навантажень, звукових методів тощо.

Інститут став провідним центром фундаментальних і прикладних досліджень у галузі механіки матеріалів і конструкцій. Особлива увага приділялася створенню експериментального обладнання — стендів і установок, здатних імітувати екстремальні умови навантаження (до 3000 К, до 2000 атм, високочастотні цикли, вакуум, радіація тощо).

У 1969 році створено спеціалізовану вчену раду для захисту докторських і кандидатських дисертацій. Також інститут з 1969 року почав видавати міжнародний журнал «Проблемы прочности» (англ. «Strength of Materials»).

У 1970–1980-х роках інститут значно розширився — чисельність співробітників разом із СКТБ сягнула 1100 осіб. Створювались нові напрями досліджень, пов’язані з динамічною міцністю, ударними та вібраційними навантаженнями, термонавантаженнями, радіаційною міцністю тощо.

Окремо слід відзначити роботи з дослідження довговічності жароміцних матеріалів для авіаційної, енергетичної та космічної техніки. Розроблялись критерії граничного стану матеріалів при дії складних навантажень: теплових, вібраційних, циклічних.

Значну роль в успіхах Інституту відіграла постійна модернізація та розширення експериментальної бази. Створено газодинамічні стенди, вакуумні печі, установки для випробування у корозійних середовищах, пневмопорохові копри, реакторні установки для дослідження під радіацією тощо. Частина обладнання використовувалась також іншими науковими установами.

Розробки Інституту активно впроваджувались у ракетно-космічну галузь, атомну енергетику, машинобудування, оборонну промисловість. Інститут виконував координаційні функції в республіканських і загальносоюзних програмах підвищення надійності машин та споруд.

Починаючи з 1970-х років, особлива увага приділялася теоретичному моделюванню процесів руйнування: створено критерії крихкості, моделі зростання втомних тріщин, комп’ютерні експертні системи діагностики. Значну роль відіграв відділ математичного моделювання, який розробив програмне забезпечення для чисельного аналізу конструкцій у складних умовах.

Унікальним напрямом стало дослідження міцності скляних і керамічних елементів для глибоководної техніки. Розроблено наукові засади для створення глибоководних апаратів зі скла, ситалів і кераміки, придатних для занурення на глибини понад 10 км.

Інститут постійно взаємодіяв з провідними вченими СРСР і України, зокрема з Б.Є. Патоном, І.М. Францевичем, С.В. Серенсеном, Ю.А. Митропольським та ін. Продуктивна співпраця велась також із конструкторами нової техніки — М.Д. Кузнєцовим, О.К. Антоновим, М.К. Янгелем.

Інститут відіграв значну роль у розвитку механіки деформівного твердого тіла в Україні. На його базі функціонувала наукова рада при Відділенні механіки НАН України, а його співробітники неодноразово ставали лауреатами державних та академічних премій.

Ось запропонований розділ **«Інститут сьогодні»** для включення до вашої узагальненої версії:

### Інститут сьогодні

Сьогодні Інститут проблем міцності ім. Г.С. Писаренка НАН України залишається провідною науковою установою в галузі механіки деформівного твердого тіла, досліджень міцності матеріалів і конструкцій в екстремальних умовах. Установа поєднує глибокі фундаментальні дослідження з вирішенням прикладних завдань, що мають безпосереднє значення для розвитку авіаційної, космічної, енергетичної, транспортної та оборонної галузей.

Інститут підтримує широку тематику наукових досліджень, що включає:

* міцність і довговічність матеріалів за дії високих, низьких і змінних температур;
* повзучість, термо- і втомне руйнування конструкційних матеріалів;
* моделювання термонавантажених елементів;
* радіаційну міцність матеріалів;
* діагностику залишкового ресурсу обладнання енергетичних установок і промислових об'єктів;
* застосування методів механіки руйнування для аналізу критичних елементів конструкцій;
* математичне моделювання напружено-деформованого стану та створення комп’ютерних експертних систем.

Серед пріоритетних напрямів – дослідження матеріалів нового покоління, у тому числі наноматеріалів, жароміцних сплавів, композиційних матеріалів з теплозахисними властивостями, високотемпературної кераміки. В умовах сучасних викликів важливими залишаються також завдання підвищення надійності й довговічності об’єктів критичної інфраструктури, зокрема у військових і надзвичайних умовах.

Інститут активно бере участь у державних та міжнародних науково-технічних програмах, здійснює прикладні дослідження для промисловості, енергетики, оборони та безпеки. Підтримується співпраця з вітчизняними й зарубіжними академічними установами, університетами, виробничими підприємствами.

Наукова школа, заснована академіком Г.С. Писаренком, продовжує своє існування через учнів, послідовників та нові покоління дослідників. В Інституті функціонує аспірантура, діє спеціалізована вчена рада, публікується авторитетний міжнародний журнал «Проблеми міцності / Strength of Materials», що підтримує обмін науковою інформацією на міжнародному рівні.

Інститут зберігає статус центру, де поєднуються фундаментальна наука, інженерна творчість і практична спрямованість, і залишається важливою складовою науково-технологічного потенціалу України.

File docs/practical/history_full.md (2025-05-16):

# Історія створення та розвитку Інституту проблем міцності ім. Г.С. Писаренка НАН України. Г.С. Писаренка НАН України

## Створення наукового колективу та організація Інституту

Рішення про створення Інституту проблем міцності АН УРСР (нині Інститут
проблем міцності ім. Г.С. Писаренка Національної академії наук України)
було прийнято на засіданні Президії АН УРСР 14 вересня 1966 р. Г.С.
Писаренка Національної академії наук України) було ухвалено на засіданні
Президії АН УРСР 14 вересня 1966 р.

Директором Інституту був призначений ініціатор його створення акад. АН
УРСР Г.С. Писаренко.

Інститут створювався на базі сектора міцності Інституту проблем
матеріалознавства АН УРСР. Сектор міцності протягом багатьох років
очолював Г.С. Писаренко.

До моменту організації Інституту сектор міцності проводив інтенсивні
дослідження за новим перспективним напрямом, який Г.С. Писаренко
визначив як міцність матеріалів і елементів конструкцій в екстремальних
умовах.

Під екстремальними умовами в широкому сенсі слід розуміти умови
експлуатації деталей машин і конструкцій, коли рівень напружень, що
діють у них, близький до граничних, а ці граничні напруження залежать
від таких чинників, як високі й низькі температури, нестаціонарність
режимів нагрівання та навантажування, вплив корозійних середовищ і
газових потоків, радіаційне й водневе окрихтіння, наявність
технологічних та експлуатаційних дефектів, деградація матеріалу в
процесі тривалого статичного й циклічного навантажування тощо, що можуть
призвести до виникнення дефекту в процесі експлуатації.

Ці умови експлуатації були характерні для багатьох конструктивних
елементів нової техніки, що бурхливо розвивалася в другій половині XX
ст.

Усе це ініціювало створення таких матеріалів, як жароміцні сталі та
сплави, високоміцні титанові та алюмінієві сплави, композиційні, зокрема
теплозахисні, матеріали, керамічні та металокерамічні матеріали,
тугоплавкі метали та сплави, вуглеграфітові матеріали тощо.

Проектування конструкцій з використанням перерахованих матеріалів
неможливе без знання характеристик їхньої міцності й деформативності та
закономірностей поведінки в умовах експлуатації тих чи інших
конструкцій.

Важливим у цьому разі є не тільки визначення характеристик конкретних
властивостей матеріалів у тих чи інших умовах, а й розроблення критеріїв
граничного стану матеріалів, що дають змогу з використанням результатів,
отриманих під час випробування лабораторних зразків, розраховувати
міцність і довговічність реальних конструкцій з урахуванням їхньої
геометрії, напруженого стану, розмірів та інших чинників.

Розроблення критеріїв граничного стану матеріалів у цих умовах є
складним науковим завданням, пов\'язаним із необхідністю враховувати
різноманіття механізмів деформації та руйнування матеріалів, які
реалізуються під час експлуатації і призводять до різних умов граничного
стану (руйнування).

Як приклади таких механізмів можна назвати пластичне деформування,
повзучість, зокрема циклічну, мало- і багатоциклову втому, термічну
втому, корозійне розтріскування, зношування, фретинг-корозію, ерозію
тощо.

Враховують також різноманіття матеріалів, які використовують у техніці,
та істотну відмінність їхньої поведінки під час механічного, теплового
та термомеханічного навантажень, а також такі особливості реальних
матеріалів, як розсіювання властивостей, наявність технологічних та
експлуатаційних дефектів, нестабільність властивостей під час тривалої
експлуатації, особливо в умовах радіаційного й іншого крихкого
руйнування, особливий стан поверхневого шару матеріалів тощо.

У світлі завдань, згаданих вище, на початку 50-х років XX ст. у
самостійній Лабораторії спеціальних сплавів, яка була створена на базі
відділу фізико-хімії металургійних процесів Інституту чорної металургії
АН УРСР, під керівництвом чл.-кор. АН УРСР І.М. Францевича (пізніше
акад. АН УРСР) проводилися дослідження, спрямовані на розроблення
принципово нових для того часу керамічних матеріалів на основі карбіду
кремнію, здатних експлуатуватися за температур до 1400 К і вище.
Передбачалося використовувати ці матеріали для виготовлення соплових і
робочих лопаток турбін авіаційних двигунів. Підвищення робочих
температур у цих двигунах дало б змогу істотно збільшити швидкість і
дальність польотів літаків. Ці роботи проводилися у співдружності з
Куйбишевським моторним заводом, який очолював М.Д. Кузнєцов (пізніше
генеральний конструктор, акад. АН СРСР).

Для розвитку досліджень міцності в цій лабораторії в 1952 р. було
запрошено як завідувача відділу міцності докт. техн. наук, проф. Г.С.
Писаренка, який працював на той час старшим науковим співробітником
Інституту будівельної механіки АН УРСР. Г.С.Писаренку вдалося за
порівняно короткий термін, із залученням, передусім, випускників
Київського політехнічного інституту, в якому він тоді завідував кафедрою
\"Опір матеріалів\", створити колектив і розвинути дослідження міцності
й демпфуючих властивостей керамічних та інших матеріалів в умовах дуже
високих температур.

Так, у 1952 р. у відділі почали працювати випускники КПІ В.Г. Тимошенко
і Г.М. Третьяченко, у 1953 р. - В.М. Руденко, у 1955 р. - В.І. Ковпак, у
1956 р. - О.П. Яковлєв, у 1958 р. - Н.В. Новіков і Л.В. Кравчук, у 1959
р. - В.А. Борисенко, у 1960 р. - О.А. Лебедєв, у 1961 р. - Б.О. Лебедєв.
- М.В. Новіков і Л.В. Кравчук, у 1959 р. - В.А. Борисенко, у 1960 р. -
О.О.Лебедєв, у 1961 р. - Б.А. Ляшенко і А.Я. Красовський, у 1962 р. -
Г.В. Степанов та інші.

Г.С. Писаренко активно залучав для роботи за тематикою відділу
аспірантів КПІ. Так, у 1953 р. аспіранти КПІ В.Т. Трощенко і ГВ.
Ісаханов після закінчення аспірантури і захисту кандидатських дисертацій
продовжили роботу у відділі. У 1955 р. при відділі було організовано
аспірантуру. Першими аспірантами стали Б.А. Грязнов та І.А. Козлов.
Великий внесок робив у роботу відділу завідувач лабораторії стендових
випробувань канд. техн. наук В.Г. Попков.

У перші роки своєї роботи відділ розміщувався в Онуфрієвій вежі на
території напівзруйнованого господарського двору Києво-Печерської лаври.
У 1955 р. у розпорядження відділу передали майданчик і недобудовану
будівлю на вул. Тимірязєвській, 2 (раніше Омелютинецькій).

У наступні роки територія цього майданчика стала базою для будівництва
майбутнього Інституту проблем міцності АН України. На ній у 1966 р. було
збудовано два нові лабораторні корпуси, у 1977 р. - третій корпус,
пізніше - низку додаткових приміщень, зокрема кілька павільйонів, у яких
розмістилися Спеціальне конструкторсько-технологічне бюро з дослідним
виробництвом, деякі лабораторії та служби.

У зв\'язку з розширенням тематики досліджень Лабораторії спеціальних
сплавів, яку в 1955 р. було перетворено на Інститут металокераміки і
спеціальних сплавів АН УРСР (з 1964 р. Інститут проблем
матеріалознавства АН УРСР), а також у зв\'язку з потребами техніки та
збільшенням можливостей колективу, який очолював Г.С. Писаренко,
тематику досліджень у сфері міцності матеріалів за високих температур
також було істотно розширено.

Успішно розвивалися дослідження демпферних властивостей матеріалів з
урахуванням конструктивно-технологічних чинників, міцності жароміцних
сплавів, що використовуються в авіаційному газотурбобудуванні,
теплозахисних композиційних матеріалів для космічної техніки,
тугоплавких металів і сплавів, що використовуються в енергетиці тощо.

Фундаментальні результати були отримані Г.С. Писаренком з розвитку
теорії нелінійних коливань механічних систем. Він уперше з використанням
асимптотичного методу М.М. Крилова і М.М. Боголюбова розв\'язав задачу
розрахунку в нелінійній постановці коливань пружних систем із
врахуванням розсіювання енергії в матеріалі, що циклічно деформується.
Надалі розпочаті ним дослідження коливань дисипативних систем широко
розвивалися. Результати цих досліджень, що знайшли визнання як у нашій
країні, так і за кордоном, опубліковано Г.С. Писаренком і його учнями в
понад 10 монографіях, одна з яких була перекладена й видана у США в 1962
р. Роботи з нелінійних коливань було удостоєно премій АН УРСР у 1968 р.
- ім. Н.М. Крилова (Г.С. Писаренко та М.М. Крилов - ім. Н.М. Крилов,
1968 р. - ім. М.М. Крилов). М.М. Крилова (Г.С. Писаренко) і в 1985 р. -
ім. А.М. Динника (Г.С. Писаренко). О.М. Динника (Ш.У. Галієв, В.В.
Матвєєв).

ГС. Писаренко і Г.М. Третьяченко зі співробітниками розробили теоретичні
основи експериментального дослідження термічної стійкості елементів
конструкцій, теорію моделювання процесів несталого напруженого стану
конструктивних елементів машин, зумовленого несталими температурними
полями.

Г.С. Писаренко і В.Т. Трощенко зі співробітниками обґрунтували
можливість використання статистичних теорій міцності для опису
закономірностей руйнування кераміки, запропонували статистичну теорію
міцності пористих матеріалів, обгрунтували феноменологічну теорію
втомного руйнування металів, отримали низку інших важливих результатів.

Дослідження з високотемпературної міцності матеріалів та елементів
конструкцій були узагальнені в монографії Г.С. Писаренка, В.М. Руденка,
Г.М. Третьяченка, В.Т. Трощенка \"Міцність матеріалів за високих
температур\", виданій 1966 р., яку було перекладено на англійську мову і
видано за кордоном. Цикл досліджень, узагальнених у цій монографії, у
1969 р. був удостоєний Державної премії УРСР у галузі науки і техніки.
Результати цих досліджень впроваджено в провідних галузях промисловості
й одержали високу оцінку фахівців.

У відділі завжди приділялася велика увага створенню нових
експериментальних засобів дослідження міцності матеріалів в
екстремальних умовах. Особливо велика увага приділялася створенню
установок для дослідження міцності матеріалів за різних видів
навантаження, зокрема в газових потоках за високих температур, аж до
3000 К.

Наукова діяльність відділу систематично висвітлювалася в періодичній
пресі, представлялася на всесоюзних і республіканських конференціях.
Починаючи з 1956 р., відділ (потім сектор, Інститут) регулярно проводить
науково-технічні наради та конференції з питань розсіювання енергії під
час коливань механічних систем, з високотемпературної міцності, з
термоміцності матеріалів і елементів конструкцій, міцності за низьких
температур, міцності за складного напруженого стану, втомлюваності
металів, інших аспектів міцності.

Дослідження, проведені під керівництвом Г.С. Писаренка в рамках сектору
міцності, підтримувалися такими відомими вченими, як Б.Є. Патон, І.М.
Францевич, СВ. Серенсен, Ю.А. Митропольський, Г.М. Савін, А.Д. Коваленко
та інші.

Велику підтримку надавали колективу вчених керівники провідних
організацій, очолюваних М.Д. Кузнєцовим, A.M. Люлькою, O.K. Антоновим,
М.К. Янгелем, А.Г. Івченком, Л.А. Шубенком-Шубіним та іншими, які
розробляли нову техніку. Антоновим, М.К. Янгелем, О.Г. Івченком, Л.О.
Шубенком-Шубіним та іншими, які розробляли нову техніку і були
безпосередніми споживачами результатів досліджень, що проводив відділ.

У 1964 р. відділ міцності було перетворено на сектор. Дослідження,
проведені в секторі міцності в 60-ті роки, вийшли далеко за рамки
тематики Інституту проблем матеріалознавства АН УРСР.

Широта охоплення наукових проблем, рівень досліджень міцності матеріалів
і конструктивних елементів сприяли порушенню питання про створення на
базі сектора самостійного інституту. Високий рівень досліджень учених
сектора був відзначений президентом АН СРСР академіком М.В. Келдишем,
який відвідав навесні 1964 р. лабораторії сектора. Усе це дало підставу
акад. АН УРСР Г.С. Писаренка порушити питання про створення Інституту
проблем міцності АН УРСР. Його ініціативу підтримав президент АН УРСР
академік Б.Є.Патон, який неодноразово відвідував сектор міцності та
знайомився з дослідженнями, що проводилися в ньому. Велику роль у
створенні Інституту мала підтримка президента АН СРСР академіка М.В.
Келдиша. Слід відзначити і підтримку в організації нового Інституту з
боку дирекції Інституту проблем матеріалознавства АН УРСР, очолюваного
тоді акад. АН УРСР І.М. Францевичем.

Завдяки наполегливості Г.С. Писаренка було подолано всі складнощі, і
Інститут проблем міцності АН УРСР було організовано. Відповідно до
постанови Президії Академії наук УРСР від 14 вересня 1966 р. сектор
міцності було виведено зі складу Інституту проблем матеріалознавства АН
УРСР і на його базі створено Інститут проблем міцності АН УРСР.

На момент створення Інституту в секторі міцності працювало 185 осіб, з
них один акад. АН УРСР (Г.С.Писаренко), два доктори технічних наук (Г.М.
Третьяченко, В.Т. Трощенко), 24 кандидати технічних наук, в аспірантурі
навчалося 19 осіб.

Очолив Інститут акад. АН УРСР Г.С. Писаренко, заступником директора
Інституту з наукової роботи було затверджено докт. техн. наук В.Т.
Трощенка, вченим секретарем Інституту - канд. техн. наук Р.І. Куріат.

Спочатку Інститут був у складі Відділення математики, механіки та
кібернетики, з 1983 р. він входить до складу Відділення механіки НАН
України.

Перед Інститутом проблем міцності АН УРСР було поставлено завдання
проведення теоретичних та експериментальних досліджень, спрямованих на
встановлення критеріїв міцності та несучої здатності матеріалів і
елементів конструкцій, а також на дослідження їхньої міцності стосовно
новітніх галузей техніки з урахуванням конструктивно-технологічних
чинників, виду напруженого стану та реальних режимів силового і
теплового навантаження в широкому діапазоні температур.

У момент створення Інституту в ньому функціонували такі наукові відділи:

міцності за високих температур (зав. відділом канд. техн. наук В.М.
Руденко);

міцності за низьких температур (зав. відділом канд. техн. наук М.В.
Новиков);

повзучості та тривалої міцності (з 4.01.1968 р. - зав. відділом канд.
техн. наук В.І. Ковпак);

фізичних основ міцності (з 16.10.1968 р. - зав. відділом канд. техн.
наук А.Я. Красовський);

несучої здатності конструкцій (зав. відділом канд. техн. наук І.А.
Козлов);

міцності матеріалів і конструкцій при імпульсних і вібраційних
навантаженнях (зав. відділом докт. техн. наук Г.С. Писаренко);

міцності конструкцій у теплових полях і газових потоках (зав. відділом
докт. техн. наук Г.М. Третьяченко);

міцності неметалевих і металокерамічних матеріалів (зав. відд.\
відділом канд. техн. наук Г.В. Ісаханов); \"

втоми і термовтоми матеріалів (зав. відділом докт. техн. наук В.Т.
Трощенко);

звукових і ультразвукових методів дослідження міцності (зав. відділом
канд. техн. наук В.А. Кузьменко).

Надалі структура наукових відділів безперервно вдосконалювалася.
Тематика наукової діяльності Інституту визначалася насамперед
необхідністю розв\'язання актуальних проблем міцності, висунутих
розвитком новітніх галузей техніки. Основні проблеми міцності виникали
там, де мали місце екстремальні умови експлуатації елементів
конструкцій. Це - дуже високі (до 4000 К) і дуже низькі (близько 4 К)
температури, високі частоти прикладання повторно-змінних навантажень (20
Гц - 40 кГц), різкі зміни температур, високі (до 2000 атм) і низькі (до
10\~8 мм рт.ст.) тиски, високі швидкості прикладання навантажень
(1000-1500 м/с), інтенсивне нейтронне опромінення матеріалів, несталі
силові та теплові впливи на елементи конструкцій, можливість виникнення
резонансних режимів їхніх коливань та втрати динамічної стійкості і т.п.

У зв\'язку з тим, що вплив на міцність, довговічність і граничний стан
тих чи інших елементів конструкцій різного роду екстремальних умов можна
врахувати тільки на базі добре поставлених експериментів в умовах,
максимально наближених до експлуатаційних, суттєва роль в Інституті, як
і раніше в секторі міцності, відводилася експериментальним дослідженням.
Ці дослідження виконувалися на оригінальному спеціальному лабораторному
обладнанні, створеному самими дослідниками безпосередньо в Інституті,
забезпечуючи належний рівень фундаментальних досліджень у галузі
міцності.

Було створено унікальний комплекс обладнання, що дає змогу досліджувати
міцність матеріалів практично в будь-яких, за деяким винятком, умовах,
які мали тоді місце в техніці.

Проєктно-конструкторські роботи, виготовлення, монтаж і налагодження
розроблених в Інституті установок і стендів, апаратури, різних
пристосувань і пристроїв, зразків для проведення експериментальних
досліджень виконує Спеціальне конструкторсько-технологічне бюро з
дослідним виробництвом (СКТБ), створене в 1972 р. на базі
експериментально-виробничих майстерень Інституту. З 1997 р. його очолює
канд. техн. наук В.І. Бойко.

Багато установок широко застосовуються в різних організаціях країни і за
кордоном, вони відзначені дипломами та медалями різних виставок. Так,
установку для дослідження механічних властивостей матеріалів в умовах
радіаційного опромінення \"Нейтрон-10\" 1979 р. і установку для вивчення
демпфувальної здатності конструкційних матеріалів під час коливань Д-6М
- 1987 р. удостоєно золотих медалей Лейпцизького міжнародного ярмарку.

При створенні випробувального обладнання, яким оснащувалися лабораторії
Інституту, їхні розробники продемонстрували багато винахідливості та
винахідливості, що багаторазово відзначали вітчизняні та зарубіжні
науковці, які ознайомлювалися з лабораторіями під час відвідин
Інституту.

## **СТАНОВЛЕННЯ ІНСТИТУТУ, ВДОСКОНАЛЕННЯ ЙОГО ТЕМАТИКИ**

У 1969 р. академік М.В. Келдиш і велика група відомих учених Академії
наук СРСР (академіки А.Ю. Ішлінський, О.П. Виноградов, Л.І. Сєдов, М.Д.
Кузнєцов та інші) відвідали Інститут, детально ознайомилися з
лабораторіями та отриманими вченими Інституту результатами досліджень,
дали високу оцінку діяльності наукового колективу.

Розвиваючи різні аспекти міцності, Інститут істотно розширювався, його
колектив постійно зростав, і до 1988 р. кількість його співробітників
сягнула разом із СКТБ 1100, зокрема 29 докторів (з них три академіки АН
УРСР) і понад 160 кандидатів наук.

Успішному розвитку Інституту сприяло створення в ньому 1966 р.
Спеціалізованої вченої ради із захисту докторських і кандидатських
дисертацій зі спеціальностей \"Динаміка, міцність машин, приладів та
апаратури\" і \"Механіка деформівного твердого тіла\", яка працює
донині.

Співробітники Інституту за час його функціонування підготували і
захистили 65 докторських і 325 кандидатських дисертацій.

Починаючи з 1969 р., Інститут видає міжнародний науково-технічний журнал
\"Проблем£1 міцності\", який з першого номера перевидається англійською
мовою в США під назвою \"Strength of Materials\".

Інститут є базовою організацією Наукової ради при Відділенні механіки
НАН України з проблеми \"Механіка деформівного твердого тіла\", яку з
1976 по 2001 р. очолював Г.С. Писаренко. Нині цю Наукову раду очолює
акад. НАН України О.О. Лебедєв.

Коротко розглянемо основні напрями досліджень, що розвивалися в
Інституті. Більшість цих досліджень були ініційовані директором
Інституту Г.С. Писаренком і проводилися за безпосередньої його участі.

Традиційним у діяльності Інституту було розроблення методів зниження
динамічної напруженості конструкцій завдяки раціональному використанню
демпферних властивостей матеріалів, конструкційного й аеродинамічного
демпфування коливань. Ці дослідження набули розвитку в створених на базі
відділу міцності матеріалів за імпульсних і вібраційних навантажень у
1975 р. відділі вібраційної надійності (очолив докт. фіз.-мат. наук В.В.
Матвєєв), і в 1980 р. відділі аерогідродинаміки коливних систем (докт.
техн. наук О.А. Камінер).

За цим напрямом було створено комплекс експериментальних засобів для
дослідження демпфуючих властивостей матеріалів за різних температур і
видів напруженого стану, демпфування коливань робочих лопаток
газотурбінних двигунів у полі відцентрових сил, демпфування коливань
лопаткових профілів турбомашин і трубок теплообмінних апаратів у
обтічних потоках (В. В. Матвєєв, Н.В. Новіков, А.П. Яковлєв, А.А.
Камінер, І.Г. Токарь, І.Г. Токар, та ін.).В. Матвєєв, М.В. Новіков, А.П.
Яковлєв, А.А. Камінер, І.Г. Токар та ін.).

Були отримані великі результати з дослідження демпфуючих властивостей
найрізноманітніших матеріалів в умовах кімнатної, високих і низьких
температур (В.В. Матвєєв, А.П. Яковлєв, Б.С. Чайковський та ін.).

Дані експериментальних досліджень понад 100 типів конструкційних
матеріалів були вперше узагальнені у виданому 1971 р. довіднику Г.С.
Писаренка, А.П. Яковлєва, В.В. Матвєєва. Матвєєва, який у 1976 р. з
доповненнями був перекладений і виданий у Польщі.

Уперше було розроблено методи визначення характеристик демпфірування
коливань нелінійних систем гістерезисного типу. Важливі оригінальні
результати було отримано з оцінювання демпфувальної здатності,
вібронапруженості та динамічної стійкості до флаттера лопаткового
апарата сучасних газотурбінних двигунів, із розроблення методів
дослідження та вивчення коливань регулярних пружних систем з порушеною
симетрією та коливань пружних тіл за наявності втомних ушкоджень (В.В.
Матвєєв, О.П. Зіньковський, О.П. Бовсуновський, О.Л. Стельмах, В.А.
Цимбалнж та ін.).

Прагнення забезпечити працездатність елементів реактивних і
газотурбінних двигунів, елементів ядерної техніки тощо в умовах високих
температур (3000 К і вище) зумовило необхідність використання
тугоплавких металів (вольфрам, молібден, ніобій тощо) та їхніх сплавів.
У зв\'язку з цим завданням у відділі міцності за високих температур було
розроблено комплекс установок, що дає змогу досліджувати ці матеріали у
вакуумі та інертних середовищах і визначати характеристики пружності,
твердості, міцності та деформативності, опору повзучості та втоми за
температур до 3000 К (В.А. Борисенко, В.В. Кривенюк, В.К. Харченко та
ін.).

Використання в техніці тугоплавких металів і сплавів зумовило
необхідність вишукування шляхів їхнього захисту від окислення в
атмосфері та агресивних середовищах за допомогою покриттів різного типу.
У відділі міцності неметалевих і металокерамічних матеріалів було
створено комплекс установок, що дають змогу досліджувати на зразках із
покриттями адгезійну здатність.

ную і когезійну міцність, термостабільність зони адгезійного контакту,
ізотермічну і термоциклічну тривалу міцність і повзучість, витривалість
до температури 2300 К у різних сумішах агресивних газів за швидкості
нагріву та охолодження до 500 град/с (Г. В. Ісаханов, Б. А. Ляшенко та
ін.).

В Інституті тривали подальші дослідження міцності конструкційної
кераміки, яка призначена для експлуатації в умовах високих температур і
є одним із перспективних матеріалів при створенні цілої низки
конструкцій. При цьому коло досліджуваних матеріалів було істотно
розширено. Основну увагу при цьому приділяли, у зв\'язку з крихкістю цих
матеріалів, їхній здатності чинити опір руйнуванню в умовах різких
теплозмін, для чого створили відповідне обладнання (Г.М. Третьяченко,
Г.А. Гогоці та ін.).

У відділі несучої здатності конструкцій було створено комплекс
обладнання для дослідження міцності дисків авіаційних газових турбін та
інших деталей у полі відцентрових сил в умовах високих і низьких
температур. З використанням створених розгінних стендів було досліджено
несучу здатність дисків, зокрема біметалевих, крильчаток та інших
деталей, що експлуатуються за великих швидкостей обертання, з
урахуванням впливу температур і конструктивних чинників (І.А. Козлов,
В.Г. Баженов, В.М. Городецький, В.М. Лещенко та ін.).

Експлуатація багатьох деталей сучасної техніки, насамперед обладнання
теплової та атомної енергетики, газотурбінних установок тощо, в умовах
високих температур і навантажень протягом тривалого (100 000 год і
більше) часу зумовила необхідність досліджень тривалої міцності та
повзучості матеріалів за максимально практично здійсненних часах
витримки під навантаженням і створення методів прогнозування
характеристик їхньої міцності за ще більших часах експлуатації, які є в
практиці.

При проведенні цих досліджень значна увага у відділі повзучості та
тривалої міцності приділялася створенню устаткування для вивчення
тривалої міцності тугоплавких металів і сплавів у вакуумі, устаткування
для дослідження тривалої міцності та повзучості жароміцних сплавів за
програмних режимів навантаження (В.І. Ковпак, М.С. Можаров-ський, В.В.
Кривенюк, В.П. Дубінін, В.В. Осасюк та ін.).

Розвиток ракетобудування поряд з іншими завданнями поставив завдання
забезпечити міцність конструкцій, насамперед зварених тонкостінних
посудин тиску, за кріогенних (до 4,2 К) температур, для яких найбільшу
небезпеку становило руйнування внаслідок мало- і багатоциклової втоми.

Пізніше виникла проблема створення енергетичних установок з
надпровідними магнітними системами, коли на матеріали, які
експлуатуються в цих установках за кріогенних температур, впливають
також магнітні поля та електричні струми великої щільності.

У відділі міцності за низьких температур, який з 1977 р. очолив докт.
техн. наук В.А. Стрижало, створено комплекс устаткування (М.В. Новиков,
В.А. Стрижало, Е.В. Чечин, М.І. Городиський, Л.С. Новогрудський тощо),
що дає змогу досліджувати матеріали та конструктивні елементи, які
експлуатуються за криогенних температур в умовах статичного, мало- і
багатоциклового навантаження під впливом магнітних полів і електричного
струму.

В.О. Стрижало розробив критерій, що визначає довговічність сплавів за
кріогенних температур в умовах циклічного повзучості, і створив методи
прогнозування довговічності листових елементів конструкцій з
концентраторами напружень при стаціонарному малоцикловому навантаженні з
урахуванням циклічного повзучості в умовах неоднорідного напруженого
стану. За цикл робіт із циклічного повзучості в 1988 р. В.О. Стрижало
був удостоєний премії ім. О.М. Динника АН. О.М. Динника АН УРСР.

Було розроблено методологію оцінювання граничного стану конструкційних
сплавів під час електромагнітних впливів високої інтенсивності в умовах
лінійного однорідного, неоднорідного і складного напруженого станів за
криогенних температур, запропоновано інженерні методи визначення
допустимих напружень, що базуються на реалізації концепції врахування
низькотемпературного зміцнення матеріалів під час електромагнітного
впливу (В.А. Стрижало, Л.С. Новогрудський, Є.В. Воробйов та ін.).

У 1973 р. М.В. Новіков, А.Г. Войницький, А.Ф. Бєлоіван були удостоєні
Державної премії УРСР у галузі науки і техніки за розробку нових
матеріалів, які використовуються в ракетно-космічній техніці.

За цикл робіт, виконаних у відділі з визначальних рівнянь і критеріїв
граничного стану матеріалів за циклічних термомеханічних навантажень,
Державної премії УРСР у галузі науки і техніки в 1990 р. удостоєно В.А.
Стрижала і В.І. Скрипченка.

Одним з основних напрямів діяльності Інституту було розроблення фізично
й експериментально обґрунтованих моделей деформування та руйнування
конструкційних матеріалів у зв\'язку з впливом виду напруженого стану,
температури, режиму навантаження й удосконалення на їхній основі норм
розрахунку на міцність несучих елементів конструкцій, що працюють у
складних умовах силових і температурних впливів.

Для цього напряму характерне створення нових методів і засобів
механічних випробувань матеріалів та елементів конструкцій за складного
напруженого стану в широкому діапазоні низьких і високих температур і
розробка критеріїв граничного стану матеріалів в умовах складного
напруженого стану (О.А. Лебедєв, В.П. Ламашевський, Б.І. Ковальчук, Ф.Ф.
Гігіняк та ін.).

У 1969 р. Г.С. Писаренко і А.А. Лебедєв у монографії \"Опір матеріалів
деформації і руйнуванню при складному напруженому стані\" узагальнили
теоретичні та експериментальні дослідження поведінки реальних
конструкційних матеріалів в умовах складного напруженого стану з
урахуванням впливу на граничний стан матеріалу.

температури, режиму навантаження, часу, анізотропії матеріалу та інших
факторів. Ці дослідження істотно розширено у створеному 1971 р. відділі
статичної міцності та пластичності конструкційних матеріалів, який
очолив докт. техн. наук О.О. Лебедєв.

Встановлені закономірності дали можливість внести необхідні корективи в
математичні моделі деформування і руйнування конструкційних матеріалів
різних класів (ізотропних, анізотропних, структурно-неоднорідних і
структурно-нестабільних) за низьких і високих температур, надати
обґрунтовані рекомендації щодо критеріїв їхньої міцності, уточнити
окремі технологічні операції, пов\'язані з обробкою тиском і
механотермічним зміцненням матеріалів. Більшу частину цих
експериментальних даних використано в монографіях, виданих у 1969, 1976,
1987 і 2001 рр.

Для всебічного вивчення питань міцності матеріалів і елементів
конструкцій, що працюють в екстремальних умовах, вже при створенні
Інституту було передбачено розвиток фізичних аспектів міцності. А.Я.
Красовським було запропоновано фізично обґрунтовані модель і критерій
квазікрихкого руйнування металів, що включають два локальні параметри:
критичне напруження відколу і характеристичну відстань. На основі моделі
запропоновано кількісний опис критичної температури крихкості, як міри
тріщиностійкості металів, розвинуто узагальнений глобальний критерій
руйнування, розроблено методи прогнозування впливу на тріщиностійкість,
в\'язко-крихкий перехід та критичну температуру крихкості сталей та
сплавів таких визначальних чинників, як розміри деталей, швидкість
навантаження, нейтронне опромінення та інші.

Методом кількісної стереоскопічної фрактографії вивчено механізм
зростання тріщини втоми і на цій основі запропоновано нову модель цього
процесу, що включає два принципово важливих етапи приросту тріщини за
цикл навантаження: поділ матеріалу в пластичній зоні на частини за
траєкторією його максимального ушкодження і подальше пластичне
затуплення вершини тріщини.

Розроблено комплексний метод прогнозування залишкового ресурсу
відповідальних великогабаритних елементів енергетичного обладнання,
трубопровідного транспорту за критеріями механіки руйнування з
урахуванням експлуатаційної ушкодженості структури матеріалів.

У наступні роки розроблено кілька версій комп\'ютерних експертних систем
для діагностики, моніторингу та супроводу безаварійної експлуатації
складних інженерних споруд: трубопровідні системи атомних і теплових
електростанцій, магістральні трубопроводи, резервуари та посудини тиску,
металоконструкції (А.Я. Красовський, І.В. Ориняк, В.М. Тороп та інші).

З урахуванням рівня необхідних температур випробування, властивостей
досліджуваного матеріалу, умов експлуатації матеріалів у реальних
конструкціях тощо в роки становлення Інституту було створено обладнання,
що давало змогу

що дозволяє здійснювати дослідження з використанням таких методів
нагріву, як радіаційний, променевий, пряме пропускання електричного
струму через зразок, індукційний, плазмовий, нагрівання у
високотемпературних газових потоках тощо. (В. Г. Тимошенко, ПН.
Третьяченко, В.М. Руденко, Г.В. Іса-ханов, С.С. Городецький, Ю.М.
Шемеган, Б.А. Ляшенко, Е.А. Ескін, B.C. Дзюба та ін.). Ці методи давали
змогу забезпечити нагрівання досліджуваних матеріалів до 3000 К і вище.

У багатьох випадках вимоги випробувань за високих температур
супроводжуються також вимогами забезпечення складних режимів
навантажування, проведення випробувань у корозійних середовищах, у
продуктах згоряння палива, під час впливу газових потоків заданої
швидкості та хімічного складу, реалізації великих швидкостей нагріву й
охолодження, можливості випробування не тільки зразків матеріалів, а й
конструктивних елементів із цих матеріалів.

Для визначення граничних станів і встановлення критеріїв несучої
здатності елементів конструкцій енергетичного стаціонарного і
транспортного машинобудування, авіаційної та ракетно-космічної техніки,
які працюють в екстремальних умовах, у відділі міцності конструкцій у
теплових полях і газових потоках, який з 1984 р. очолив докт. техн. наук
Л.В.Кравчук, було створено кілька модифікацій газодинамічних стендів.

Найважливішим у цьому напрямі є дослідження процесів пошкодження
конструкцій за термічного удару та термічної втоми. Термічні напруження
ініціювали програмованою циклічною дією високотемпературного газового
потоку зі змінними в часі та просторі термодинамічними та хімічними
параметрами.

На стендах досліджували зразки і натурні соплові та робочі лопатки
газотурбінних двигунів в умовах термоциклювання за температур до 2000 К
з добавками в газовий потік сірки та солей морської води, а також
теплозахисні матеріали при моделюванні теплових потоків, які
відбуваються під час входження космічних літальних апаратів у щільні
шари атмосфери, з накладенням статичних і вібраційних навантажень за
температур до 2700 К (що досягалося збагаченням потоку газоподібним
киснем).

Дослідження з використанням газодинамічних стендів, в умовах, що
максимально наближаються до реальних, дали змогу дати порівняльну оцінку
працездатності матеріалів, які застосовують для теплового захисту
космічних літальних апаратів, та обгрунтувати їхню працездатність (Г.М.
Третьяченко, Л.В. Кравчук, Р.І. Куріат та ін.).

Акад. АН УРСР ГС. Писаренко, будучи членом Бюро (з 1969 р.), а потім
головою (з 1969 р. до 1984 р.) Комісії космічних досліджень при Президії
АН УРСР, що функціонувала на базі Інституту проблем міцності, здійснював
координацію науково-дослідних робіт наукових установ Академії наук УРСР,
галузевих науково-дослідних установ Академії, а також галузевих
науково-дослідних інститутів АН УРСР.

ганізацій і вишів республіки в галузі вивчення та використання
космічного простору, сприяв розвитку фундаментальних досліджень і нових
прогресивних форм проведення спільних робіт у цій царині, брав активну
участь в організації та роботі наукових форумів різного рівня,
пов\'язаних із космічними дослідженнями.

Міжнародна громадськість високо оцінила діяльність Г.С. Писаренка,
обравши його 1974 р. членом-кореспондентом, а 1977 р. - дійсним членом
Міжнародної академії астронавтики і членом Американського товариства
випробувань і матеріалів.

У наступні роки у відділі було розроблено методи моделювання
термонапруженого стану в деталях, що експлуатуються в умовах різких
теплозмін, з використанням циліндричних, плоских і клиноподібних
зразків, обґрунтовано застосовність термодинамічних підходів до
оцінювання міцності матеріалів (Г.М. Третьяченко). Проведено дослідження
довговічності зразків і реальних деталей (робочі та соплові лопатки
газотурбінних двигунів тощо) з жароміцних сплавів з урахуванням таких
факторів, як тепловий режим, статичне навантаження, що імітує дію
відцентрових сил, високочастотні циклічні навантаження, хімічний склад
газового потоку та сформульовано критерії їх граничного стану.
Розроблено методи прогнозування довговічності лопаток газових турбін за
нестаціонарних режимів навантаження (Г.М. Третьяченко, Л.В. Кравчук,
Р.І. Куріат, А.П. Волощенко, Г.Р. Семенов, Б.С. Карпінос та ін.).

Одним із найбільш поширених у практиці та найбільш небезпечних є
руйнування внаслідок втоми матеріалів, коли в умовах циклічного
навантаження в матеріалі зароджуються втомні тріщини, розвиток яких
призводить до руйнування конструкції. У відділі втоми і термовтоми
матеріалів створено комплекс випробувальних засобів, що дають змогу
досліджувати втому матеріалів за мало- і багатоциклового навантаження, в
умовах високих і низьких температур. Тут створено установки для
дослідження матеріалів і реальних деталей газотурбінних двигунів при
термомеханічному навантаженні, що імітують реальні умови експлуатації;
розроблено установки і методики дослідження статичної та циклічної
тріщиностійкості конструкційних матеріалів (В.Т. Трощенко, Б.А. Грязне,
В.А. Стрижало, Л.А. Хамаза, А.П. Гопкало та ін.).

Досліджено закономірності непружного циклічного деформування і втомного
руйнування монокристалів молібдену і нікелю, сталей, сплавів алюмінію,
магнію, титану, міді, нікелю в широкому діапазоні температур і
обґрунтовано можливість прискореного прогнозування меж втоми металів в
умовах однорідного і неоднорідного напружених станів з використанням
діаграм циклічного деформування.

Обґрунтовано вплив на характеристики опору втомному руйнуванню градієнта
напруги та складного напруженого стану.

Розроблено методи прогнозування довговічності матеріалів і
конструктивних елементів в умовах стаціонарного і програмного
навантаження.

ня з використанням як міри інтенсивності накопичення втомного
пошкодження циклічної непружної деформації за цикл на стадії
стабілізації процесу непружного деформування.

Досліджено витривалість жароміцних сталей і сплавів з урахуванням впливу
високих температур, асиметрії циклу, концентрації напружень, стану
поверхні, тривалості напрацювання та інших чинників і сформульовано
критерії їх граничного стану. Розроблено методи прогнозування
довговічності жароміцних сплавів в умовах комплексного термомеханічного
навантаження та обґрунтовано підходи до оцінки міцності деталей
газотурбінних двигунів, які експлуатуються в подібних умовах.

Значного розвитку у відділі в наступні роки набули роботи з дослідження
тріщиностійкості металів при циклічному навантаженні. Було обґрунтовано
умови переходу від втомного до крихкого руйнування і створено модель, що
дає змогу прогнозувати умови цього переходу з урахуванням
стрибкоподібного розвитку тріщин, властивостей матеріалу й умов
навантаження. Розроблено та обґрунтовано критерії зародження і розвитку
втомних тріщин у металах під час циклічного навантаження, що враховують
структуру матеріалу, геометрію конструкцій і умови експлуатації. Ці
роботи, узагальнені в монографії В.Т.Трощенка, Л.А. Хамази, В.В.
Покровського (спільно з чехословацькими вченими) \"Циклічні деформації і
втома металів\", виданої російською та чеською мовами, були удостоєні в
1987 р. премії АН СРСР і АН ЧССР.

Показано можливість застосування циклічних непружних деформацій як
критерію зародження тріщини при багатоцикловій втомі та обґрунтовано
методи врахування впливу на довговічність, з використанням цього
критерію, градієнта напружень, виду напруженого стану, програмності та
двочастотності навантаження, розмірів зразків та інших чинників (В.Т.
Трощенко, Л.А. Хамаза, Г.В. Цибаньов та ін.).

Було детально досліджено закономірності розвитку втомних тріщин та
обґрунтовано критерії граничного стану матеріалів в умовах циклічного
навантажування з урахуванням впливу високих і низьких температур,
попереднього пластичного деформування, фреттінг-корозії, стану
поверхневого шару та інших чинників; обґрунтовано критерії граничного
стану матеріалів з тріщинами з урахуванням розглянутих вище чинників
(В.Т. Трощенко, А.Я. Красовський, В.В. Покровський, П.В. Ясний, А.В.
Прокопенко та ін.).

Проводилися випробування витривалості жароміцних сплавів і деталей
газових турбін в умовах високих температур (Б.А. Грязнов та ін.),
циклічного повзучості й утоми конструкційних сталей під час
малоциклового навантаження в умовах складного напруженого стану (О.А.
Лебедєв, Ф.Ф. Гігіняк та ін.), зварних з\'єднань конструкційних сталей
під час ударного навантаження в умовах низьких температур (В.В. Матвєєв,
Б.С. Шульги-нов та ін.).), зварних з\'єднань конструкційних сталей за
ударного навантаження в умовах низьких температур (В.В. Матвєєв, Б.С.
Шульгінов та інші), керамічних матеріалів електроакустичних
перетворювачів енергії та металів і сплавів різного призначення за
частот до 20 000 Гц (В.А. Кузьменко, М.Г. Писаренко, Л.Є. Матохнюк та
ін.).

Більшість із розглянутих вище досліджень, поряд із вивченням
фундаментальних закономірностей деформування і руйнування матеріалів в
екстремальних умовах, проводили для забезпечення міцності та
довговічності реальних конструкцій, що експлуатуються в цих умовах.

У 1976-1980 рр. Інститут виконував функції головної організації з
реалізації загальносоюзної програми \"Розроблення наукових засад і
методів підвищення надійності та довговічності авіаційних газотурбінних
двигунів шляхом оптимізації характеристик лопаткового апарату турбіни і
компресора\". Керівництво програмою здійснював акад. АН УРСР В.Т.
Трощенко.

Згідно з постановою Ради Міністрів УРСР № 146 від 29.02.1980 р.,
Інститут виконував функції головної установи з науково-технічної
проблеми \"Підвищення надійності та довговічності машин і споруд\";
акад. АН УРСР В.Т. Трощенко очолював Міжвідомчу республіканську
науково-технічну раду з підвищення надійності та довговічності машин і
споруд.

Ще в 60-ті роки у відділі міцності матеріалів і конструкцій за
імпульсних і вібраційних навантажень (керівник Г.С. Писаренко) було
розпочато дослідження з оцінювання міцності та пластичності матеріалів
за високошвидкісного (імпульсного) навантаження з використанням
розроблених оригінальних експериментальних засобів.

Було створено обладнання для дослідження механічної поведінки матеріалів
при імпульсному навантаженні, зокрема пневмопорохові копри, що дають
змогу досліджувати поведінку матеріалів за швидкостей ударної взаємодії
до 1000 м/с, за швидкостей деформації до 106 1/с, за тиску ударного
стиснення до 20 ГПа в діапазоні температур від 77 до 1000 К (Г.В.
Степанов, В.В. Астанін, А.П. Ващенко, В.В. Харченко та ін.). У наступні
роки цей науковий напрямок набув подальшого розвитку в створеному в 1981
р. відділі міцності та руйнування за ударного та імпульсного
навантаження, очоленому докт. техн. наук Г.В. Степановим.

Були встановлені рівняння стану матеріалу під час дії імпульсних
навантажень, що викликають хвильові процеси в матеріалі. Розроблено
моделі та складено визначальні рівняння непружного деформування
конструкційних матеріалів з урахуванням напруженого стану,
температурно-тимчасових умов, історії та шляхів імпульсного
навантаження; досліджено ударну взаємодію тіл з високою швидкістю,
створено моделі та методи розрахунку взаємодії; розроблено розрахункові
методи визначення полів напружень, деформацій та ушкоджень (руйнувань)
елементів конструкцій за умови імпульсного силового навантаження і за
нестаціонарного термосилового навантаження; вивчено вплив імпульсного
силового навантаження на матеріал; вивчено вплив імпульсного
навантаження.

Розвиток атомної енергетики, зокрема створення надійних тепловидільних
елементів, зажадав дослідження властивостей матеріалів оболонок.

чек цих елементів з урахуванням усього різноманіття чинників, що
впливають на них у процесі експлуатації.

Розпочаті в 60-ті роки роботи з дослідження короткочасної і тривалої
міцності матеріалів в умовах реакторного опромінення набули в наступні
роки подальшого розвитку в створеному в 1973 р. відділі міцності
матеріалів за радіаційного ушкодження, який очолив докт. техн. наук В.М.
Киселевський.

Було створено оригінальне експериментальне обладнання, що дає змогу
поміщати досліджуваний зразок безпосередньо в канал атомного реактора і
визначати його міцність, зокрема під час тривалого статичного і
циклічного навантаження, з урахуванням радіаційного та корозійного
впливів, високої температури, інших чинників радіаційного впливу (В.Н.
Киселевський, Д.В. Польовий, В.К. Лукашев, Ю.Д. Скрип-ник та ін.).

Широко використовуючи під час проведення експериментальних досліджень
комплекс створеного випробувального обладнання (установки серій
\"Нейтрон\"), вдалося розробити критерії міцності матеріалів, що
експлуатуються в умовах радіаційного опромінення. У 1979 р. результати
цих досліджень було узагальнено Г.С. Писаренком і В.М. Киселевським у
монографії \"Міцність і пластичність матеріалів у радіаційних потоках\".

На основі узагальнених дослідних даних і концепції про єдність процесів
деформування та накопичення ушкодження було побудовано феноменологічну
теорію повзучості, тривалої міцності та малоциклової втоми
конструкційних матеріалів у разі радіаційного ушкодження і тривалого
навантаження.

В.М. Киселевський, В.К. Лукашев, Д.В. Польовий, Ю.Д. Скрипник за цикл
цих робіт у 1974 р. були удостоєні Державної премії УРСР у галузі науки
і техніки.

Починаючи з 1974-1975 рр. велику увагу приділяли дослідженням динамічної
міцності гідропружно-пластичних систем. Ш.У. Галієвим було запропоновано
загальну математичну постановку проблеми нелінійної взаємодії твердих
деформівних і рідких середовищ. При цьому введено в розгляд, теоретично
описано і проаналізовано всі основні нелінійні чинники, що впливають на
динамічну міцність конструкцій, які межують із рідиною: неодномірна
кавітація, геометрична і фізична нелінійність середовищ, які стикаються,
нелінійність умов на поверхні їхнього контакту. Роботи виконували у
створеному 1981 р. відділі міцності конструкцій під час силового і
термопроменевого впливу, який очолював докт. техн. наук Ш.У. Галієв.

Отримані результати теоретичних досліджень розкрили нові перспективи для
створення інженерних методів оцінювання сучасних конструкцій, занурених
у рідину або тих, що містять її, за інтенсивного імпульсного впливу
навантажень, а також нових технологій імпульсної обробки металів.
Монографія Ш.У.Галієва, присвячена питанням не-

лінійної взаємодії деформівних тіл із рідиною, було опубліковано в 1977
р., а в 1980 р. видано в США.

Освоєння великих глибин Світового океану вимагало розвитку досліджень
властивостей матеріалів в умовах всебічного гідростатичного стиснення. З
початку 70-х років велика увага в Інституті приділяється дослідженням
конструкційної міцності скла і ситалів, можливостям використання скла
для виготовлення конструкційних елементів під час занурення їх на
глибину 10 тис. м, в яких реалізувалися б його властивості високої
опірності стиску; розвитку розрахункових методів визначення
напружено-деформованого стану складних конструктивних елементів із
використанням ЕОМ, розробці методів і програм чисельного моделювання їх
просторового напружено-деформованого стану, а також розробці методів і
програм чисельного моделювання їх просторового напружено-деформованого
стану.

Під керівництвом Г.С.Писаренка співробітниками Інституту Ю.М. Родічевим,
К.К. Амельяновичем, Г.М. Охрименком, Ю.І. Козубом, І.І. Дячковим та ін.
було розроблено наукові засади конструювання глибоководних апаратів зі
скла, ситалів і кераміки. Отримані результати досліджень зі створення
конструкцій високої питомої жорсткості та міцності в умовах зовнішнього
гідростатичного тиску за невеликої їх вартості відкрили широкі
перспективи для використання цих матеріалів у народному господарстві.

У відділі математичного моделювання задач міцності, керованому до 1986
р. докт. техн. наук А.Л. Квіткою. Квіткою, розроблено та впроваджено
пакети прикладних програм для дослідження напружено-деформованого стану
плоских і просторових конструктивних елементів, оцінювання їхньої
міцності та довговічності з урахуванням нестабільності та розкиду
властивостей матеріалів та інших чинників, які діють у реальних умовах
експлуатації конструкцій (Е.С. Уманський, А.Л. Квітка, П.П. Ворошко,
С.В. Кобельський, А.Ю. Чирков та ін.). У наступні роки зусилля
співробітників відділу, очолюваного докт. техн. наук П.П. Ворошком, були
спрямовані на розроблення змішаних варіаційних формулювань сучасних
чисельних методів розв\'язування просторових крайових задач
термопружності, термопластичності та механіки руйнування.

Найповніше результати дослідження міцності матеріалів та елементів
конструкцій в екстремальних умовах представлені у двотомній монографії
ГС. Писаренка, А.Л. Квітки, І.А. Козлова, А.Я. Красовського, А.А.
Лебедєва, В.В. Матвєєва, М.В. Новікова, Г.М. Третьяченка, В.Т. Трощенка,
Е.С. Уманського \"Міцність матеріалів та елементів конструкцій в
екстремальних умовах\", яку в 1982 р. удостоєно Державною премією СРСР у
галузі науки і техніки.

Про успіхи колективу Інституту проблем міцності свідчить висока оцінка
його діяльності, дана відомими вченими - академіками М.В. Келдишем, Б.Є.
Патоном, О.А. Барміним, А.П. Виноградовим, А.Ю. Ішлінським, М.Д.
Кузнєцовим, В.В. Новожиловим, І.Ф. Образцовим, Ю.М. Работновим, Л.І.
Сєдовим, В.В. Струмінським, Ю.А. Митропольським та іншими, а також
зарубіжними вченими.

## **ІНСТИТУТ СЬОГОДНІ**

До 1971 р. структура Інституту не зазнавала суттєвих змін. У період з
1971 р. по 2003 р. у структурі наукових відділів\
відбулися зміни, зумовлені необхідністю розвитку пріоритетних наукових
напрямів діяльності Інституту. Низку наукових відділів було
розформовано, створено нові відділи, уточнено тематику наукових
досліджень створених раніше відділів.

У період з 1966 р. по 1988 р. директором Інституту був його засновник
Г.С. Писаренко. Відзначаючи велику роль у створенні та розвитку
Інституту видатного вченого в галузі міцності, засновника та
багаторічного першого директора Інституту академіка НАН України Г.С.
Писаренка, а також з огляду на його особистий внесок у прогрес
вітчизняної науки, Президія НАН України своєю постановою № 248 від
23.10.2002 р. присвоїла Інституту проблем міцності ім\'я Г.С. Писаренка.

В.Т. Трощенко був заступником директора Інституту з наукової роботи
(1966-1988 рр.), заступниками директора Інституту з наукової роботи були
також М.В. Новіков (1968-1977 рр.) і В.В. Матвєєв (1977-1988 рр.).

З 1988 р. Інститут очолює акад. НАН України В.Т. Трощенко. Засновник
Інституту акад. НАН України Г.С. Писаренко з 1988 р. був Радником
Президії НАН України, з 1992 - Почесним директором Інституту.

Заступниками директора Інституту з наукової роботи в період з 1988 р. до
1999 р. були В.А. Стрижало та В.А. Борисенко; з 1999 р. до теперішнього
часу заступниками директора Інституту з наукової роботи є П.П. Лєпі-хін
та В.В. Харченко. Вченим секретарем Інституту з моменту його заснування
до теперішнього часу є Р.І. Куріат.

У підрозділах Інституту працює 390 осіб, зокрема власне в Інституті 300
і в СКТБ 90 осіб. Наукових співробітників - 115, у тому числі 2 акад.
НАН України (В.Т. Трощенко, О.О. Лебедєв), 3 чл.-кор. НАН України (В.В.
Матвєєв, А.Я. Красовський, В.А. Стрижало), 35 докторів, 70 кандидатів
наук. В аспірантурі Інституту навчається 18 аспірантів.

В Інституті функціонують такі відділи:

відділ механіки конструкційних матеріалів (зав. відділом - докт.
фіз.-мат. наук П.П. Лепіхін);

відділ міцності матеріалів та елементів конструкцій за кріогенних
температур (зав. відділом - чл.-кор. НАН України В.О. Стрижало);

відділ повзучості та тривалої міцності (зав. відділом - докт. техн. наук
В.В. Кривенюк);

відділ фізичних основ міцності та руйнування (зав. відділом - докт.
техн. наук І.В. Ориняк);

відділ міцності елементів конструкцій з функціональними покриттями (зав.
відділом - докт. техн. наук, проф. Л.В. Кравчук);

відділ коливань і вібраційної надійності (зав. відділом - чл.-кор. НАН
України В.В. Матвєєв);

відділ високочастотних методів дослідження міцності та дефектності
матеріалів (зав. відділом - докт. техн. наук Г.Г. Писаренко);

відділ чисельних та експериментальних методів дослідження конструкційної
міцності (зав. відділом - докт. техн. наук В.В. Харченко);

відділ втоми і термовтоми матеріалів (зав. відділом - акад. НАН України
В.Т. Трощенко);

відділ міцності та руйнування при ударному та імпульсному навантаженні
(зав. відділом - докт. техн. наук, проф. Г.В. Степанов);

відділ коливань у роторних системах (зав. відділом - докт. техн. наук
А.П. Зіньковський).

В Інституті функціонує також науково-технічний відділ міцності
конструкцій із крихких матеріалів (зав. відділом - канд. техн. наук Ю.М.
Родичев).

Нині в Інституті проводяться дослідження за такими науковими напрямами,
затвердженими постановою Президії НАН України № 249 від 23.10.2002 р:

граничний стан і критерії міцності матеріалів і конструкцій;

розрахункові та експериментальні методи дослідження
напружено-деформованого стану;

механіка руйнування і живучість конструкцій;

коливання неконсервативних механічних систем.

Розвиток цих наукових напрямів охоплює дослідження граничного стану та
критеріїв міцності елементів конструкцій енергетичного і транспортного
машинобудування, авіаційної та ракетно-космічної техніки, теплової й
атомної енергетики, які працюють в екстремальних умовах; цілісності й
живучості матеріалів та конструкцій з тріщиноподібними дефектами під час
статичного й циклічного термомеханічного навантажень; вібраційної
надійності механічних систем; розроблення методів розрахунку й
дослідження напружено-деформованого стану і міцності елементів
конструкцій; розроблення методів розрахунку та дослідження
напружено-деформованого стану.

Практична спрямованість досліджень Інституту в останні роки дещо
змінилася. Якщо раніше результати досліджень Інституту були зосереджені
на науково-технічному супроводі створюваних нових конструкцій у ракетній
і космічній техніці, авіадвигунобудуванні, то наразі результати
досліджень зосереджені, здебільшого, на оцінці залишкового ресурсу й
обґрунтуванні можливостей безпечної подальшої експлуатації устаткування
атомної й теплової енергетики, магістральних нафто-, газо- і
продуктопроводів, нафтопереробних і хімічних заводів, залізничного
транспорту тощо.

Для доведення результатів завершених наукових досліджень до практичного
використання, з метою активізації їх впровадження в різні сфери
діяльності.

галузі промисловості в період з 1992 р. по 2000 рр. за участю Інституту
створено низку науково-виробничих структур:

у 1992 р. - асоціація \"Надійність машин і споруд\", основним напрямом
діяльності якої є координація наукових досліджень у галузі забезпечення
надійності та довговічності машин і споруд, а також проведення власних
науково-дослідних робіт у цій галузі (президент - акад. НАН України В.Т.
Трощенко, генеральний директор - СВ. Романов);

у 1998 р. - центр механічних випробувань і сертифікації матеріалів та
елементів конструкцій, основним напрямом діяльності якого є проведення
механічних випробувань матеріалів і конструкцій в умовах
температурно-силового навантаження та впливу інших фізичних факторів для
визначення механічних характеристик матеріалів і несучої здатності
елементів конструкцій (керівник - докт. техн. наук В.В. Харченко);

у 2000 р. - випробувальна лабораторія технічної діагностики, яка
проводить технічний огляд і технічну діагностику, комплексне обстеження
технологічного устаткування під час його виготовлення, монтажу, ремонту,
реконструкції та експлуатації; виконує розрахунки на міцність, прогнозує
ресурс, визначає строки безпечної експлуатації, виходячи з
індивідуального технічного стану об\'єктів із вичерпаним розрахунковим
ресурсом (керівник - канд. техн. наук С.З. Стасюк).

Крім цього, Інститут вишукує додаткові кошти для наукових досліджень за
своєю тематикою за рахунок різноманітних міжнародних фондів і грантових
програм: INTAS, Copernicus, INCO - Copernicus, TASIS, УНТЦ, НАТО.

Так, у 1994-1999 рр. виконували проекти за програмою 1NTAS: спільно з
університетами м. Лімож (Франція) і м. Осло (Норвегія); спільно з КБ ім.
O.K. Антонова, м.Київ (Україна), Інститутом фізики твердого тіла ім.
Е.Шмідта Австрійської академії наук, м. Леобен. Антонова, м. Київ
(Україна), Інститутом фізики твердого тіла ім. Е. Шмідта Австрійської
академії наук, м. Леобен, Імперським коледжем Королівського
співтовариства Великої Британії, м. Лондон; спільно з університетами м.
Метц і м. Лілль (Франція), Університетом м. Кайзерлауфен (Німеччина) та
Інститутом проблем машиновіделення РАН м. Москва (Росія).

За програмою INCO-Copernicus у 1997-1999 рр. здійснюється великий проєкт
\"Розроблення комп\'ютерної системи для забезпечення безаварійної
експлуатації нафтогазопроводів, що пролягають на території Білорусі,
України та Угорщини\"; на цей час завершено розпочаті в 2000 р. (разом з
Інститутом проблем матеріалознавства ім. І.Н.Францевича НАН України)
роботи по ламінарних ламінарно-градієнтних керамічних композитах на
основі нітриду кремнію для інженерного використання. І.М.Францевича НАН
України) роботи з ламінарних і функціонально-градієнтних керамічних
композитів на основі нітриду кремнію для інженерного використання.

За програмою TACIS у 1998-2001 рр. виконували спільно з ТЕХА-ТОМ\'ом
(Іспанія) проєкт з оцінки залишкового ресурсу корпусів атомних реакторів
типу ВВЕР.

Прикладом великого багатостороннього співробітництва є здійснення
Інститутом міжнародного регіонального проекту ТАРЕГ 2.01/00

\"Аналіз радіаційного окрихчування для корпусів реакторів ВВЕР 1000 і
440/213 з акцентом на оцінку їхньої конструкційної цілісності\" за
участю фахівців Інституту енергії Спільного дослідницького центру ЄС
(Нідерланди), РНЦ \"Курчатовський інститут\", ЦНДІКМ \"Прометей\", ДКБ
\"Гідропрес\" (Росія), Інституту ядерних досліджень НАН України та
асоціації \"Надійність машин і споруд\" (Україна).

По лінії Українського науково-технологічного центру наразі виконуються
роботи з оцінювання небезпеки тріщини у великогабаритних пластинах і
оболонках в умовах двовісного навантаження (спільно з низкою
дослідницьких центрів Нідерландів, Бельгії, Великої Британії, Німеччини,
Австрії, США, Франції).

Координацію наукових досліджень, апробацію та експертизу нових
науково-дослідних робіт, що виконуються науковими відділами Інституту,
здебільшого здійснюють наукові семінари: загальноінститутський (керівник
- акад. НАН України В.Т. Трощенко) та тематичні. Навколо них формуються
і розвиваються наукові школи за такими напрямами:

статична міцність (керівник - акад. НАН України О.О. Лебедєв);

втома, термовтома та механіка руйнування (керівник - чл.-кор. НАН
України В.О. Стрижало) ;

високотемпературна міцність конструкційних матеріалів (керівник - докт.
техн. наук, проф. Л.В. Кравчук);

коливання, хвильові процеси та імпульсне навантаження (керівник -
чл.-кор. НАН України В.В. Матвєєв).

Низка робіт співробітників Інституту в період 1990-2003 рр. були
удостоєні Державних премій України в галузі науки і техніки, премій НАН
України імені видатних учених.

***Державної премії України в галузі науки і техніки:***

у 1993 р. - В.А. Борисенко, Л.В. Кравчук, B.C. Дзюба, Б.А. Грязне, Е.А.
Ескін, В.К. Харченко, Г.Н. Третяченко - за цикл робіт у галузі
ракетно-космічної техніки;

у 1997 р. - В.Т. Трощенко, О.О. Лебедєв, А.Я. Красовський, В.А.
Стрижало, В.В. Покровський, Ф.Ф. Гігіняк, В.П. Ламашевський, Б.І.
Ковальчук - за цикл робіт зі створення нових методів оцінювання міцності
та довговічності елементів конструкцій сучасної техніки та розроблення
на їх основі нормативних документів;

у 2001 р. - Б.О. Ляшенку - за розробку теоретичних основ і впровадження
нових високопродуктивних технологій, що підвищують ресурс і надійність
роботи деталей і вузлів двигунів.

***Премії ім. О.М. Динника НАН України. О.М. Динника НАН України:***

у 1993 р. - Г.В. Степанов - за цикл робіт з дослідження міцності
матеріалів при імпульсному навантаженні;

у 1996 р. - Г.М. Третьяченку, Б.С. Карпіносу, В.Г. Барилу - за цикл
робіт \"Термічна втома матеріалів при нерівноважних термодинамічних
станах\".

***Премії ім. М.К. Янгеля НАН України. М.К. Янгеля НАН України:***

у 1990 р. - В.А.Борисенку, В.К.Харченку - за роботи в галузі
ракетно-космічної техніки;

у 2000 р. - Л.В. Кравчук, Р.І. Куріат - за цикл робіт \"Методи і
результати дослідження несучої здатності теплозахисних і жароміцних
покриттів елементів конструкцій аерокосмічної техніки в умовах
інтенсивних теплових потоків\".

***Премії ім. С.П. Тимошенка НАН України. С.П. Тимошенка НАН України:***

у 2003 р. - О.О. Лебедєв, М.Г. Чаусов - за цикл робіт \"Процеси
деформування матеріалів і граничні стани елементів конструкцій в умовах
складного навантаження\".

***Премії Президента України для молодих учених удостоєні:***

у 2003 р. - Є.О. Задворний, О.В. Кононученко та С.А. Радченко за цикл
робіт \"Методи і результати дослідження міцності та довговічності
елементів конструкцій з тріщинами\".

За час функціонування Інституту співробітники підготували та видали 98
монографій, 12 довідників і довідкових посібників, 55 збірників наукових
праць, 20 науково-популярних видань, близько 200 препринтів, близько
8000 статей і тез, отримано 680 авторських свідоцтв на винаходи та
патентів. Захищено 60 докторських і 350 кандидатських дисертацій.

З 1956 р. Інститут регулярно проводить науково-технічні наради та
конференції, зокрема міжнародні, з різних аспектів міцності матеріалів
та елементів конструкцій:

з питань розсіювання енергії при коливаннях механічних систем (16
конференцій);

з різних питань статичної, циклічної та динамічної міцності матеріалів і
конструктивних елементів за високих і низьких температур (12 нарад і
конференцій);

з методів оцінки міцності елементів турбомашин (7 нарад);

з питань міцності матеріалів і елементів конструкцій при звукових і
ультразвукових частотах навантаження (6 конференцій);

з питань міцності матеріалів і елементів конструкцій за складного
напруженого стану, методів дослідження міцності матеріалів і несучої
здатності конструктивних елементів (9 нарад і конференцій);

з міцності матеріалів і елементів конструкцій при імпульсному
навантаженні, з питань механіки руйнування і критеріїв міцності (16
нарад і конференцій).

У період з 1981 р. по 2004 р. Інститутом проведено міжнародні форуми,
серед яких:

з утоми матеріалів (1981, 1991);

з міцності матеріалів і елементів конструкцій при звукових і
ультразвукових частотах навантаження (1984);

з механіки руйнування (1993);

з динаміки роторних систем (1998);

з оцінки та обґрунтування продовження ресурсу елементів конструкцій
(2000);

з міцності та руйнування матеріалів і елементів конструкцій при
імпульсному навантаженні (2001);

з проблем динаміки та міцності в газотурбобудуванні (2001, 2004);

з наукових основ підвищення довговічності та ресурсу корпусів атомних
реакторів (нарада робочої групи експертів країн НАТО і фахівців країн
СНД); (2002 р.);

з трибофатики (2002 р.);

з конструкційної міцності матеріалів і ресурсу обладнання АЕС (2003 р.).

Загалом за час функціонування Інституту, починаючи з 1966 р., проведено
79 наукових форумів.

Інститут 1985 р. визначено постановою Президії НАН України базовою
науковою установою для підготовки фахівців Національного технічного
університету України \"Київський політехнічний інститут\" за
спеціальністю \"Динаміка і міцність машин\". З 1988 р. при Інституті
функціонує кафедра цільової підготовки спеціалістів з числа студентів
цього університету, з 2002 р. - філія кафедри механіки Національного
авіаційного університету для підготовки спеціалістів вищої кваліфікації
(магістрів, кандидатів і докторів наук) за пріоритетними напрямами науки
і техніки.

Інститут постійно дбає про поповнення колективу науковою молоддю. Молоді
наукові співробітники та фахівці Інституту систематично, починаючи з
1994 р., завойовують за підсумками конкурсу щорічно 2 стипендії
Президента України та 3 стипендії НАН України. У період з 1994 р. по
1999 р. молоді вчені Інституту отримали 5 стипендій МОН України,
вибороли 3 гранти МААН.

Для активізації наукової діяльності молодих наукових співробітників з
1999 р. встановлювалися щорічні стипендії дирекції Інституту, з 2001 р.
встановлено 3 щорічні премії ім. акад. НАН України Г.С. Писаренка для
молодих учених Інституту.

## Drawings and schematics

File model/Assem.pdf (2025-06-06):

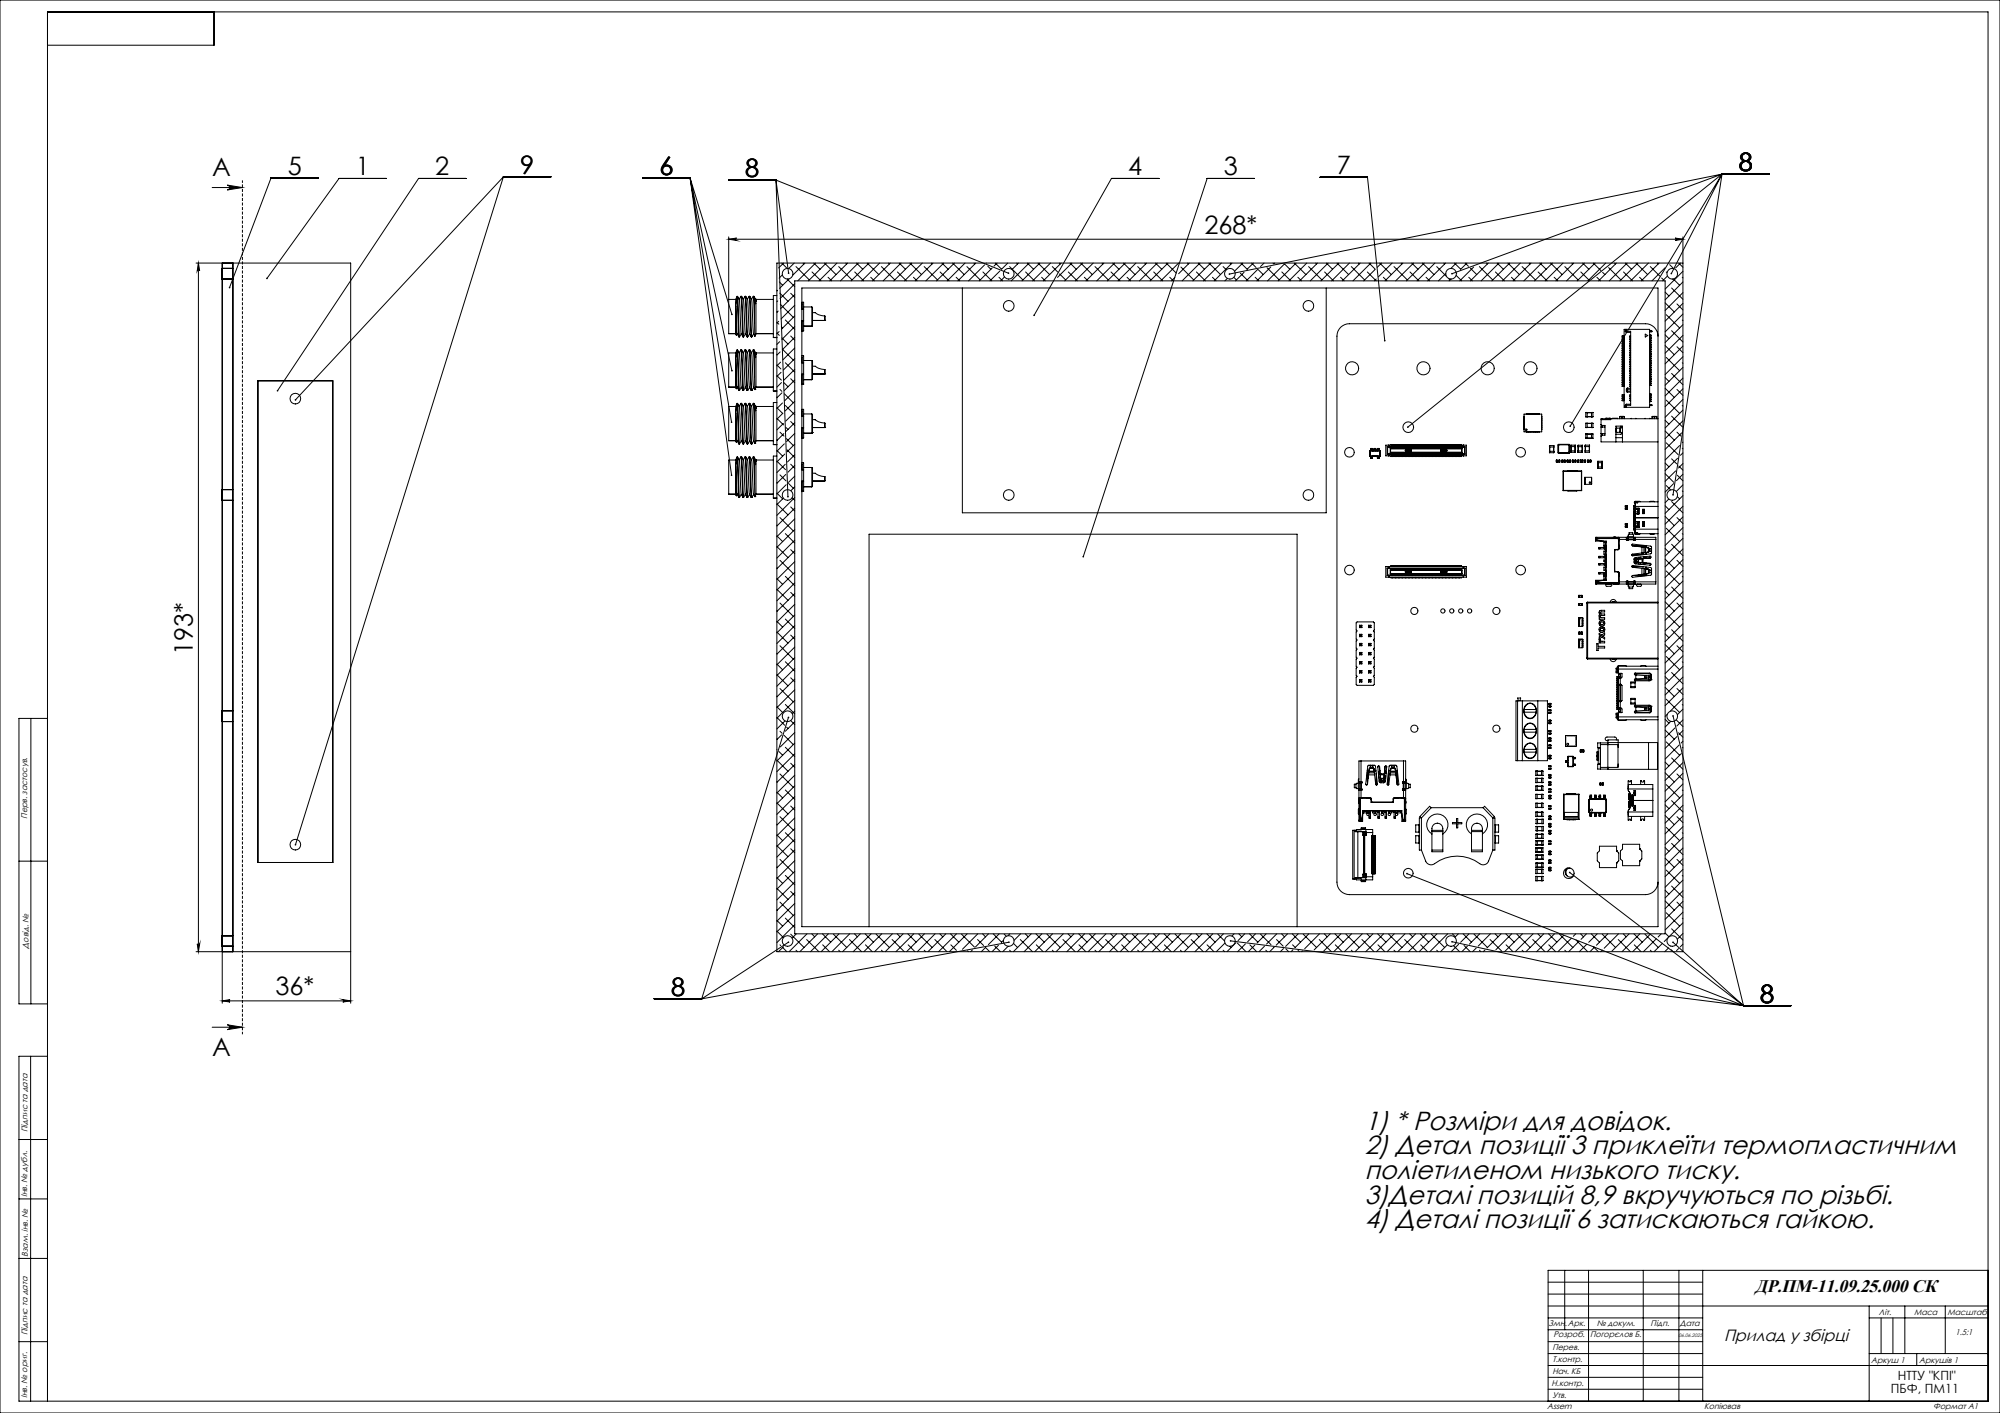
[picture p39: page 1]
Копіював; Формат А1

Інв. № ориг. Підпис та дата Взам. інв. № Інв. № дубл. Підпис та дата Довід. № Перв. застосув.

1) * Розміри для довідок.
2) Детал позиції 3 приклеїти термопластичним
поліетиленом низького тиску.
3)Деталі позицій 8,9 вкручуються по різьбі.
4) Деталі позиції 6 затискаються гайкою.

Літ. | Маса | Масштаб

Змн.Арк. | № докум. | Підп. | Дата | | | | | 1.5:1 Прилад у збірці
Розроб. | Погорєлов Б. | | 06.06.2025
Перев.
Т.контр. | | | | Аркуш 1 | Аркушів 1
Нач. КБ | | | | НТТУ "КПІ" ПБФ, ПМ11
Н.контр.
Утв.

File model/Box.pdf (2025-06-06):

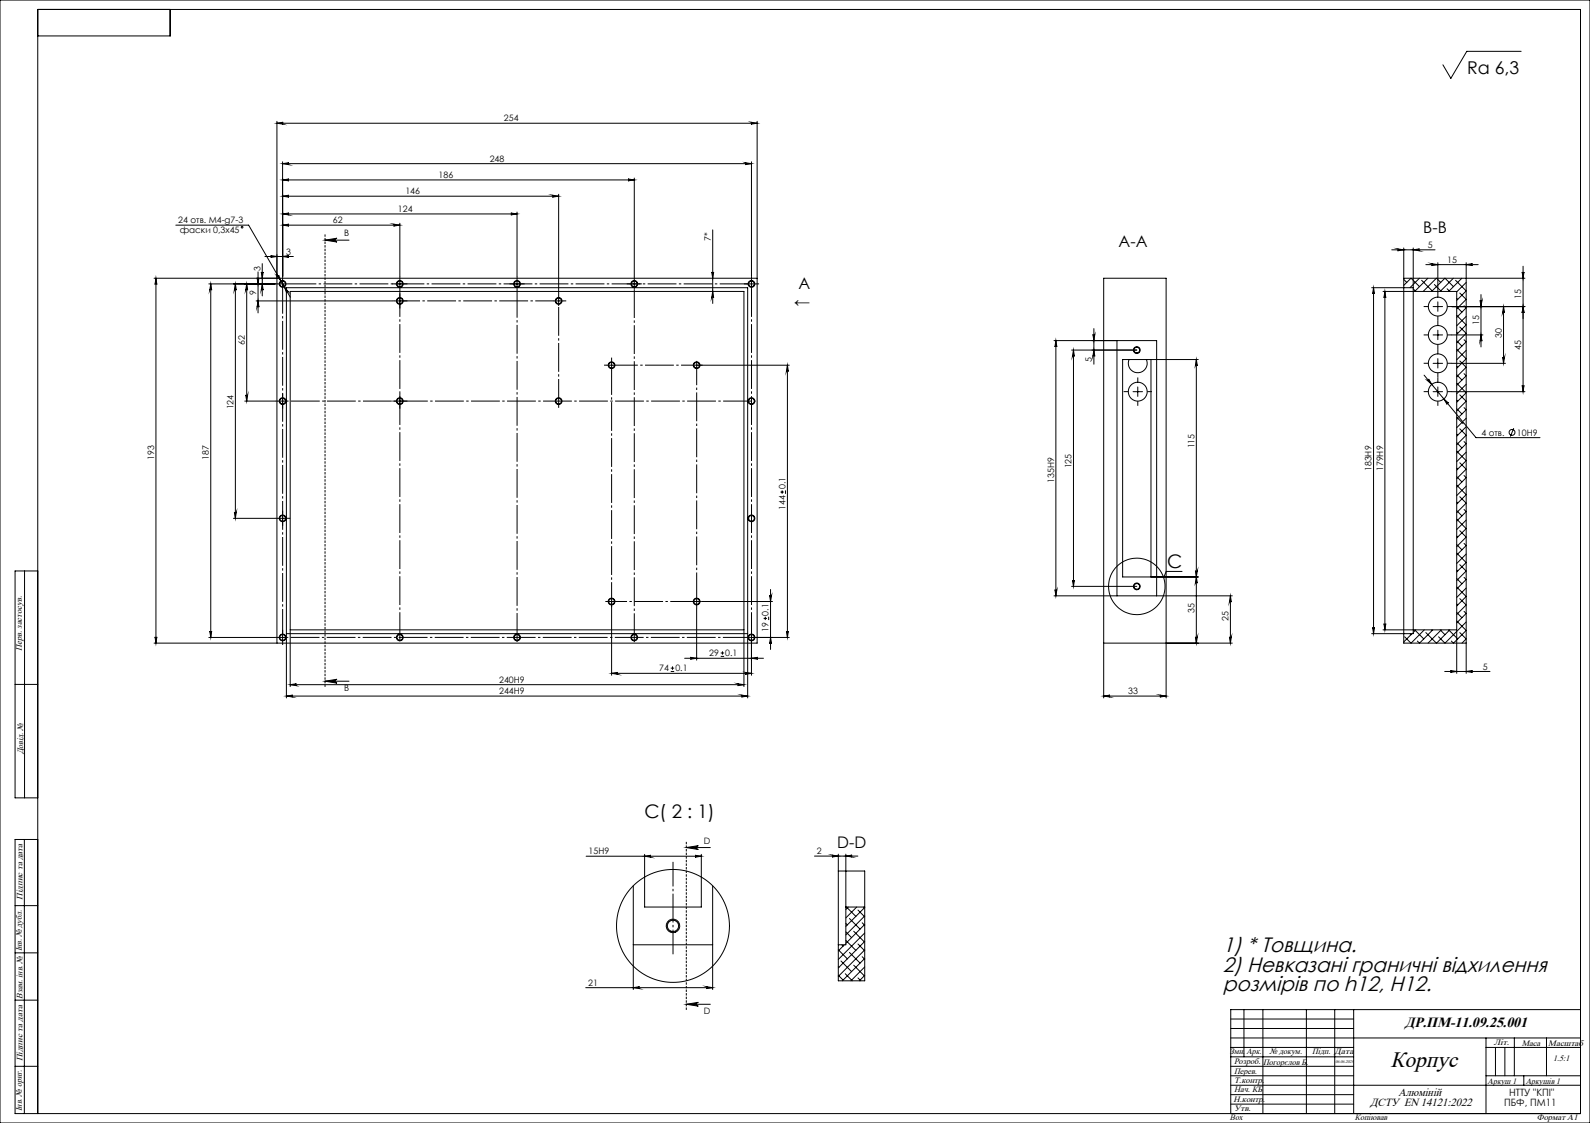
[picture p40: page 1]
24 отв. М4-g7-3; 4 отв. 10H9; фаски 0,3х45; 1.5:1 Погорєлов Б.; Корпус; Копіював; Формат А1; Змн. Арк.; № докум.; Підп. Дата

Інв. № ориг. Підпис та дата Взам. інв. № Інв. № дубл. Підпис та дата Довід. № Перв. застосув.

1) * Товщина.
2) Невказані граничні відхилення
розмірів по h12, H12.

Літ. | Маса | Масштаб

Розроб. | 06.06.2025
Перев.
Т.контр. | | | Аркуш 1 | Аркушів 1
Нач. КБ | | Алюміній ДСТУ EN 14121:2022 | НТТУ "КПІ" ПБФ, ПМ11
Н.контр.
Утв.

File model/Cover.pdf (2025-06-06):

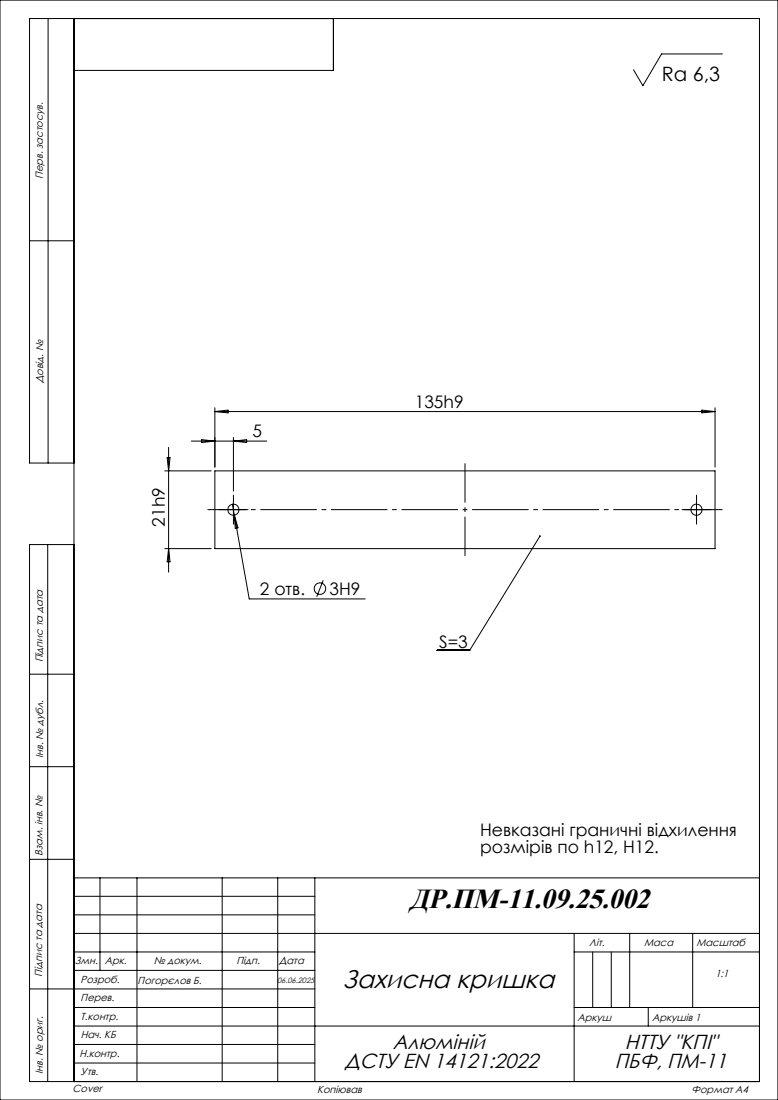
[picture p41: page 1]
2 отв. 3H9; 1:1 Розроб.; Погорєлов Б.; Захисна кришка; Копіював; Формат А4

Довід. № Перв. застосув.

Підпис та дата Інв. № дубл. Взам. інв. № Підпис та дата Інв. № ориг.

Невказані граничні відхилення
розмірів по h12, H12.

Літ. | Маса | Масштаб

Змн. Арк. | № докум. | Підп. | Дата

Перев.
Т.контр. | | | | Аркуш | Аркушів 1
Нач. КБ | | | Алюміній ДСТУ EN 14121:2022 | НТТУ "КПІ" ПБФ, ПМ-11
Н.контр.
Утв.

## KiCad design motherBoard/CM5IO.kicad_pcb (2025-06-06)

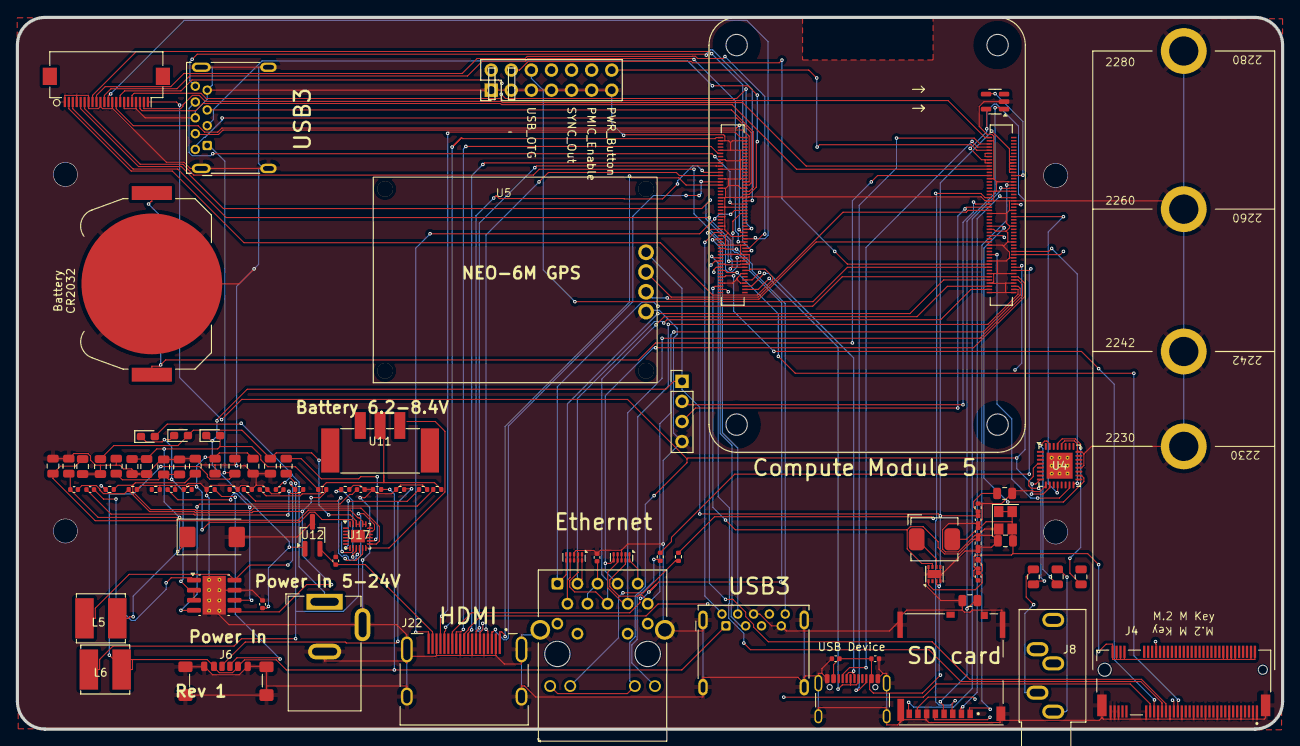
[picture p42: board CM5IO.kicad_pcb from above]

Board: 4 copper layers, 160.0 x 90.0 mm, 88 parts (0 on the bottom side), 124 nets.

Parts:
BT1: Battery_Cell; BatteryHolder_Keystone_3034_1x20mm
C1, C9, C10, C12, C13, C18, C19, C57, C58: 100n; C_0402_1005Metric
C5, C6, C7, C8, C14, C21, C47, C49, C51, C54, C55, C56, C62, C63, C64, C65, C66, C67: 10u; C_0805_2012Metric
C11: 4.7nF; C_0402_1005Metric
C20: 100uF; CP_EIA-7343-31_Kemet-D
C34, C37, C39: 10u 35v; C_0805_2012Metric
C36: 100n 100v; C_0402_1005Metric
C59, C61: nf; C_0402_1005Metric
C60: 1.2nF; C_0402_1005Metric
D4, D5, D6: D_Zener; D_0603_1608Metric_Pad1.05x0.95mm_HandSolder
J1, J3: USB3_A; USB3_A_Molex_48393-001
J2: Conn_02x07_Odd_Even; PinHeader_2x07_P2.54mm_Vertical
J4: Bus_M.2_Socket_M; M.2 M Key socket
J5: Conn_01x22; Hirose_FH12-22S-0.5SH_1x22-1MP_P0.50mm_Horizontal
J6: USB_C; USB_C_Receptacle_GCT_USB4135-GF-A_6P_TopMnt_Horizontal
J7: Micro_SD_Card_Det; SDCARD_MOLEX_503398-1892
J8: AudioJack; Jack_3.5mm_CUI_SJ1-3535NG_Horizontal
J11: USB_C; USB_C_Receptacle_GCT_USB4105-xx-A_16P_TopMnt_Horizontal
J19: Barrel_Jack; BarrelJack_GCT_DCJ200-10-A_Horizontal
J22: 690-019-298-412; EDAC 690-019-298-412
L1: 2.2uH; L_Bourns_SRP5030CC
L5, L6: SRN6045TA-3R3Y; L_Bourns_SRN6045TA
Module1: ComputeModule5-CM5; Raspberry-Pi-5-Compute-Module
R2, R3: 470R; R_0402_1005Metric
R9, R16, R28: 2.2K 1%; R_0402_1005Metric
R10, R22, R23, R24, R30, R31: 10R; R_0402_1005Metric
R14: 100K; R_0402_1005Metric
R15: 10K 1%; R_0402_1005Metric
R25: 20K 1%; R_0402_1005Metric
R27: 12K 1%; R_0402_1005Metric
R34: 12K; R_0402_1005Metric
R35: 10K; R_0402_1005Metric
R37: 0.5K; R_0402_1005Metric
R38: 1K; R_0402_1005Metric
R39: 18K; R_0402_1005Metric
U1, U2: TPD4EUSB30; USON-10_2.5x1.0mm_P0.5mm
U3: MagJack-A70-112; TRJG0926HENL
U4: WM8960; QFN-32-1EP_5x5mm_P0.5mm_EP3.3x3.3mm_ThermalVias
U5: NEO-6M GPS
U6: Touch; PinHeader_1x04_P2.54mm_Vertical
U7: 32.768KHZ; Crystal_SMD_3225-4Pin_3.2x2.5mm
U8: AP3441SHE-7B; DFN-8-1EP_2x2mm_P0.5mm_EP1.05x1.75mm
U11: BK-18650-PC4; TerminalBlock_Phoenix_PTSM-0,5-3-2,5-V-SMD_1x03-1MP_P2.50mm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
U12: RT9742SNGV; TSOT-23_HandSoldering
U16: AP64501SP-13; SOIC-8-1EP_3.9x4.9mm_P1.27mm_EP2.95x4.9mm_Mask2.71x3.4mm_Th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
U17: IP2326; QFN-24-1EP_3x3mm_P0.4mm_EP1.75x1.6mm
U18: RT9742GGJ5; SOT-23-5

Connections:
/+1.8v: Module1.88 (+1.8v_(Output)), Module1.90 (+1.8v_(Output))
/+3.3v: J5.22, Module1.84 (+3.3v_(Output)), Module1.86 (+3.3v_(Output)), U3.15 (LEDY_A), U3.17 (LEDG_A), U4.8 (DCVDD), U4.10 (DBVDD), U18.5 (IN)
/+5v: C6.1, C9.1, C10.1, C12.1, C18.1, D4.1 (K), J11.A4 (VBUS), J11.A9 (VBUS), J11.B4 (VBUS), J11.B9 (VBUS), Module1.77 (+5v_(Input)), Module1.79 (+5v_(Input)), Module1.81 (+5v_(Input)), Module1.83 (+5v_(Input)), Module1.85 (+5v_(Input)), Module1.87 (+5v_(Input)), R9.2, U5.1 (VCC), U6.1 (VCC), U8.3 (VIN), U12.1 (IN)
/+12v: C34.1, C37.1, C39.1, D5.1 (K), D6.1 (K), U16.2 (VIN), U16.3 (EN)
/CAM_GPIO1: J5.18, Module1.100 (CAM_GPIO1)
/CC1: J11.A5 (CC1), Module1.94 (CC1)
/CC2: J11.B5 (CC2), Module1.96 (CC2)
/DPHY0_C_N: J5.8, Module1.127 (MIPI0_C_N)
/DPHY0_C_P: J5.9, Module1.129 (MIPI0_C_P)
/DPHY0_D0_N: J5.2, Module1.115 (MIPI0_D0_N)
/DPHY0_D0_P: J5.3, Module1.117 (MIPI0_D0_P)
/DPHY0_D1_N: J5.5, Module1.121 (MIPI0_D1_N)
/DPHY0_D1_P: J5.6, Module1.123 (MIPI0_D1_P)
/DPHY0_D2_N: J5.11, Module1.133 (MIPI0_D2_N)
/DPHY0_D2_P: J5.12, Module1.135 (MIPI0_D2_P)
/DPHY0_D3_N: J5.14, Module1.139 (MIPI0_D3_N)
/DPHY0_D3_P: J5.15, Module1.141 (MIPI0_D3_P)
/EEPROM_nWP: J2.4, Module1.20 (EEPROM_nWP)
/ETH_LEDG: Module1.17 (Ethernet_nLED2(3.3v)), R2.2
/ETH_LEDY: Module1.15 (Ethernet_nLED3(3.3v)), R3.2
/FB: C11.2, R15.2, R16.1, U8.1 (FB)
/GPIO2: Module1.58 (GPIO2), U6.2 (SDA)
/GPIO3: Module1.56 (GPIO3), U6.3 (SCL)
/GPIO4: Module1.54 (GPIO4), U5.2 (RX)
/GPIO5: Module1.34 (GPIO5), U5.3 (TX)
/GPIO10: Module1.44 (GPIO10), U4.18 (SDA)
/GPIO11: Module1.38 (GPIO11), U4.17 (SCL)
/GPIO18: Module1.49 (GPIO18), U4.12 (BCLK)
/GPIO19: Module1.26 (GPIO19), U4.15 (ADCLRC/GPIO)
/GPIO20: Module1.27 (GPIO20), U4.16 (ADCDAT)
/GPIO21: Module1.25 (GPIO21), U4.14 (DACDAT)
/HDMI0_CEC: J22.13 (CEC), Module1.151 (HDMI0_CEC)
/HDMI0_CK_N: J22.12 (CK-), Module1.190 (HDMI0_CLK_N)
/HDMI0_CK_P: J22.10 (CK+), Module1.188 (HDMI0_CLK_P)
/HDMI0_D0_N: J22.9 (D0-), Module1.184 (HDMI0_TX0_N)
/HDMI0_D0_P: J22.7 (D0+), Module1.182 (HDMI0_TX0_P)
/HDMI0_D1_N: J22.6 (D1-), Module1.178 (HDMI0_TX1_N)
/HDMI0_D1_P: J22.4 (D1+), Module1.176 (HDMI0_TX1_P)
/HDMI0_D2_N: J22.3 (D2-), Module1.172 (HDMI0_TX2_N)
/HDMI0_D2_P: J22.1 (D2+), Module1.170 (HDMI0_TX2_P)
/HDMI0_HOTPLUG: J22.19 (HPD/HEAC-), Module1.153 (HDMI0_HOTPLUG)
/HDMI0_SCL: J22.15 (SCL), Module1.200 (HDMI0_SCL)
/HDMI0_SDA: J22.16 (SDA), Module1.199 (HDMI0_SDA)
/HDMI_5v: C13.1, J22.18 (+5V), U12.2 (OUT)
/M2_3v3: C11.1, C14.1, C19.1, J4.2 (3.3V), J4.4 (3.3V), J4.12 (3.3V), J4.14 (3.3V), J4.16 (3.3V), J4.18 (3.3V), J4.68 (SUSCLK), J4.70 (3.3V), J4.72 (3.3V), J4.74 (3.3V), L1.2, R15.1, U7.1 (EN), U7.3 (Out), U7.4 (VDD)
/PCIE_CLK_N: J4.53 (REFCLKn), Module1.112 (PCIe_CLK_N)
/PCIE_CLK_P: J4.55 (REFCLKp), Module1.110 (PCIe_CLK_P)
/PCIE_PWR_EN: Module1.106 (PCIE_PWR_EN), R14.1, U8.7 (EN)
/PCIE_RX_N: J4.43 (PETp0), Module1.118 (PCIe_RX_N)
/PCIE_RX_P: J4.41 (PETn0), Module1.116 (PCIe_RX_P)
/PCIE_TX_N: J4.49 (PERp0), Module1.124 (PCIe_TX_N)
/PCIE_TX_P: J4.47 (PERn0), Module1.122 (PCIe_TX_P)
/PCIE_nCLKREQ: J4.52 (~CLKREQ), Module1.102 (PCIe_nCLKREQ)
/PCIE_nRST: J4.50 (~PERST), Module1.109 (PCIe_nRST)
/PCIE_nWAKE: J4.54 (~PEWAKE), Module1.104 (PCIE_nWAKE)
/PWR_BUT: J2.14, Module1.92 (PWR_BUT)
/SCL0: J5.20, Module1.80 (SCL0)
/SDA0: J5.21, Module1.82 (SDA0)
/SD_CLK: J7.5 (CLK), Module1.57 (SD_CLK)
/SD_CMD: J7.3 (CMD), Module1.62 (SD_CMD)
/SD_DAT0: J7.7 (DAT0), Module1.63 (SD_DAT0)
/SD_DAT1: J7.8 (DAT1), Module1.67 (SD_DAT1)
/SD_DAT2: J7.1 (DAT2), Module1.69 (SD_DAT2)
/SD_DAT3: J7.2 (DAT3/CD), Module1.61 (SD_DAT3)
/SD_PWR: C5.1, J7.4 (VDD), U18.1 (OUT)
/SD_PWR_ON: Module1.75 (SD_PWR_ON), U18.4 (EN)
/SYNC_OUT: J2.6, Module1.18 (Ethernet_SYNC_OUT(3.3v))
/TRD0_N: Module1.10 (Ethernet_Pair0_N), U2.4 (D2+), U2.7, U3.2 (TRD0-)
/TRD0_P: Module1.12 (Ethernet_Pair0_P), U2.5 (D2-), U2.6, U3.1 (TRD0+)
/TRD1_N: Module1.6 (Ethernet_Pair1_N), U2.2 (D1-), U2.9, U3.6 (TRD1-)
/TRD1_P: Module1.4 (Ethernet_Pair1_P), U2.1 (D1+), U2.10, U3.3 (TRD1+)
/TRD2_N: Module1.9 (Ethernet_Pair2_N), U1.4 (D2+), U1.7, U3.8 (TRD2-)
/TRD2_P: Module1.11 (Ethernet_Pair2_P), U1.5 (D2-), U1.6, U3.7 (TRD2+)
/TRD3_N: Module1.5 (Ethernet_Pair3_N), U1.2 (D1-), U1.9, U3.10 (TRD3-)
/TRD3_P: Module1.3 (Ethernet_Pair3_P), U1.1 (D1+), U1.10, U3.9 (TRD3+)
/USB2_N: J11.A6 (D+), J11.B6 (D+), Module1.103 (USB2_N)
/USB2_P: J11.A7 (D-), J11.B7 (D-), Module1.105 (USB2_P)
/USB3-0-D_N: J3.2 (D-), Module1.136 (USB3-0-D_N)
/USB3-0-D_P: J3.3 (D+), Module1.134 (USB3-0-D_P)
/USB3-0-RX_N: J3.6 (SSRX+), Module1.128 (USB3-0-RX_N)
/USB3-0-RX_P: J3.5 (SSRX-), Module1.130 (USB3-0-RX_P)
/USB3-0-TX_N: J3.9 (SSTX+), Module1.140 (USB3-0-TX_N)
/USB3-0-TX_P: J3.8 (SSTX-), Module1.142 (USB3-0-TX_P)
/USB3-1-D_N: J1.3 (D+), Module1.165 (USB3-1-D_N)
/USB3-1-D_P: J1.2 (D-), Module1.163 (USB3-1-D_P)
/USB3-1-RX_N: J1.6 (SSRX+), Module1.157 (USB3-1-RX_N)
/USB3-1-RX_P: J1.5 (SSRX-), Module1.159 (USB3-1-RX_P)
/USB3-1-TX_N: J1.9 (SSTX+), Module1.169 (USB3-1-TX_N)
/USB3-1-TX_P: J1.8 (SSTX-), Module1.171 (USB3-1-TX_P)
/VBAT: BT1.1 (+), Module1.76 (VBAT)
/VBUS: J1.1 (VBUS), J3.1 (VBUS)
/Vbus: C55.1, J6.A9 (VBUS), J6.B9 (VBUS), L6.2, R22.1, R23.2
GND: BT1.2 (-), C1.2, C5.2, C6.2, C9.2, C10.2, C12.2, C13.2, C14.2, C18.2, C19.2, C20.2, C34.2, C36.2, C37.2, C39.2, C47.2, C49.2, C51.2, C55.2, C56.2, C58.2, C59.2, C60.2, C62.2, C63.2, C64.2, C65.2, C66.1, C67.1, J1.4 (GND), J1.7 (DRAIN), J1.10 (SHIELD), J2.1, J2.3, J2.5, J2.7, J2.9, J2.11, J2.13, J3.4 (GND), J3.7 (DRAIN), J3.10 (SHIELD), J4.1 (GND), J4.3 (GND), J4.9 (GND), J4.15 (GND), J4.21 (GND), J4.27 (GND), J4.33 (GND), J4.39 (GND), J4.45 (GND), J4.51 (GND), J4.57 (GND), J4.71 (GND), J4.73 (GND), J4.75 (GND), J4.M1 (GND2230), J4.M2 (GND2242), J4.M3 (GND2260), J4.M4 (GND2280), J4.S1, J4.S2, J5.1, J5.4, J5.7, J5.10, J5.13, J5.16, J5.19, J6.A12 (GND), J6.B12 (GND), J6.S1 (SHIELD), J7.6 (VSS), J7.11 (SHIELD), J11.A1 (GND), J11.A12 (GND), J11.B1 (GND), J11.B12 (GND), J11.S1 (SHIELD), J19.2, J19.3, J22.2 (D2S), J22.5 (D1S), J22.8 (D0S), J22.11 (CKS), J22.17 (GND), J22.SH1 (SH), J22.SH2 (SH), J22.SH3 (SH), J22.SH4 (SH), Module1.1 (GND), Module1.2 (GND), Module1.7 (GND), Module1.8 (GND), Module1.13 (GND), Module1.14 (GND), Module1.22 (GND), Module1.23 (GND), Module1.32 (GND), Module1.33 (GND), Module1.42 (GND), Module1.43 (GND), Module1.52 (GND), Module1.53 (GND), Module1.59 (GND), Module1.60 (GND), Module1.65 (GND), Module1.66 (GND), Module1.71 (GND), Module1.74 (GND), Module1.98 (GND), Module1.107 (GND), Module1.108 (GND), Module1.113 (GND), Module1.114 (GND), Module1.119 (GND), Module1.120 (GND), Module1.125 (GND), Module1.126 (GND), Module1.131 (GND), Module1.132 (GND), Module1.137 (GND), Module1.138 (GND), Module1.144 (GND), Module1.150 (GND), Module1.155 (GND), Module1.156 (GND), Module1.161 (GND), Module1.162 (GND), Module1.167 (GND), Module1.168 (GND), Module1.173 (GND), Module1.174 (GND), Module1.179 (GND), Module1.180 (GND), Module1.185 (GND), Module1.186 (GND), Module1.191 (GND), Module1.192 (GND), Module1.197 (GND), Module1.198 (GND), R9.1, R14.2, R16.2, R23.1, R28.2, R30.1, R31.1, R34.2, R35.2, R37.2, R38.2, R39.2, U1.3 (GND), U1.8 (GND), U2.3 (GND), U2.8 (GND), U3.19 (SHIELD), U3.20 (SHIELD), U4.9 (DGND), U4.20 (SPKGND2), U4.24 (SPKGND1), U4.28 (AGND), U5.4 (GND), U6.4 (GND), U7.2 (GND), U8.4 (PGND), U8.8 (SGND), U8.9 (PAD), U12.3 (GND), U16.7 (GND), U16.9 (EP), U17.18 (PGND), U17.24 (VBAT_GND), U18.2 (GND)
unnamed: C1.1, U3.4 (CT), U3.5 (CT)
unnamed: C7.2, J8.T
unnamed: C8.2, J8.S
unnamed: C54.1, L6.1, U17.15 (LX), U17.16 (LX), U17.17 (LX)
unnamed: C57.1, R10.2
unnamed: C60.1, R25.2
unnamed: C62.1, C63.1, U17.19 (VSYS), U17.20 (VSYS)
unnamed: C20.1, C47.1, C49.1, C51.1, C61.1, D4.2 (A), L5.2, R27.1
unnamed: C64.1, C65.1, D5.2 (A), U17.21 (VOUT), U17.22 (VOUT)
unnamed: C36.1, D6.2 (A), J19.1
unnamed: J6.A5 (CC1), R30.2
unnamed: J6.B5 (CC2), R31.2
unnamed: R3.1, U3.18 (LEDG_K)
unnamed: R2.1, U3.16 (LEDY_K)
unnamed: C8.1, U4.31 (HEADPHONE_L)
unnamed: C21.1, U4.29 (HEADPHONE_R)
unnamed: C7.1, U4.4 (LINPUT1)
unnamed: L1.1, U8.6 (LX)
unnamed: C57.2, U16.1 (BST)
unnamed: C59.1, R25.1, U16.6 (COMP)
unnamed: C61.2, R27.2, R28.1, U16.5 (FB)
unnamed: C58.1, U16.4 (SS)
unnamed: L5.1, R10.1, U16.8 (SW)
unnamed: C54.2, U17.14 (BST)
unnamed: R39.1, U17.11 (ISET)
unnamed: R34.1, U17.10 (NC)
unnamed: R38.1, U17.7 (TIME_SET)
unnamed: C66.2, C67.2, R24.1, U17.23 (VBATM)
unnamed: C56.1, R22.2, U17.13 (VIN)
unnamed: R35.1, U17.9 (VIN_OVSET)
unnamed: R37.1, U17.8 (VIN_UVSET)

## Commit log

2025-05-09 принципова
    [CM4IOv5-B_Cu.gbr, CM4IOv5-B_Mask.gbr, CM4IOv5-Edge_Cuts.gbr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]
2025-05-09 ReadMee kicad
2025-05-09 принципова imgs
2025-05-14 практика
2025-05-14 приколи з py
2025-05-15 md2 ламає docx для libre office ((
2025-05-19 super fix BladeRF
    [SDR.xlsx]
2025-05-19 CHANGE TREE DIRECTORY
    [Litium.xlsx, SDR.xlsx]
2025-05-22 change kicad
    [CM4IOv5-B_Cu.gbr, CM4IOv5-B_Mask.gbr, CM4IOv5-Edge_Cuts.gbr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]
2025-05-22 fix style, add screenshots KiCAD
2025-05-22 структурна
2025-05-26 y changes
    [SDR.xlsx, tablesDiplom.xlsx]
2025-05-26 pre final
    [56K504-200N5 rev 2.STEP, Assem.SLDASM, AssemBox.SLDASM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]
2025-05-30 electric part xlsx
    [electric_scheme.xlsx]
2025-06-06 windows reorganisation
    [Box.SLDDRW, CM5IO.kicad_pcb, CM5IO.kicad_sch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]
